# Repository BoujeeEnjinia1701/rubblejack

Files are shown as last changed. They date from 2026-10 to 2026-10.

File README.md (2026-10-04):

# RubbleJack

     

**Area:** Situational field hardware · **TRL:** 3 of 9 (proof of concept on paper) · **Value-engineering target:** about $3,500 USD (estimated cost of the constructable design about $5,895 USD) · **Difficulty:** 4 of 5

Turns commodity construction hydraulics into an open spreading, lifting and cutting kit for crews without powered rescue tools.

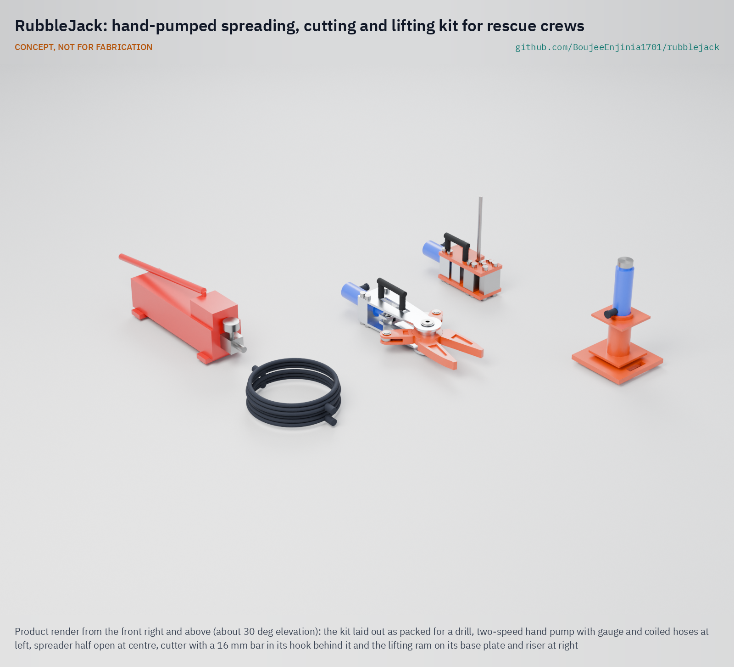
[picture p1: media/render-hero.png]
RubbleJack: hand-pumped spreading, cutting and lifting kit for rescue crews, product render


[Exploded render](media/render-exploded.png) · [Detail render](media/render-detail.png) · [Interactive 3D model](media/viewer.html) · [Concept blueprint (PDF)](media/concept-blueprint.pdf) · [General arrangement (PDF)](cad/drawings/RBJ-DWG-001.pdf) · [Calculations](docs/04-calcs/01-sizing.md) · [Prototype build plan](docs/05-build-plan.md) · [Design decisions](docs/06-design-decisions.md) · [Review note](docs/REVIEW.md)

> **Not certified rescue equipment.** RubbleJack is a TRL 3 concept, not released for fabrication, and not certified to NFPA 1936, NFPA 1960 or EN 13204. See [Safety](#safety).

## Concept rationale

The tools that lift, spread and cut are hydraulic, and the hydraulic parts are the same ones construction and body shops use every day: hand pumps, hoses, rams and standard cylinders. RubbleJack packages commodity construction hydraulics into an open rescue kit: a hand pump, hoses, a lifting ram, and spreader and cutter jaws built onto standard cylinders. A volunteer crew carries it to a collapse and pumps by hand to spread, lift and cut debris off trapped people.

Keeping it open and commodity-based matters because the crews who reach people first are the least equipped. Branded rescue sets are certified and expensive; commodity parts are sold in every town and can be replaced locally. Publishing the jaws, the proof-load data and the limits openly lets crews build, test and repair the kit, and lets them know exactly what it is and is not rated for.

## Burning platform

A review of international search and rescue deployments found that most people rescued after earthquakes are rescued locally, often by relatives and neighbours ([Rom and Kelman, 2020](https://pmc.ncbi.nlm.nih.gov/articles/PMC7745699/)). After the February 2023 earthquake in Turkey, residents dug by hand; in Antakya a woman trying to reach her mother said that if only they could lift the concrete slab they would be able to reach her ([Euronews, 2023](https://www.euronews.com/2023/02/07/we-could-hear-their-voices-digging-with-bare-hands-for-earthquake-survivors)). After the March 2025 earthquake in Myanmar, rescuers in Mandalay said the lack of proper equipment left people trapped and borrowed machinery from private businesses ([Al Jazeera, 2025](https://www.aljazeera.com/news/2025/3/29/lack-of-equipment-stalls-race-to-save-earthquake-survivors-in-myanmar)).

Cost keeps powered tools away from small crews. In Texas, a rural volunteer fire department needed a USD 14,900 state grant to buy three rescue tools ([Texas A&M Forest Service, 2017](https://tfsweb.tamu.edu/?p=12405)). A single battery spreader weighs about 19.5 kg ([Holmatro](https://www.holmatro.com/en/rescue/spreader-psp40)), and even a used hand-pump spreader and cutter sold as a demonstrator for USD 2,595 against a list price of USD 4,988 ([Fenton Fire](https://www.fentonfire.com/equipment/holmatro-hct-3120-hand-pump-spreader-cutter-a1758/)).

## Where it could be used

### By industry

| Industry | Use |
| --- | --- |
| Volunteer and rural fire services | Low-cost spreading, lifting and cutting for collapses and vehicle incidents |
| Community disaster response teams | Neighbourhood kit for the first hours after an earthquake |
| Humanitarian and disaster NGOs | Prepositioned kits and training in earthquake-prone regions |
| Construction and demolition | Freeing workers trapped by collapsed formwork or masonry |
| Mining and quarrying | Lifting and spreading after small rock and structure falls |

### By country or region

| Country or region | Why it matters there |
| --- | --- |
| Turkey | After the 2023 earthquake, families dug with their hands and could not lift slabs to reach trapped relatives ([Euronews, 2023](https://www.euronews.com/2023/02/07/we-could-hear-their-voices-digging-with-bare-hands-for-earthquake-survivors)). |
| Myanmar | Rescue teams in Mandalay reported a lack of proper equipment after the March 2025 earthquake ([Al Jazeera, 2025](https://www.aljazeera.com/news/2025/3/29/lack-of-equipment-stalls-race-to-save-earthquake-survivors-in-myanmar)). |
| United States (rural) | A rural Texas volunteer department relied on a USD 14,900 grant for three rescue tools ([Texas A&M Forest Service, 2017](https://tfsweb.tamu.edu/?p=12405)). |
| Global (earthquake regions) | Most people rescued after earthquakes are rescued locally by relatives and neighbours, not by international teams ([Rom and Kelman, 2020](https://pmc.ncbi.nlm.nih.gov/articles/PMC7745699/)). |

## What sparked the idea

The idea came from reporting after the February 2023 earthquake in Turkey. In Nurdag, a resident said they could hear trapped people's voices calling for help, and in Antakya a woman searching for her elderly mother said that if only they could lift the concrete slab they would be able to reach her ([Euronews, 2023](https://www.euronews.com/2023/02/07/we-could-hear-their-voices-digging-with-bare-hands-for-earthquake-survivors)). The people on the spot had the will and the numbers. What they lacked was a way to move a slab. The hydraulics that can move it are sold in every hardware and body shop.

## Problem

After a building collapse, most trapped people are reached by neighbours and local crews long before specialist teams arrive, but those crews usually have no way to lift, spread or cut concrete. Powered rescue tools cost more than many volunteer departments can pay.

Full problem statement: [docs/01-problem.md](docs/01-problem.md)

## Concept

A rescue kit built from commodity construction hydraulics that a volunteer crew carries to a collapse and pumps by hand to spread, lift and cut debris off trapped people. One two-speed 700 bar hand pump drives three tools, each on its own bought 15 t cylinder, so a tool change is one hose coupler swap:

- **Spreader:** two steel jaw arms on one pin, opened by a crosshead and two links; 49 to 64 kN between the tips, 262 mm opening.
- **Cutter:** a guillotine shear with hardened blades and a hook for the bar; shears 16 mm reinforcing bar, which needs about 105 kN of the cylinder's 142 kN.
- **Lifting ram:** 14.5 t on a 250 mm base plate, 527 mm reach with its riser, always on hardwood cribbing.

The kit packs into four loads of 15.9, 24.8, 22.0 and 23.7 kg. All figures are paper estimates at 700 bar from the calculation note.

Full design precis: [docs/02-concept.md](docs/02-concept.md) · Requirements: [docs/03-requirements.md](docs/03-requirements.md)

## Key components

- Two-speed hand pump, 700 bar, with gauge
- Two 2 m hoses with quick couplers
- Three single-acting 15 t cylinders, one per tool
- Spreader: collar adapter, aluminium frame plates, crosshead, links, two 4340 steel jaw arms, pins
- Cutter: collar adapter, steel plates with a hook, blade carrier, hardened moving and fixed blades, nose block, stop bar
- Lifting ram: high-strength steel base plate, riser block, tilting saddle
- Four carry bags

## Building the prototype

The [prototype build plan](docs/05-build-plan.md) shows how to make each of the eighteen made parts, with a making sketch for each, nine joint close-ups and sixteen assembly steps. The parts are waterjet or laser cut from plate, machined, and for the arms, pins and blades heat treated; the hydraulics are bought. Every tool is proof-loaded on CalRig and crack-checked before any use; the plan is a plan, not yet built.

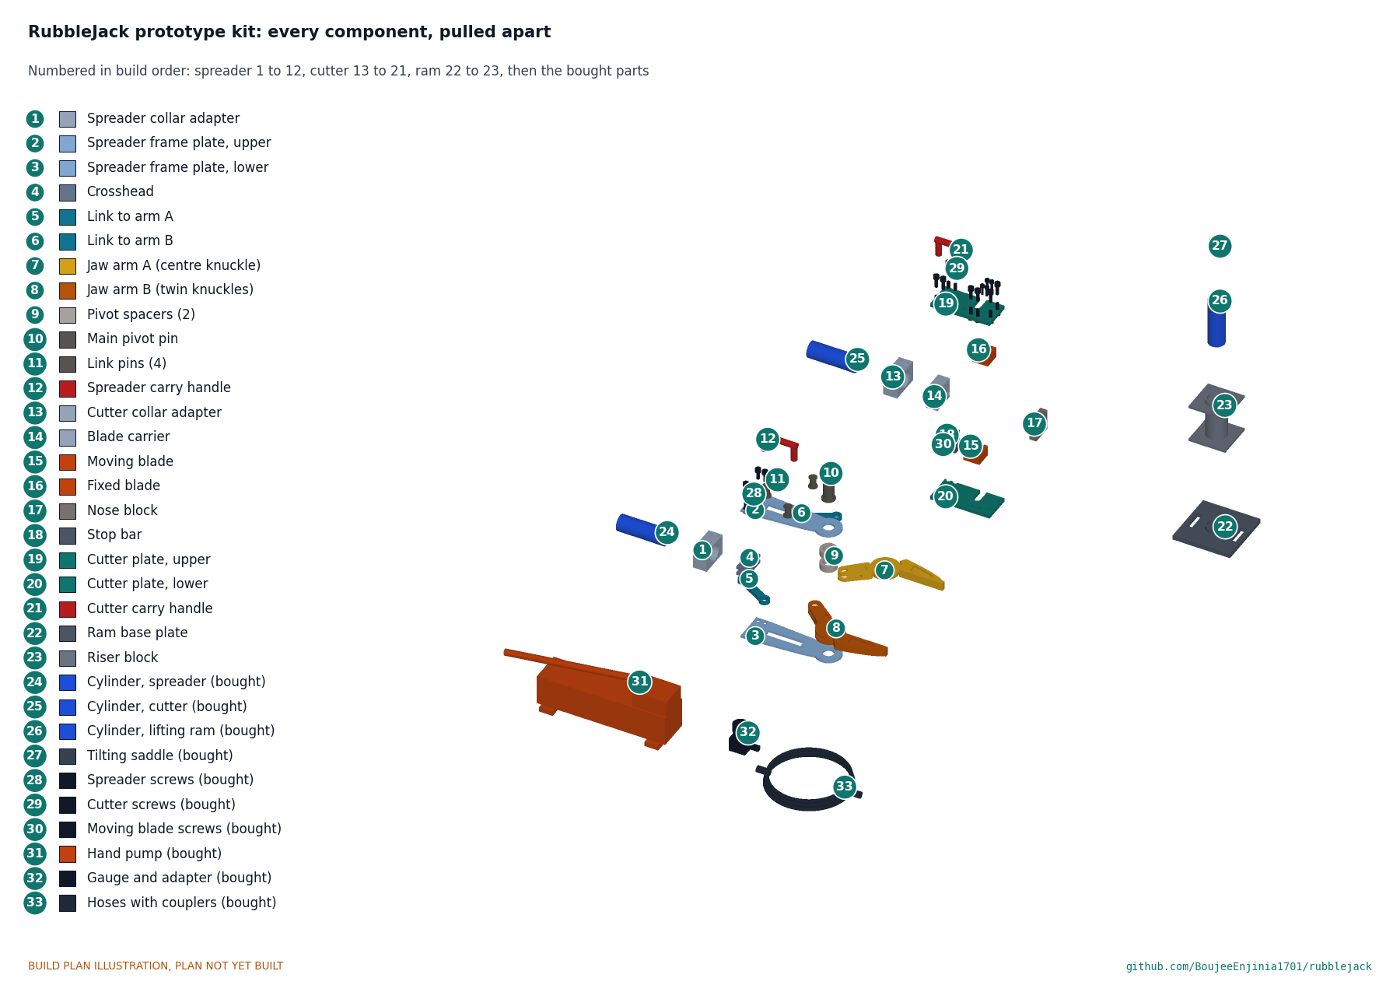
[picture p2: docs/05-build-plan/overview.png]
Every component of the kit, pulled apart and numbered in build order


## Safety

> Safety-critical: involves lifting, spreading and cutting with hydraulics at 700 bar and forces of 142 kN. Published as an open engineering reference, never as certified rescue equipment. Not for fabrication: this is a TRL 3 concept on paper.
>
> Hydraulic oil at high pressure can pierce skin; never feel for leaks by hand, and replace damaged hoses at once.
>
> Never work under a load held only by a ram. Crib the load as it rises and keep cribbing close. The ram's base plate always goes on hardwood sleepers, never on bare rubble, and the riser goes under the cylinder, never on the plunger.
>
> Collapsed structures can shift in aftershocks; use trained people and follow local incident command.
>
> Stay within the rated pressure shown on every part; the weakest part sets the limit.
>
> Wear eye and face protection when cutting or spreading; cut ends and fragments can fly. Cut only reinforcing bar of 16 mm or less.
>
> Every made tool must be proof-loaded and crack-checked before any use.
>
> This design is published as an open engineering reference. It is not certified equipment.

## Repository layout

| Folder | Contents |
| --- | --- |
| `docs/` | Problem, concept, requirements, calculations, build plan and design decisions |
| `cad/src/` | build123d Python source, the source of truth for all geometry |
| `cad/step/`, `cad/stl/` | Exported models for FreeCAD, other CAD tools and printing |
| `cad/drawings/` | 2D sketches and dimensioned drawings |
| `bom/` | Bill of materials |
| `electronics/` | KiCad schematics and PCB layouts |
| `firmware/` | Microcontroller code |
| `media/` | Renders, perspectives and photos |
| `build-log/` | Dated prototyping notes |

## Documentation

Controlled documents follow the portfolio [documentation standard](.kit/STANDARDS.md). Each carries a document ID (RBJ-PRC-001 for the precis), a version and a revision history. Branded PDFs are built with `python .kit/render.py` and attached to GitHub Releases when a document is tagged, for example `RBJ-PRC-001/v1.0`.

## Credits

Designed by Amish Chadha at Design Molecule Labs. See [CONTRIBUTORS.md](CONTRIBUTORS.md) for roles. To cite this design, use [CITATION.cff](CITATION.cff) (GitHub shows it as "Cite this repository").

AI assistance (Claude) was used to accelerate prototype documentation and first-pass research. Design direction and all decisions are Amish Chadha's, recorded in this repository's decision records (`docs/decisions/`).

## Licenses

- **Hardware** (CAD, drawings, BOM, electronics): [CERN-OHL-S v2](LICENSE)
- **Software** (firmware, scripts, notebooks): [MIT](LICENSE-SOFTWARE)

A project of the [Design Molecule](https://designmolecule.com) lab.

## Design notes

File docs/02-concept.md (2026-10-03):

---
doc_id: RBJ-PRC-001
title: RubbleJack design precis
project: RubbleJack
doc_type: Precis
version: "0.3"
status: Draft
date: '2026-10-03'
author: Amish Chadha
license: CERN-OHL-S-2.0
revisions:
- version: "0.1"
  date: '2026-09-30'
  author: Amish Chadha
  change: Initial scaffold
- version: "0.2"
  date: '2026-10-03'
  author: Amish Chadha
  change: Populated to TRL 2 with how it works, components, key design choices (RBJ-DDR-001), first-order numbers, safety and concept media
- version: "0.3"
  date: '2026-10-03'
  author: Amish Chadha
  change: TRL 3; numbers from RBJ-CAL-001 and the constructable design (RBJ-DDR-002); media regenerated from the model
---

# RubbleJack design precis

Turns commodity construction hydraulics into an open spreading, lifting and cutting kit for crews without powered rescue tools.

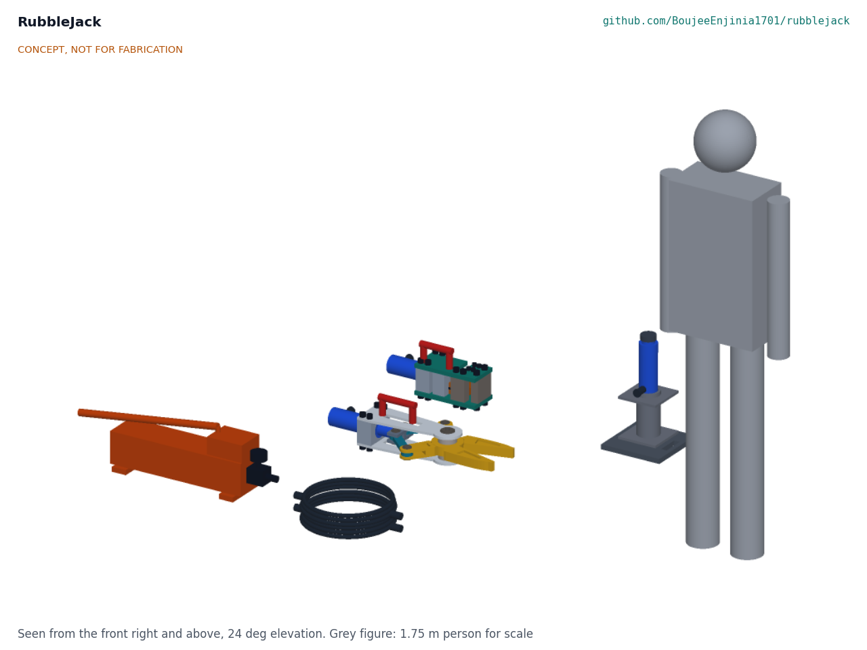
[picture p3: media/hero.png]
Figure 1. The RubbleJack kit laid out as packed for a drill, with a 1.75 m person for scale


*Figure 1. The kit as packed for a drill: hand pump with gauge and hoses, spreader, cutter and lifting ram set. CONCEPT, NOT FOR FABRICATION.*

> **Safety:** RubbleJack is safety-critical. It lifts and spreads loads of up to 142 kN (14.5 t) with oil at 700 bar (10,000 psi), in collapsed structures that can move. It is published as an open engineering reference, never as certified rescue equipment, and it is not certified to NFPA 1936, NFPA 1960 or EN 13204. See the Safety section below before reading further.

## How it works

One person works a two-speed hand pump; a 2 m hose with quick couplers carries oil at up to 700 bar to whichever tool is connected. Each of the three tools has its own bought 15 t, 101 mm stroke single-acting cylinder, so changing tools means only uncoupling one hose and coupling another (RBJ-DDR-001, D2):

- **Spreader.** The cylinder pushes a crosshead forward; two links push the tails of two jaw arms that turn on one pivot pin, so the jaw tips open from 32 mm to 262 mm with 49 to 64 kN between them. The arms are held between two aluminium frame plates that bolt to a collar adapter screwed onto the cylinder's collar thread.
- **Cutter.** The cylinder pushes a moving blade past a fixed blade, like a guillotine. The bar lies in a hook cut in two steel plates and in a U notch in each blade; the 142 kN of the cylinder shears 16 mm reinforcing bar, which needs about 105 kN. A stop bar ends the stroke after the cut.
- **Lifting ram.** The third cylinder stands in a ring on a 250 mm steel base plate, with a tilting saddle on its plunger. A 150 mm riser block can go under it, never on top of the plunger, for 527 mm of reach. The crew cribs the load with hardwood as it rises.

The gauge on the pump outlet shows the working pressure; the pump's internal relief valve stops at 700 bar. The cylinders retract by their own springs when the pump's release valve is opened, so the spreader and cutter have no powered closing force.

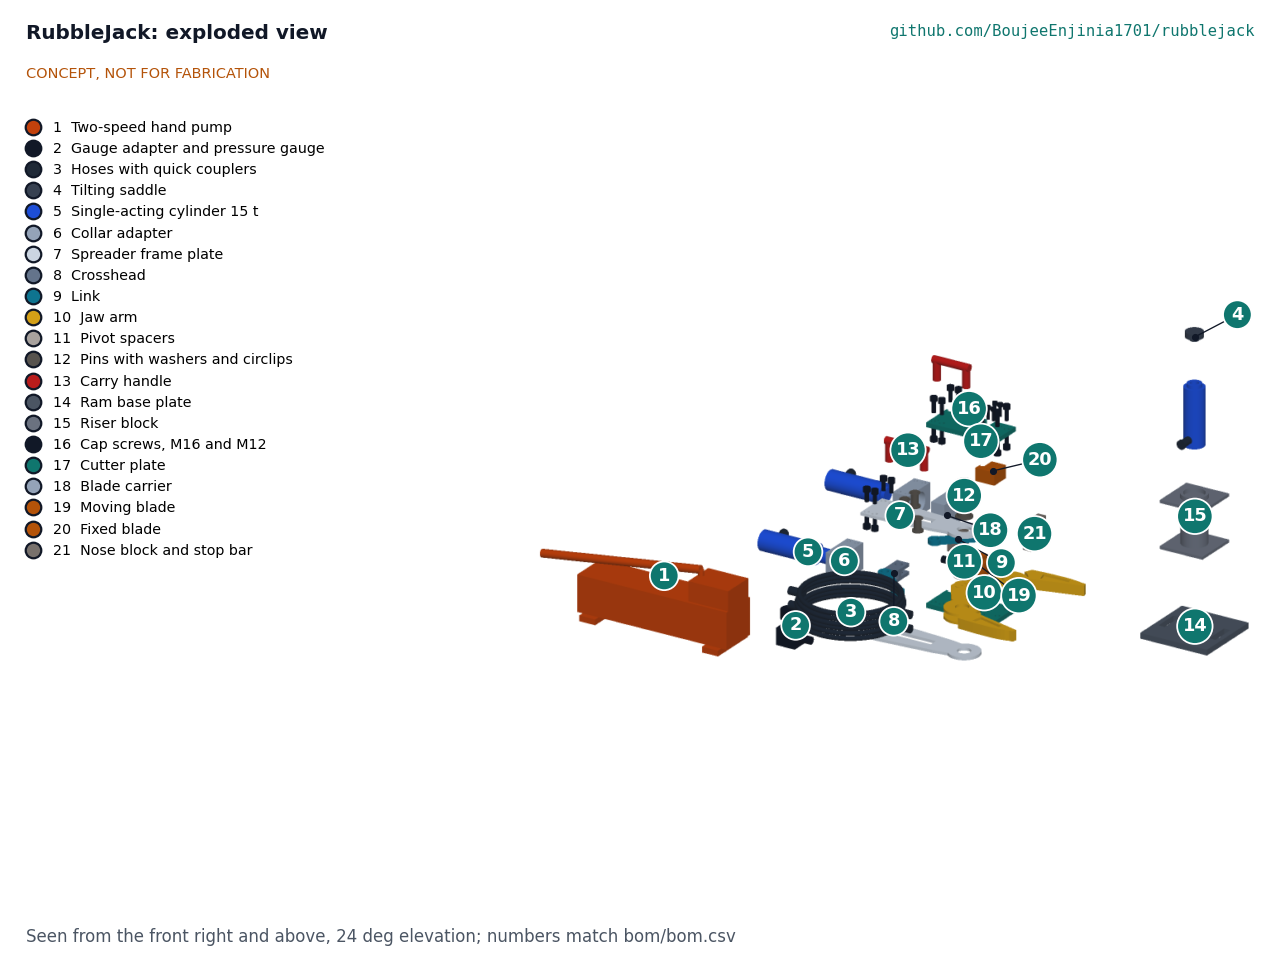
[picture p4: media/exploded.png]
Figure 2. Exploded view with numbered callouts matching bom/bom.csv


*Figure 2. Exploded view; numbers match the BOM lines in Table 1.*

## Components

*Table 1. Main components (numbers match bom/bom.csv and Figure 2).*

| # | Component | Role | Made or bought |
| --- | --- | --- | --- |
| 1 | Two-speed hand pump, 700 bar | Powers every tool; fast stage at low load, slow stage at high pressure | Bought |
| 2 | Gauge adapter and gauge | Shows working pressure on the pump outlet | Bought |
| 3 | Hoses, 2 m, with quick couplers | Connect the pump to any tool without tools | Bought |
| 4 | Tilting saddle | Spreads the ram's push on an uneven load | Bought |
| 5 | Single-acting cylinder, 15 t (three) | One per tool | Bought |
| 6 | Collar adapter (two) | Joins a tool's frame plates to its cylinder's collar thread | Made, 7075-T6 |
| 7 | Spreader frame plates (two) | Carry the pivot pin and the reaction back to the adapter | Made, 7075-T6 10 mm |
| 8 | Crosshead | Turns the plunger's push into two link pushes | Made, 7075-T6 |
| 9 | Links (two) | Push the jaw arm tails | Made, S690QL |
| 10 | Jaw arms (two) | Spread the load at the tips | Made, 4340 quenched and tempered |
| 11 | Pivot spacers (two) | Fill the gap between arms and plates | Made, 7075-T6 |
| 12 | Pins | Main pivot pin and four link pins | Made, 4340 quenched and tempered |
| 13 | Carry handles (two) | One on the spreader, one on the cutter | Made, steel tube |
| 14 | Ram base plate | Spreads the ram's load on cribbing | Made, S690QL 20 mm |
| 15 | Riser block | Extends the ram's reach by 170 mm | Made, S355 tube and plate |
| 16, 24 | Cap screws, M16 and M12 | Hold every bolted joint | Bought |
| 17 | Cutter plates (two) | Hold the blades, nose and stop; the hook takes the bar | Made, S690QL 16 mm |
| 18 | Blade carrier | Carries the moving blade on the plunger | Made, 7075-T6 |
| 19, 20 | Moving and fixed blades | Shear the bar | Made, S7 tool steel, hardened |
| 21 | Nose block and stop bar | Take the fixed blade's thrust; end the cutter stroke | Made, 7075-T6 and S355 |
| 22 | M24 studs | Hold the crosshead and carrier on their plungers | Bought |
| 23 | Carry bags (four) | One bag a load | Bought |

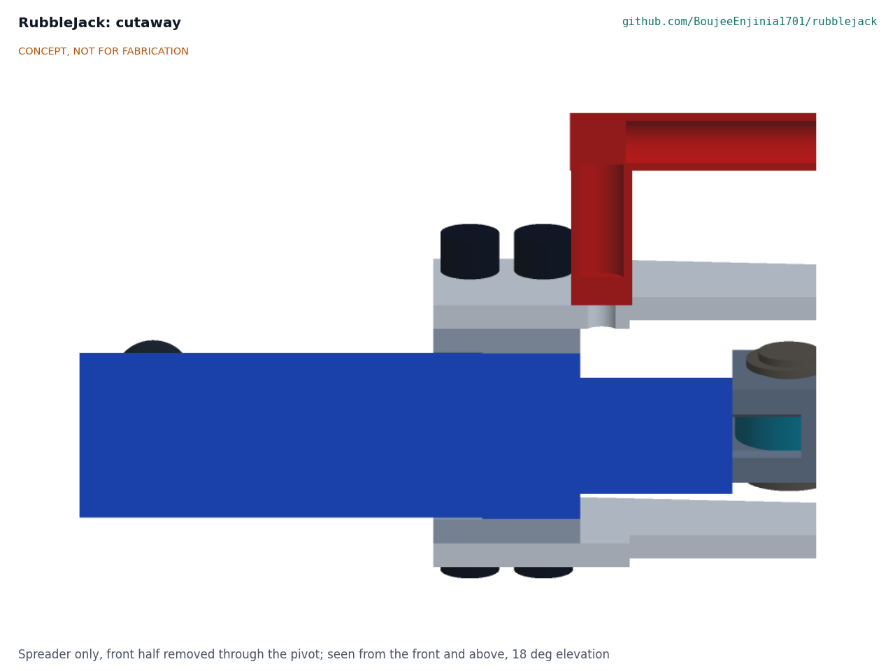
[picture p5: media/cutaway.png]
Figure 3. Cutaway through the spreader's pivot stack


*Figure 3. Cutaway of the spreader, front half removed: frame plates, spacers, interleaved jaw arm knuckles and the main pin.*

## Key design choices

All are decided under Amish's 2026-10-03 pre-approval and recorded in RBJ-DDR-001 and RBJ-DDR-002; the register is RBJ-DEC-001.

- **Commodity 700 bar hydraulics** (D1): the most widely stocked hand hydraulic class; at least two makers offer every bought part.
- **One cylinder per tool** (D2): a tool change is a coupler swap of about 20 s, at the cost of two extra cylinders.
- **Linkage spreader and guillotine cutter** (D3, D4): pinned plate parts a local workshop can make; the cutter is rated for 16 mm bar only.
- **Located ram stack** (D5): base ring, riser spigot and saddle, so nothing stacked can slide; never a riser on the plunger.
- **Strength rule** (D7): every made load-bearing part at least 1.5 on yield at 700 bar; the lowest is the jaw arm tail at the link slot, 1.60.
- **Four loads under 25 kg** (D10): high-strength steel where sections are small and 7075-T6 aluminium where parts are bulky.

## First-order numbers

All at the pump's 700 bar relief pressure, from RBJ-CAL-001; first-principles paper estimates, nothing measured.

*Table 2. Key figures.*

| Quantity | Value | Assumption |
| --- | --- | --- |
| Force per cylinder | 142 kN (14.5 t) | 20.3 cm² effective area at 700 bar |
| Spreading force at the tips | 49 kN closed to 64 kN fully open | Pin friction ignored; linkage geometry from the model |
| Tip opening | 32 mm closed, 262 mm open | 101 mm stroke |
| Force to shear 16 mm bar | About 105 kN; ratio 1.36 to the cylinder | Shear strength 0.8 of a 650 MPa tensile strength (upper bound for B500B and A615 grade 60) |
| Ram reach | 256 mm closed, 357 mm open, 527 mm on the riser | Saddle included |
| Pump strokes, full stroke under load | About 228 slow-stage strokes, 9 min | 0.9 cm³ a stroke, 25 strokes a minute (estimate) |
| Pump strokes, one cut | About 41, under 2 min | 37 cm³ to close the cut (estimate) |
| Loads, packed | Pump set 15.9 kg, spreader 24.8 kg, cutter 22.0 kg, ram set 23.7 kg | 0.8 kg bag each |
| Lowest strength margin | 1.60 (jaw arm tail) | Minimum yield values; conservative hand calculations |
| Cost | Value-engineering target: USD 3,500. Estimated cost of the constructable design: USD 5,895 (USD 2,395 over the target) | Indicative prices in bom/bom.csv |

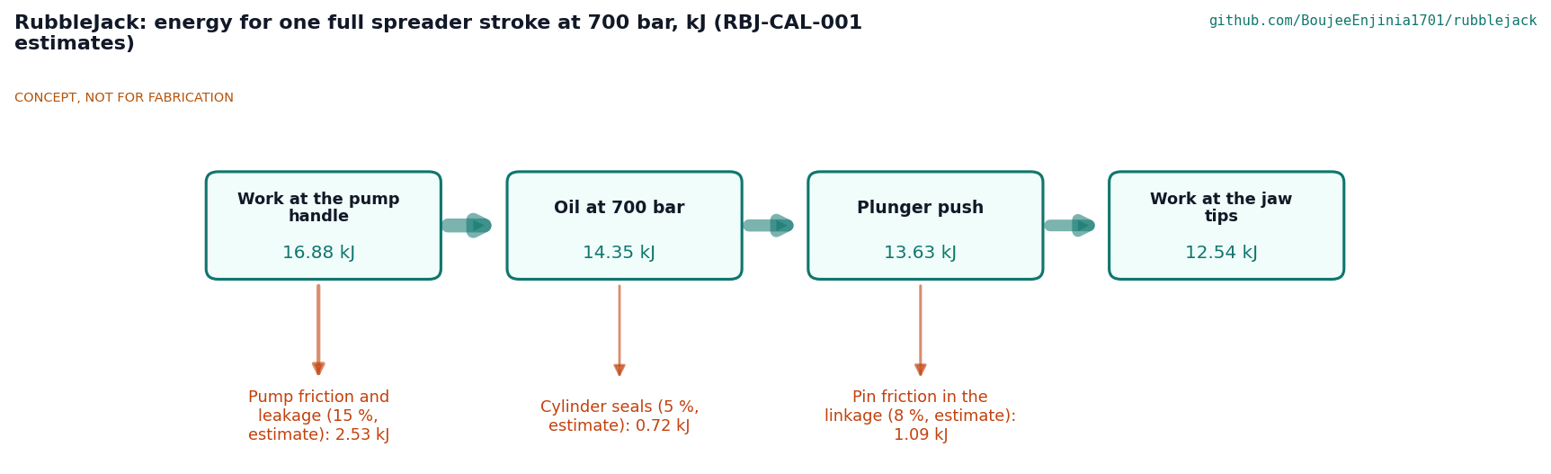
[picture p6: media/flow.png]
Figure 4. Energy for one full spreader stroke


*Figure 4. Energy for one full spreader stroke at 700 bar, from the pump handle to the jaw tips. All efficiencies are estimates.*

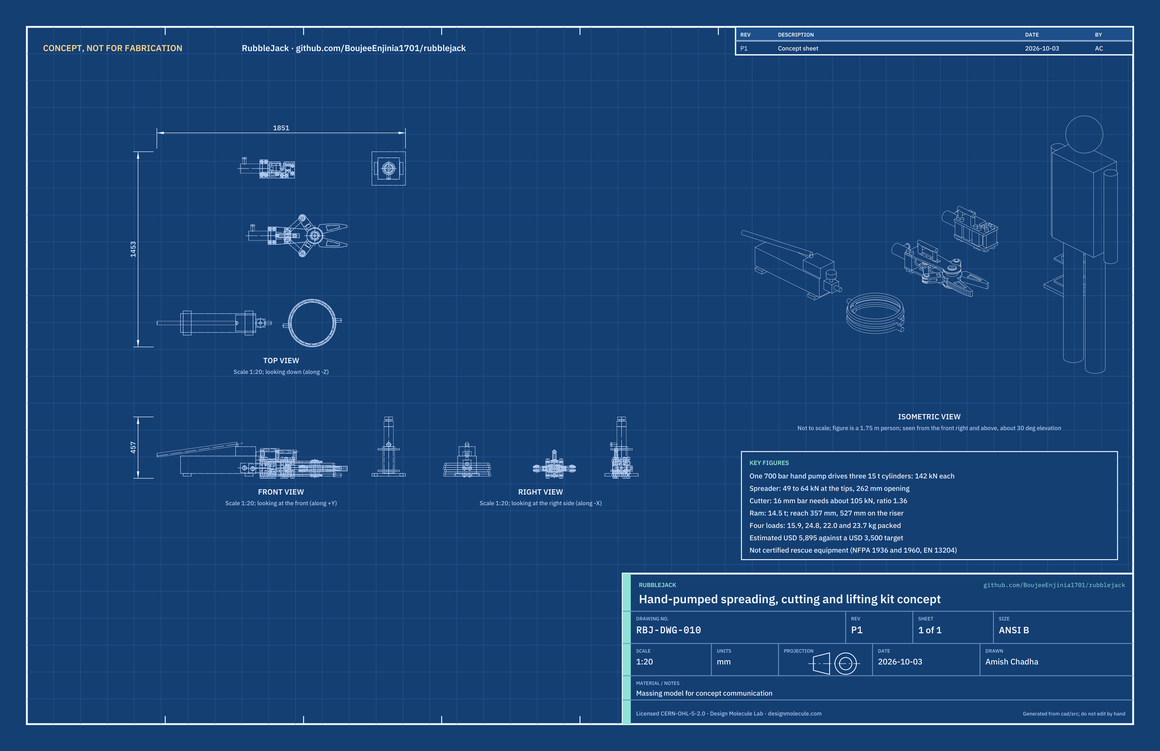
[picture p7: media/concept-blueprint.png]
Figure 5. Concept blueprint sheet RBJ-DWG-010


*Figure 5. Concept blueprint RBJ-DWG-010 with orthographic views and key figures.*

## Patent design-arounds

From the preliminary patent, trademark and prior-art screen (not legal advice), kept as scaffolded:

- Use a commodity pump only, not a compact integrated pump unit (US11273547, Weber). RubbleJack uses a separate catalogue hand pump and hoses.
- Avoid features of the Holmatro portfolio, including the CC 23 crusher and its hand pumps. RubbleJack has no crusher and no integrated pump.
- Publish proof-load data and a clear not-certified notice naming NFPA 1936, NFPA 1960 and EN 13204 (RBJ-DDR-001, D8).
- Interchangeable tools on one hydraulic supply draw on lapsed prior art (US7937838B2); RubbleJack goes further and gives each tool its own cylinder.

## Shared blocks

- Commodity hydraulics block: pump, hoses, couplers and gauge (adopted, RBJ-DDR-001, D13).
- CalRig: proof testing of the jaws, blades, ram stack and hoses at TRL 4.
- VoidScope: sibling project for searching the voids RubbleJack opens.

## Safety

> **Safety:** RubbleJack involves lifting, spreading and cutting with high-pressure hydraulics in unstable structures. It is not certified rescue equipment and must not be used on a real rescue on the strength of this document.

- **High-pressure oil.** Oil at 700 bar can pierce skin and cause injuries that need surgery. Never feel for leaks by hand; use card. Replace a damaged, kinked or abraded hose at once. Keep the gauge fitted; stop below 700 bar.
- **Lifting.** Never work under a load held only by a ram. Crib the load with hardwood as it rises and keep the cribbing within 25 mm of the load. Never lift on bare rubble; the base plate goes on hardwood sleepers. Never put the riser on top of the plunger.
- **Spreading and cutting.** Keep hands and bodies out of the jaws, the cutter hook and the line of any bar end. Cut bar ends and broken masonry can fly: eye and face protection for everyone near the tool. Cut only reinforcing bar of 16 mm or less, never hardened bar, chain, cable or springs.
- **Stored energy.** A spreading load or a bent bar holds energy; release the pump's valve slowly and stand clear of the line a load could move.
- **Structures.** Collapsed structures move in aftershocks. Use trained people, follow local incident command and shore before entering.
- **Weakest part.** Every part is rated for 700 bar; the pump's relief valve is the limit. Never fit a part rated below 700 bar. Each made tool is proof-loaded on CalRig and inspected for cracks before use (RBJ-DDR-001, D9).

## Open questions

None. The questions from the scaffold were settled at the TRL 2 review (RBJ-DDR-001) and in the calculations (RBJ-CAL-001); facts that need real parts are listed in the design decisions register (RBJ-DEC-001) under "To confirm when parts are bought".

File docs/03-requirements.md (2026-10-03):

---
doc_id: RBJ-REQ-001
title: RubbleJack requirements
project: RubbleJack
doc_type: Requirements
version: "0.3"
status: Draft
date: '2026-10-03'
author: Amish Chadha
license: CERN-OHL-S-2.0
revisions:
- version: "0.1"
  date: '2026-09-30'
  author: Amish Chadha
  change: Initial scaffold
- version: "0.2"
  date: '2026-10-03'
  author: Amish Chadha
  change: TRL 2; targets made measurable, R11 (strength margin) and R12 (cribbing) added from RBJ-DDR-001, cost requirement stated against the value-engineering target
- version: "0.3"
  date: '2026-10-03'
  author: Amish Chadha
  change: TRL 3 status of every requirement from RBJ-CAL-001 and the constructable design
---

# RubbleJack requirements

Every requirement is checked on paper at TRL 3 in RBJ-CAL-001; the status column gives the result. Measured verification is TRL 4 work. All requirements apply at the pump's 700 bar relief pressure, the highest pressure any part can see.

> **Safety:** These are design targets for a safety-critical kit. Meeting them on paper does not make the kit safe to use. Every tool must be proof-loaded and inspected before any use, and the kit is not certified to NFPA 1936, NFPA 1960 or EN 13204.

*Table 1. Requirements and their TRL 3 status.*

| ID | Requirement | Target | Verification (TRL 4 or later) | TRL 3 result (RBJ-CAL-001) | Status |
| --- | --- | --- | --- | --- | --- |
| R1 | Lifting capacity | Lift at least 10 t (22,000 lb) with the ram | CalRig proof load at 1.5 times rated load | 14.5 t at 700 bar; cylinder rated 15 t | Met on paper |
| R2 | Spreading force | At least 40 kN (9,000 lbf) between the jaw tips over the whole opening | Load cell between the tips at five openings | 48.6 kN closed to 64.1 kN open | Met on paper |
| R3 | Spreading opening | At least 250 mm (10 in) of tip opening | Measurement | 262 mm open; tips 32 mm thick closed | Met on paper |
| R4 | Cutting | Cut 16 mm (5/8 in) steel reinforcing bar, B500B or ASTM A615 grade 60 | Cut test on sample bar | About 105 kN needed, 142 kN available, ratio 1.36 | Met on paper |
| R5 | Pressure safety | Every pressurised part rated at or above the 700 bar relief; hoses at least 4 to 1 burst to working | Parts rating review and relief valve test | All parts specified at 700 bar; hoses 2,800 bar burst | Met by specification; ratings to confirm when parts are bought |
| R6 | Portable | No single packed load over 25 kg (55 lb) | Weigh each packed load | 15.9, 24.8, 22.0 and 23.7 kg | Met on paper; the spreader has 0.2 kg in hand |
| R7 | Fast setup | Pump connected and a tool working within 3 minutes of arrival | Timed drill | Two coupler connections, no tools; estimated 1 to 2 min | Met on paper |
| R8 | Tool change | Swap between spreader, cutter and ram in under 1 minute | Timed changeover | One coupler off and one on, about 20 s | Met by design |
| R9 | Commodity parts | Pump, hoses, couplers, gauge and cylinders all standard catalogue parts from at least two suppliers | BOM review | All in a class at least two makers offer | Met by specification |
| R10 | Value engineering | Estimated cost reported against the USD 3,500 value-engineering target | Costed BOM | USD 5,895 | Over the value-engineering target by USD 2,395 |
| R11 | Strength margin | Every made load-bearing part at least 1.5 on minimum yield at 700 bar | Strain-gauged proof load on CalRig | Lowest 1.60, the jaw arm tail at the link slot | Met on paper |
| R12 | Lifting on cribbing | The ram never lifts on bare rubble: base plate on hardwood cribbing; ground bearing under the sleepers 1 MPa or less | Drill with the co-design partner | 0.79 MPa on three 100 mm sleepers 600 mm long | Met by design and procedure |

## Requirements not met

None fails on paper. R10 is reported against the value-engineering target, not as a failure: the estimate is USD 2,395 over it, mainly because each tool has its own cylinder and the made parts use high-strength steel (RBJ-DEC-001, Value engineering). R6 is met with little margin on the spreader (0.2 kg).

## Assumptions

- Commodity 700 bar hand pumps and 15 t cylinders are available in target regions from at least two makers (checked against catalogues, not against regional stock).
- Local workshops can waterjet or laser cut, machine and have parts heat-treated to the stated hardness.
- Crews use hardwood cribbing, which is widely available, and receive basic training with the kit.
- Strength figures use minimum catalogue yield values and conservative hand calculations; proof loads at TRL 4 confirm them.

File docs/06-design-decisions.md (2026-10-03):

---
doc_id: RBJ-DEC-001
title: RubbleJack design decisions register
project: RubbleJack
doc_type: Design decisions register
version: "0.1"
status: Draft
date: '2026-10-03'
author: Amish Chadha
license: CERN-OHL-S-2.0
revisions:
- version: "0.1"
  date: '2026-10-03'
  author: Amish Chadha
  change: Register opened at TRL 3; every decision made under Amish's 2026-10-03 pre-approval
---

# RubbleJack design decisions register

Every design decision made, and everything still to confirm, in one place. Each decision is argued in full in its decision record under `docs/decisions/`; this register is the index Amish works from. The build plan (`docs/05-build-plan.md`) describes the design as it stands.

> **Safety:** RubbleJack is a safety-critical lifting, spreading and cutting kit working at 700 bar. Every decision that touches safety took the conservative option, and the evidence that would relax it is named in its record. Nothing here makes the kit certified rescue equipment.

## Open decisions

None. All decisions were made under Amish's 2026-10-03 pre-approval.

## To confirm when parts are bought

| # | What to confirm | Why it matters | Source |
| --- | --- | --- | --- |
| 1 | The cylinder's collar thread size and length, and that the maker allows the full 15 t through the collar thread | The collar adapters are cut to match it; the spreader and cutter react their whole force through it | RBJ-DDR-002, C1 |
| 2 | The plunger's attachment thread, and that the plunger turns freely in the cylinder | Sets the stud size for the crosshead and carrier; the tools rely on the links and plates to set the plunger's angle | RBJ-DDR-002, C11 |
| 3 | The cylinder's collapsed length (216 mm assumed), stroke and effective area | Set the spreader linkage geometry, the frame plate length and every force | RBJ-CAL-001, A and B |
| 4 | Hose burst rating at least 4 to 1 and all couplers of one series | R5; couplers of mixed series may not seal or lock | RBJ-CAL-001, A |
| 5 | Pump stage volumes, relief setting and handle effort | Stroke counts and times in RBJ-CAL-001, F; the 700 bar limit | RBJ-CAL-001, F |
| 6 | Mill certificates for S690QL and 7075-T6 plate, and hardness after heat treatment of the 4340 and S7 parts | Every strength margin uses minimum yield values | RBJ-CAL-001, C to E |

## Value engineering

Value-engineering target: USD 3,500 (a hypothetical control target, not a limit). Estimated cost of the constructable design: USD 5,895 (USD 2,395 over the target). Made parts are about USD 3,030 and bought parts about USD 2,865. Main cost drivers and savings worth trying:

- The three cylinders (USD 1,260) are the largest line. One cylinder per tool (D2) costs USD 840 more than a single shared cylinder; sharing one cylinder with heads screwed onto its collar would save that, at the cost of a slower tool change (over 1 minute, so R8 would be missed) and threads exposed to dust.
- The two jaw arms (USD 900) are machined from quenched and tempered 4340 plate. Waterjet cutting of pre-hardened plate with only the bores and knuckles machined is the saving worth pricing first.
- The pump (USD 650), the hoses (USD 420) and the S7 blades (USD 440 the pair) follow. Prices are indicative; local workshops in the first candidate region may be much cheaper for the made parts, and a second quote should be sought before TRL 4.
- Design for construction added the M12 screws (line 24) and raised the base plate to 20 mm high-strength steel; together about USD 30.

## Decisions made

| Date | Decision | Decided by | Record |
| --- | --- | --- | --- |
| 2026-10-03 | TRL 2 review items D1 to D14: commodity 700 bar hydraulics, one 15 t cylinder per tool, linkage spreader, guillotine cutter rated for 16 mm bar, located ram stack, materials, the 1.5 on yield strength rule (R11), not-certified notice, proof load before use, four carried loads, required cribbing (R12), shared blocks, gauge always fitted | Amish: "start with the first 14 repos from the list of 29 projects. I pre-approve the batch runs along with any recommendations you come up with. I also accept any cost overruns or variations from the assumed scope cost." | [RBJ-DDR-001](decisions/0001-trl2-review-decisions.md) |
| 2026-10-03 | Co-design: the first candidate partner to approach is a volunteer search and rescue association in southern Turkey (AKUT first), in the region hit in February 2023; a first candidate, not agreed | Amish, same pre-approval | [RBJ-DDR-001](decisions/0001-trl2-review-decisions.md), D12 |
| 2026-10-03 | Design for construction C1 to C14: collar adapters, 10 mm frame plates, interleaved pivot, 4340 pins, link slot from 100 mm, stop bar with two screws in each plate, M12 fixed blade screws, 20 mm S690QL base plate, 88.9 mm riser tube, locating rings and spigot, stud-mounted crosshead and carrier, shear layout, lightening pockets, bolted handles | Amish, same pre-approval | [RBJ-DDR-002](decisions/0002-design-for-construction.md) |
| 2026-10-03 | Cost overrun against the value-engineering target accepted; `budget_usd` left at USD 3,500 | Amish, same pre-approval ("I also accept any cost overruns") | This register, Value engineering |

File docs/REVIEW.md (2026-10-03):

# Review note: RubbleJack

## Session 2026-09-30: scaffolded

### What was done

- Repository created from kit 1.6.0 at TRL 1, target TRL 2.
- `docs/01-problem.md` (RBJ-PRB-001 v0.1): problem with cited evidence, users, environment, constraints, prior work, open questions.
- `docs/02-concept.md` (RBJ-PRC-001 v0.1): how it works, components, patent design-arounds, shared blocks, safety.
- `docs/03-requirements.md` (RBJ-REQ-001 v0.1): 10 proposed requirements.
- `README.md` with concept rationale, burning platform, where it could be used, and what sparked the idea.

## Session 2026-10-03: TRL 2 (populate)

Run as the first half of the TRL 3 path (`/to-trl3`) on kit 1.7.0, under Amish's pre-approval of 2026-10-03: "start with the first 14 repos from the list of 29 projects. I pre-approve the batch runs along with any recommendations you come up with. I also accept any cost overruns or variations from the assumed scope cost." That go counts as the TRL 2 approval.

### What was done

- Kit 1.7.0 installed (`.kit/`, `.claude/commands/`, root `CLAUDE.md`); `.kit/PHASE.yaml` kept as installed.
- `docs/01-problem.md` (RBJ-PRB-001 v0.2): budget stated as a value-engineering target, co-design candidate and checklist, open questions answered, safety note.
- `docs/03-requirements.md` (RBJ-REQ-001 v0.2): measurable targets; R11 (1.5 on yield at 700 bar) and R12 (lift only on cribbing) added.
- `docs/02-concept.md` (RBJ-PRC-001 v0.2): how it works, components with BOM numbers, key design choices, first-order numbers, safety section.
- `docs/decisions/0001-trl2-review-decisions.md` (RBJ-DDR-001): TRL 2 review decisions D1 to D14.
- Concept media from `cad/src/concept_media.py`: `media/hero.png`, `media/concept-blueprint.png` and `.pdf` (RBJ-DWG-010), `media/model.glb` and `media/viewer.html`, `media/cutaway.png` (spreader pivot), `media/exploded.png` (BOM callouts), `media/flow.png` (energy for one spreader stroke, estimates). The media were drawn from the constructable model (below), not a separate massing model.
- `bom/bom.csv`: every line with a specification and indicative price.

### Results

- Concept: one 700 bar two-speed hand pump drives three tools, each on its own 15 t cylinder, so a tool change is a coupler swap (R8).
- First-order numbers were confirmed by the TRL 3 calculations below.

### Requirements not met

None at TRL 2; see TRL 3.

### Decisions made under the pre-approval

D1 to D14 in RBJ-DDR-001 (commodity 700 bar class, one cylinder per tool, linkage spreader, guillotine cutter rated 16 mm, located ram stack, materials, strength rule R11, not-certified notice, proof load before use, four loads, cribbing required, co-design first candidate, shared blocks, gauge always fitted).

### Safety concerns

Lifting, spreading, cutting and 700 bar oil; see TRL 3.

## Session 2026-10-03: TRL 3 (advance and build plan)

### What was done

- **Model.** `cad/src/model.py`: the constructable design, with 228 constructability checks (all pass). The pending edits from the interrupted run were made: spreader frame plates 12 mm to 10 mm, and two screws in each plate for the cutter stop bar (stop bar lengthened from 30 to 60 mm). Further changes found by the calculations and checks are in the list below. STEP and STL: `cad/step/rubblejack-{kit,spreader,cutter,ram}.step`, `cad/stl/` the same.
- **Calculations.** RBJ-CAL-001: `docs/04-calcs/01-sizing.md`, `docs/04-calcs/sizing.py`, `docs/04-calcs/results.csv`.
- **Drawing.** General arrangement RBJ-DWG-001 Rev P1 from `cad/src/sheets.py` (SVG, PDF, PNG).
- **BOM.** `bom/bom.csv`, 24 lines, every unit cost filled, a supplier class for each.
- **Concept media** refreshed from the model (as at TRL 2).
- **Build plan.** `cad/src/build_plan_media.py`: overview, 18 making sketches (RBJ-DWG-101 to 118), 9 joint close-ups and 16 step pictures; `docs/05-build-plan.md` (RBJ-BLD-001); `docs/decisions/0002-design-for-construction.md` (RBJ-DDR-002); `docs/06-design-decisions.md` (RBJ-DEC-001).
- **Appearance model.** `cad/src/product_model.py` (`product_parts()`, `TITLE`, `RENDER_VIEWS` hero, exploded and detail) on the constructable components, with a 1.75 m `mannequin()` for scale; scenes exported with `.kit/export_views.py` to `/home/claude/renders/rubblejack` for the photoreal render on Amish's Mac. The README leads with `media/render-hero.png`, which will exist after that render.
- `project.yaml`: trl 3, trl_target 3, `design_state: constructable`, trl_evidence listed; `budget_usd` unchanged at 3,500. README updated (TRL 3, renders, links, Building the prototype, Safety).

### Results

*Table 1. Key results at 700 bar (RBJ-CAL-001).*

| Quantity | Result |
| --- | --- |
| Force per cylinder | 142 kN (14.5 t) |
| Spreader | 48.6 kN closed to 64.1 kN open between the tips; 262 mm opening; tips 32 mm thick |
| Cutter | 16 mm bar needs about 105 kN; ratio 1.36; largest bar at the upper strength 18.7 mm |
| Ram | 14.5 t; reach 357 mm, 527 mm on the riser; 0.79 MPa on three hardwood sleepers |
| Lowest strength margin | 1.60 on yield, jaw arm tail at the link slot; link pins 1.76; links 1.78 |
| Loads, packed | 15.9, 24.8, 22.0 and 23.7 kg (kit 86.4 kg) |
| Pump | About 228 slow strokes (9 min) for a full stroke under load; about 41 strokes for one cut |
| Cost | Value-engineering target: USD 3,500. Estimated cost of the constructable design: USD 5,895 (USD 2,395 over the target) |

### Requirements not met

None fails on paper. R10 is over the value-engineering target by USD 2,395 (accepted under the pre-approval). R6 is met with only 0.2 kg in hand on the spreader. R5 and R9 are met by specification and depend on ratings confirmed when parts are bought.

### Decisions made under the pre-approval

All dated 2026-10-03, decided by Amish with his quote above, recorded in RBJ-DEC-001:

- RBJ-DDR-001, D1 to D14 (TRL 2 review).
- RBJ-DDR-002, C1 to C14 (design for construction).
- Cost overrun accepted; `budget_usd` left unchanged.
- Appearance model: no geometric deviation from `model.py`; the colours and finish classes (painted orange steel tools, natural aluminium plates, blue cylinders, red pump, black hoses) are a chosen look, decided under the same pre-approval.

### Design changes made for construction (2026-10-03)

1. Spreader frame plates 10 mm instead of 12 mm 7075-T6 (pending edit; margin 1.82 at the pivot bore).
2. Cutter stop bar 60 mm long with two M16 screws in each plate instead of one (pending edit; screw margin 1.29 to 2.59, and the bar cannot turn).
3. Main and link pins 4340 instead of 4140 (link pin margin 1.35 to 1.76).
4. Link slot in the jaw arm tail from 100 mm instead of 95 mm (tail margin 1.50 to 1.60; links clear at nine stroke positions).
5. Fixed blade screws M12 instead of M16: the four M16 heads, 20 mm apart, touched (found by counting the screw solids; a check now guards it).
6. Ram base plate 20 mm S690QL instead of 12 mm S355 (plate margin 0.37 to 2.06).
7. Riser tube 88.9 x 10 instead of 114.3 x 8, so its wall stands over the base ring and under the cylinder base.
8. Earlier in the same TRL 3 pass (from the interrupted run, recorded in RBJ-DDR-002): collar adapters, interleaved pivot with spacers, located ram stack, stud-mounted crosshead and carrier, shear layout, lightening pockets, bolted handles.

### Build plan findings

- The kit's safety case rests on three made parts with the lowest margins (jaw arm tail, link pins, links) and on the base plate on real cribbing; these are the first things to strain-gauge at TRL 4.
- Assembly needs the spreader's crosshead pins fitted before the lower plate (no access from below afterwards), and the main pin pushed up from below with the tool on blocks; the step order reflects this.
- The collar thread is the single load path for the spreader and cutter reactions; the collar's rating must be confirmed from the cylinder maker before any adapter is cut.
- The kit layout used for the concept media is sparse; the overview picture places each tool in its own area so parts do not mix.
- The kit's `drawing.project_views` cannot convert the hose torus edges to SVG; `cad/src/sheets.py` adds a `safe_views` that skips such edges and is used for the concept blueprint and the making sketches. The kit itself was not changed.

### Safety concerns

- 700 bar oil injection, loads of 142 kN, flying fragments when cutting, stored energy in spread loads and bent bar, and collapsed structures that move. Safety sections are in every document that describes the hazard, and the build plan has eight safety stops (heat treatment, welds, first pressure, first load, proof load, lifting, cutting, use outside the bench).
- Nothing is proof-loaded; the strength margins are hand calculations on minimum yield values. No tool may be used before a CalRig proof load at 1.5 times the force at 700 bar and a crack check.
- Single-acting tools give no powered closing force; crews must not expect the spreader to squeeze or pull.
- The kit is not certified to NFPA 1936, NFPA 1960 or EN 13204, and the documents say so.

### Recommended next step

TRL 4 when the portfolio phase allows: buy one cylinder and confirm the collar and plunger threads, have the arms, pins and blades made and heat treated, then proof-test each tool on CalRig with strain gauges at the jaw arm tail, link pins and base plate.

## 2026-10-03: photoreal renders

Rendered with Blender Cycles on Amish's Mac from `cad/src/product_model.py`; captioned with `.kit/photo_caption.py`; `media/card.png` and `media/social-preview.png` made with `.kit/cards.py`. Views: hero, exploded, detail. image_qc passes and `render.py --check` has no FAIL.

2026-10-03: hero render reframed so the product fills the frame (rubblejack).

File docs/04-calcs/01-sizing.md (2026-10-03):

---
doc_id: RBJ-CAL-001
title: RubbleJack sizing calculations
project: RubbleJack
doc_type: Calculation
version: "0.1"
status: Draft
date: '2026-10-03'
author: Amish Chadha
license: CERN-OHL-S-2.0
revisions:
- version: "0.1"
  date: '2026-10-03'
  author: Amish Chadha
  change: First issue for TRL 3 on the constructable design (RBJ-DDR-002); hydraulics, spreader linkage and strength, cutter, lifting ram, pump, masses, cost and results against every requirement
---

# RubbleJack sizing calculations

The kit meets every requirement on paper at the pump's 700 bar relief pressure: 142 kN per cylinder, 49 to 64 kN at the spreader tips over a 262 mm opening, 16 mm bar sheared with a ratio of 1.36, 14.5 t at the ram, four loads under 25 kg and every made load-bearing part at least 1.60 on yield. The estimated cost is USD 2,395 over the USD 3,500 value-engineering target.

> **Safety:** These are first-principles estimates for a paper proof of concept. They do not show that any part of RubbleJack is safe to load. Hydraulic oil at 700 bar, loads of 142 kN and collapsed structures can kill. Every made tool must be proof-loaded on CalRig at 1.5 times the force at 700 bar and crack-checked before any use (RBJ-DDR-001, D9). See RBJ-PRC-001, Safety.

## Scope and method

`docs/04-calcs/sizing.py` computes every number below; tags in brackets (for example [B1]) match its printed lines, and it writes `docs/04-calcs/results.csv`. It imports the parameters, the spreader kinematics and the part masses from `cad/src/model.py`, so the geometry is the geometry in the STEP files and drawings. Costs come from `bom/bom.csv`. Strength checks are hand calculations with minimum yield values; a check passes at 1.5 or more on yield (R11). Nothing is measured.

## Assumptions

- The highest pressure anywhere is the pump's internal relief, 700 bar; the gauge lets the operator stop below it.
- Cylinder effective area 20.3 cm² (15 t class, 101 mm stroke); the force is 142.1 kN [A1].
- Minimum yield strengths: 4340 quenched and tempered to about 300 HB, 850 MPa; S690QL, 690 MPa; 7075-T6 thick plate, 430 MPa; 7075-T6 10 mm plate, 500 MPa; S355, 345 MPa; class 12.9 screws in shear, 0.58 of 1,100 MPa.
- Reinforcing bar: tensile strength up to 650 MPa (upper bound for B500B and ASTM A615 grade 60), shear strength 0.8 of that.
- Pin friction in the linkage ignored for forces (it lowers them by a few percent); estimated at 8 % in the energy flow.
- Pump: 0.9 cm³ a stroke in the slow stage, 3.6 cm³ in the fast stage, 900 cm³ usable oil, 380 N handle effort at 700 bar (catalogue class values); a tired person keeps up 25 strokes a minute (estimate).
- Carry bags 0.8 kg each.

## A. Hydraulics (R1, R5)

One cylinder gives 142.1 kN (14.5 t) at 700 bar [A1]. A full stroke takes 205 cm³ of oil, well inside the pump's 900 cm³ [A2]; only one tool is coupled at a time, and the three together would take 615 cm³ [F3]. Every pressurised part is specified at 700 bar working, the hoses at 4 to 1 burst (2,800 bar), and the gauge reads to 1,000 bar, so R5 is met by specification; the ratings are checked on the makers' sheets when parts are bought.

## B. Spreader linkage (R2, R3)

The crosshead pushes two links; each link pushes the tail of a jaw arm 160 mm behind the pivot, 40° below the cylinder axis. By virtual work the force between the tips is the cylinder force times the crosshead's travel per radian of jaw turn, divided by twice the 250 mm jaw length.

*Table 1. Spreader opening and force at 700 bar [B1].*

| Plunger travel (mm) | Jaw turn (deg) | Tip opening (mm) | Force between the tips (kN) |
| --- | --- | --- | --- |
| 0 | 0.0 | 32 | 48.6 |
| 25 | 7.8 | 99 | 56.0 |
| 50 | 14.7 | 158 | 60.9 |
| 75 | 21.2 | 211 | 63.6 |
| 101 | 27.8 | 262 | 64.1 |

The force rises as the jaws open because the links turn toward square with the tails. R2 (40 kN) is met over the whole opening, and R3 (250 mm) is met with 262 mm [B2]. The tips are 32 mm thick closed, so they need a gap of about 32 mm to start; a crew opens a starting gap with the ram or a pry bar. The largest link force is 115 kN, at full stroke, with the link at 52° to the cylinder axis [B3].

## C. Spreader strength (R11)

*Table 2. Spreader parts at 700 bar.*

| Part | Load case | Stress | Margin on yield | Tag |
| --- | --- | --- | --- | --- |
| Jaw arm, 60 mm from the pivot | 64.1 kN at the tip, solid section 70 mm deep | 416 MPa | 2.04 | [C1] |
| Jaw arm, 100 mm from the pivot | As above, 62 mm deep with both pockets | 461 MPa | 1.84 | [C1] |
| Jaw arm, 150 mm from the pivot | As above, 51 mm deep with both pockets | 436 MPa | 1.95 | [C1] |
| Jaw arm tail at the link slot | Tail moment at 100 mm, two 9.75 mm cheeks either side of the slot | 532 MPa | 1.60 | [C2] |
| Jaw arm knuckle | Whole arm moment (16.0 kN m) through the 18 mm knuckle round the pin | 392 MPa | 2.17 | [C3] |
| Main pivot pin, 45 mm, 18 mm bore | Whole cylinder force as a central point load over 102 mm (conservative) | 416 MPa | 2.04 | [C4] |
| Link pins, 25 mm | 115 kN link force, double shear and bending | 118 MPa shear, 484 MPa bending | 1.76 | [C5] |
| Link, net section at the eye | 115 kN | 388 MPa | 1.78 | [C5b] |
| Frame plate, net section at the window | Half the cylinder force in tension | 102 MPa | 4.93 | [C6] |
| Frame plate at the pivot bore | As above, stress concentration 2.5 | 275 MPa | 1.82 | [C6b] |
| Adapter screws, M16 class 12.9 | 17.8 kN each in shear on the root area | 123 MPa | 5.17 | [C7] |

Other checks: bearing of an arm's knuckle on the pin 167 MPa [C4b]; the crosshead's bearing on its pins 196 MPa against 430 MPa yield [C5c]; the links buckle out of plane at about 1,000 kN against 115 kN [C5b]; the collar thread in the adapter has about 4,490 mm² of thread in shear, 32 MPa [C7b]. The 10 mm frame plates (RBJ-DDR-002, C2) have a margin of 1.82 at their weakest section. The 4340 pins (C4) and the link slot starting at 100 mm (C5) raised the two lowest margins above 1.5.

## D. Cutter (R4, R11)

A 16 mm bar has 201 mm² of section; at a shear strength of 520 MPa it needs about 105 kN, or 515 bar, against 142 kN available: a ratio of 1.36 [D1]. At the same upper strength the cylinder could shear 18.7 mm bar [D1b]; the rating stays at 16 mm (RBJ-DDR-001, D4). The moving blade closes the cut after about 37 cm³ of oil, about 41 slow-stage strokes or under 2 minutes [D5].

After the cut the carrier lands on the stop bar with the whole cylinder force if the operator keeps pumping. With two M16 screws in each plate, each screw carries 35.5 kN, 247 MPa on its root area, margin 2.59; with one screw a side (the earlier design) the margin was 1.29 [D2, D2b] (RBJ-DDR-002, C6). The nose block, which takes the fixed blade's thrust, has the same four-screw fixing and margin [D2]. The cutter plates carry 48 MPa at the hook, margin 14.3 [D3]; the carrier's 7075 face bears on the stop at 60 MPa [D4].

## E. Lifting ram (R1, R12)

The ram lifts 14.5 t at 700 bar against the 10 t target (R1); a CalRig proof load at 1.5 times rated load is TRL 4 work. The riser tube, 88.9 x 10, carries 57 MPa, margin 6.02, and its wall stands at 34.5 to 44.5 mm from the axis, over the base ring at 36 to 46 mm and under the 70 mm cylinder base, so its end plates work in bearing [E1] (RBJ-DDR-002, C9).

The base plate is the critical part. Treated as a free circular plate of the same area (141 mm radius) on an even reaction, loaded on the 35 mm radius of the cylinder base, a 12 mm S355 plate would reach 931 MPa (margin 0.37); the 20 mm S690QL plate reaches 335 MPa, margin 2.06 [E2] (RBJ-DDR-002, C8). This model is conservative where the cribbing is stiff under the centre.

Under the 250 mm plate the bearing pressure is 2.27 MPa, far more than rubble can take. On three 100 mm hardwood sleepers 600 mm long it falls to 0.79 MPa [E3], which meets R12; the plate never goes on bare rubble. Reach: 256 mm closed, 357 mm open, 527 mm on the riser [E4].

> **Safety:** Never work under a load held only by the ram. Crib the load as it rises. The riser goes under the cylinder, never on the plunger.

## F. Pump and time (R7)

A full stroke under load takes about 228 slow-stage strokes, about 9 minutes; with no load the fast stage needs 57 strokes, about 2 minutes [F1]. Handle effort at 700 bar is 380 N on a 600 mm handle [F2]. One full spreader stroke at 700 bar moves 14.35 kJ of oil; with estimated losses the operator puts in about 16.9 kJ and 12.5 kJ reaches the jaw tips [F4] (Figure 4 of RBJ-PRC-001). Setting up needs two coupler connections and no tools, about 1 to 2 minutes from the bags (R7, estimate); a tool change is one coupler off and one on, about 20 s (R8).

## G. Masses (R6)

*Table 3. Packed loads, bag included [G1].*

| Load | Mass (kg) |
| --- | --- |
| Pump, gauge and hoses | 15.9 |
| Spreader | 24.8 |
| Cutter | 22.0 |
| Lifting ram set (base, riser, cylinder, saddle) | 23.7 |
| Whole kit [G2] | 86.4 |

Every load is under 25 kg; the spreader has 0.2 kg in hand. Bought parts use catalogue masses; made parts use the model's volumes.

## H. Cost (R10)

Value-engineering target: USD 3,500. Estimated cost of the constructable design: USD 5,895 (USD 2,395 over the target); made parts USD 3,030, bought parts USD 2,865 [H1]. The main drivers and the savings worth trying are in RBJ-DEC-001, Value engineering.

## L. Results against every requirement

*Table 4. Results (also in docs/04-calcs/results.csv).*

| ID | Result | Target | Status |
| --- | --- | --- | --- |
| R1 | 14.5 t at 700 bar (cylinder rated 15 t) | 10 t or more | Met on paper (proof load is TRL 4) |
| R2 | 48.6 kN closed to 64.1 kN open | 40 kN or more at the tips | Met on paper |
| R3 | 262 mm open; tips 32 mm thick closed | 250 mm or more | Met on paper |
| R4 | About 105 kN needed; 142 kN available, ratio 1.36 | Cut 16 mm bar | Met on paper |
| R5 | All parts 700 bar; hoses 2,800 bar burst; gauge to 1,000 bar | At or above relief; hoses 4 to 1 | Met by specification (to confirm when parts are bought) |
| R6 | 15.9, 24.8, 22.0 and 23.7 kg | No load over 25 kg | Met on paper (spreader 0.2 kg under) |
| R7 | Two coupler connections, about 1 to 2 min | Within 3 min | Met on paper |
| R8 | One coupler swap, about 20 s | Under 1 min | Met by design |
| R9 | Every hydraulic part in a class two or more makers offer | Two suppliers | Met by specification |
| R10 | USD 5,895 | Value-engineering target USD 3,500 | Over the value-engineering target by USD 2,395 |
| R11 | Lowest 1.60, the jaw arm tail | 1.5 or more on yield | Met on paper |
| R12 | 0.79 MPa on three hardwood sleepers | Never on bare rubble | Met by design and procedure |

No requirement fails. The figures that most need confirming at TRL 4 are the jaw arm tail and link pins (the lowest margins), the base plate on real cribbing, and the cutting force on the bar grades crews actually meet.

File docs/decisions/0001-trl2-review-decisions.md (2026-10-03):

---
doc_id: RBJ-DDR-001
title: RubbleJack TRL 2 review decisions
project: RubbleJack
doc_type: Design decision record
version: "0.1"
status: Draft
date: '2026-10-03'
author: Amish Chadha
license: CERN-OHL-S-2.0
revisions:
- version: "0.1"
  date: '2026-10-03'
  author: Amish Chadha
  change: TRL 2 review decisions D1 to D14, decided under Amish's 2026-10-03 pre-approval
---

# 0001: TRL 2 review decisions

- **Date:** 2026-10-03
- **Status:** decided. Amish, 2026-10-03: "start with the first 14 repos from the list of 29 projects. I pre-approve the batch runs along with any recommendations you come up with. I also accept any cost overruns or variations from the assumed scope cost." Each decision below is the recommendation made at the TRL 2 review and is decided as recommended.

## Context

The scaffold (RBJ-PRC-001 v0.1) described a kit built around one commodity hand pump, with bolt-on spreader and cutter heads on standard cylinders and a lifting ram, and left open how the heads attach, which cylinder class to use, how strong each part must be and how the kit is carried. The TRL 2 review settled these so the TRL 3 calculations (RBJ-CAL-001), the model and the build plan could proceed. Choices that touch safety take the conservative option; each says what evidence would relax it.

> **Safety:** RubbleJack lifts and spreads loads of up to 142 kN with oil at 700 bar, in collapsed structures. These decisions set the design basis on paper only. Nothing here makes the kit safe to use; it is not certified rescue equipment.

## Decisions

*Table 1. TRL 2 review decisions.*

| # | Decision | Reason | Affects |
| --- | --- | --- | --- |
| D1 | Use the commodity 700 bar (10,000 psi) class throughout: a two-speed hand pump with internal relief at 700 bar, single-acting spring-return 15 t cylinders with 101 mm stroke, 700 bar hoses and couplers, and a gauge on the pump outlet | The most widely stocked class of hand hydraulics; two or more makers offer every part (R9); 142 kN per cylinder covers R1, R2 and R4 | BOM lines 1 to 5; every calculation |
| D2 | Give each tool its own cylinder (three identical cylinders) rather than one cylinder with quick-change heads | A tool change becomes one coupler off and one on, about 20 s (R8), with no thread to clean of dust under rubble; the cylinders stay interchangeable as spares. Cost: two more cylinders (USD 840) | BOM line 5; R8; value engineering |
| D3 | Spreader: two jaw arms on one pivot pin, opened by a crosshead on the plunger and two links; 250 mm jaws; spreading only | Simple pinned linkage that local workshops can make; 49 to 64 kN at the tips and 262 mm opening (RBJ-CAL-001 section B). A single-acting cylinder gives no pulling or squeezing force, which is stated on the tool | Spreader parts; R2, R3 |
| D4 | Cutter: a guillotine shear with hardened S7 blades, single shear, rated for reinforcing bar up to 16 mm (B500B or ASTM A615 grade 60) | The cylinder can shear 18.7 mm bar at the upper strength, so a 16 mm rating keeps a ratio of 1.36. Conservative: no hardened bar, chain or larger bar. Relax only after proof cuts on CalRig at TRL 4 | Cutter parts; R4 |
| D5 | Lifting ram: the cylinder stands in a locating ring on a 250 mm base plate; one 150 mm riser may go under it, never on top of the plunger; a tilting saddle on the plunger | Load always passes straight down through located steel; a riser on the plunger is the classic way a ram kicks out | Ram parts; R1, R12 |
| D6 | Materials: 4340 quenched and tempered arms and pins; S690QL links and cutter plates; S7 blades; 7075-T6 aluminium for bulky, lightly stressed parts | High strength where sections are small, aluminium where parts are bulky, so each carried load stays under 25 kg (R6) | Every made part; R6, R11 |
| D7 | Strength rule (new R11): every made load-bearing part has at least 1.5 on yield at the 700 bar relief pressure, on conservative hand calculations | Conservative safety basis while nothing is tested. Relax only with strain-gauged proof loads on CalRig | RBJ-CAL-001; R11 |
| D8 | Publish as an open engineering reference with a not-certified notice naming NFPA 1936, NFPA 1960 and EN 13204 | Follows the patent and standards screen in RBJ-PRC-001 | README, every document, tool markings |
| D9 | Before any tool is used, it is proof-loaded on CalRig at 1.5 times the force at 700 bar and crack-checked; the plan for this is TRL 4 work | Conservative; matches the R1 verification method | First checks in RBJ-BLD-001; TRL 4 |
| D10 | Carry the kit as four loads in tool bags: pump, gauge and hoses; spreader; cutter; lifting ram set | Each stays under 25 kg packed (R6); four people can carry the whole kit | BOM line 23; R6 |
| D11 | The kit requires hardwood cribbing under the ram and next to every lifted load; cribbing is not designed or supplied (stays out of scope), and the documents give guidance on its use | Lifting without cribbing is the main hazard; local timber is widely available | Safety sections; R12 |
| D12 | Co-design: the first candidate partner to approach is a volunteer search and rescue association in southern Turkey (AKUT is the first candidate), with a local hydraulic workshop; first candidate region is the area hit in February 2023. Recorded as a first candidate, not agreed | A region with recent collapse experience, volunteer crews and a strong hydraulic trade | Co-design section of RBJ-PRB-001 |
| D13 | Shared blocks: the commodity hydraulics block (pump, hoses, couplers, gauge) is adopted as a shared block; CalRig is the proof-load rig; VoidScope stays a sibling | Re-use across the portfolio | RBJ-PRC-001 |
| D14 | The gauge stays fitted on the pump outlet whenever the kit is used | Crews see the pressure and stop before the relief valve is the only limit | BOM line 2; safety stops |

## Consequences

- The estimated cost rises above the USD 3,500 value-engineering target, mainly from D2 and D6 (see RBJ-DEC-001, Value engineering). Amish accepted cost overruns in the same instruction.
- R11 and R12 are added to RBJ-REQ-001.

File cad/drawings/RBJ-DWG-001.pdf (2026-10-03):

CONCEPT, NOT FOR FABRICATION | RubbleJack · github.com/BoujeeEnjinia1701/rubblejack

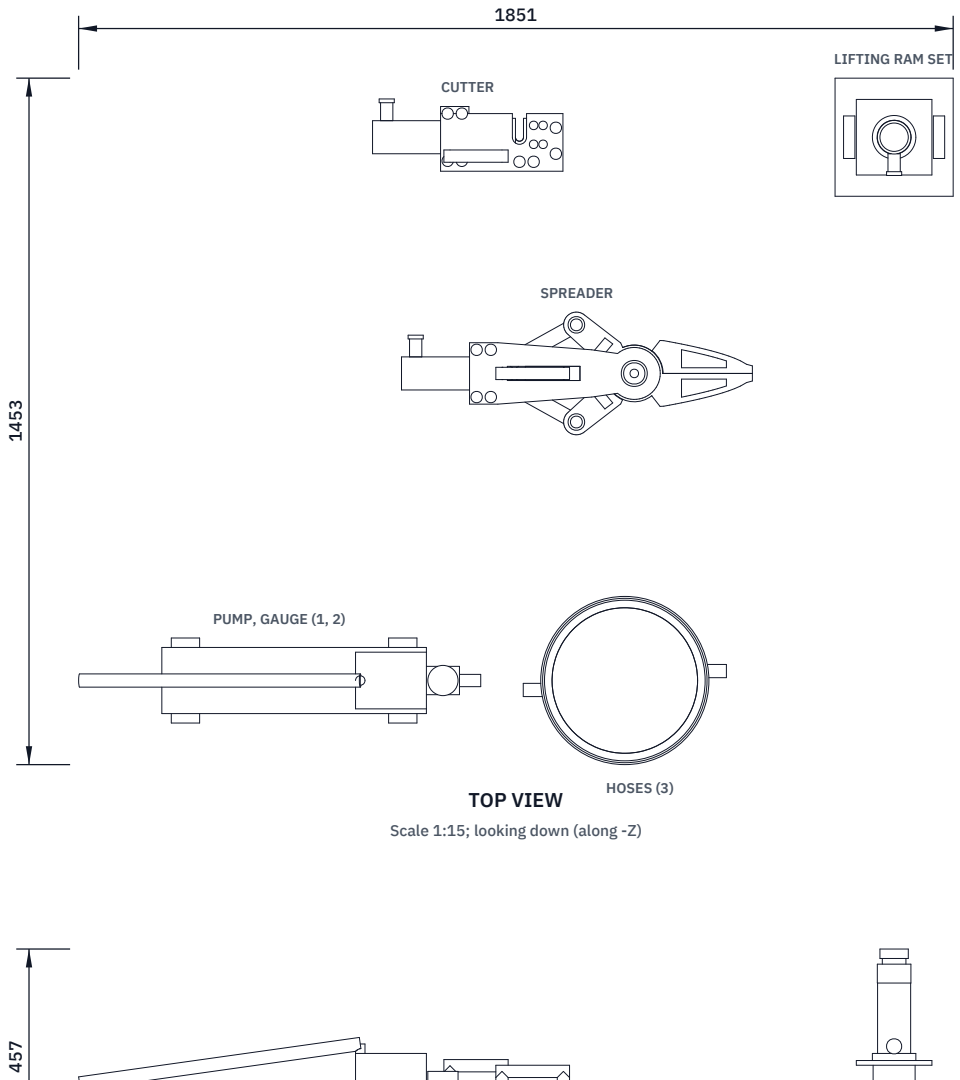
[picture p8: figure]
TOP VIEW; Scale 1:15; looking down (along -Z); PUMP, GAUGE (1, 2); SPREADER; CUTTER; LIFTING RAM SET; HOSES (3)

FRONT VIEW
Scale 1:15; looking at the front (along +Y)

RIGHT VIEW
Scale 1:15; looking at the right side (along -X)

PRELIMINARY, NOT FOR FABRICATION

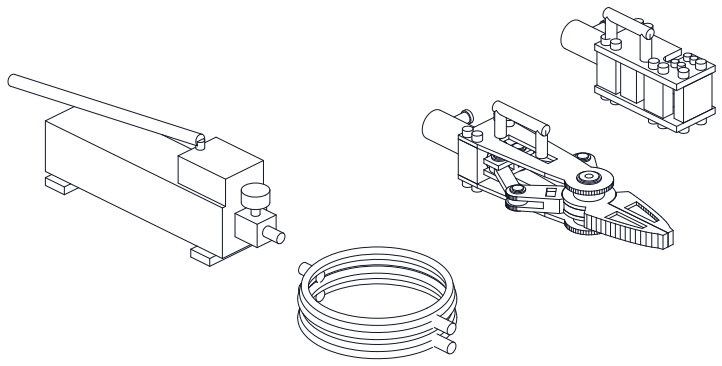
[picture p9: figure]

ISOMETRIC VIEW
Not to scale; kit laid out as packed for a drill; seen from the front right and above, about 30 deg elevation

MAIN DIMENSIONS AND INTERFACES (MM)
Cylinder (5), one per tool: 15 t, 101 stroke, 20.3 cm2, 700 bar Spreader: jaws 250 pivot to tip, 36 thick; tips 32 closed, 262 open Spreader frame plates (7) 7075-T6, 10 thick, 92 apart inside
Pins (12): pivot 45, links 25; link centres 150
Cutter: 16 bar in a 30 hook; blade travel 30 to the stop bar
Cutter plates (17) S690QL 16; stop bar 60 long, 2 screws each plate
Ram base (14) 250 square, 20 S690QL; riser (15) tube 88.9 x 10, 150 long Collar adapter (6) 60 x 130 x 92; 8 x M16 12.9 to the plates
Hoses (3) 2 m, 700 bar; pump (1) two-speed, 900 cm3 oil
Every pressurised part rated 700 bar; pump relief 700 bar
Third-angle; top view from +Z; (n) = BOM line
REV | DESCRIPTION | DATE | BY
P1 | General arrangement of the constructable design (RBJ-DDR-002) | 2026-10-03 | AC
RUBBLEJACK | github.com/BoujeeEnjinia1701/rubblejack

## Hand-pumped rescue tool kit: general arrangement

DRAWING NO.
RBJ-DWG-001

REV
P1

SHEET
1 of 1

SIZE

## ANSI B

SCALE
1:15

UNITS
mm
PROJECTION | DATE
2026-10-03

DRAWN
Amish Chadha

MATERIAL / NOTES
Per bom/bom.csv: 4340 and S690QL steel, S7 tool steel, 7075-T6 aluminium, bought 700 bar hydraulics. PRELIMINARY, NOT FOR FABRICATION
Licensed CERN-OHL-S-2.0 · Design Molecule Lab · designmolecule.com | Generated from cad/src; do not edit by hand

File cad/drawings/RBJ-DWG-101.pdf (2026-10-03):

BUILD PLAN SKETCH, PLAN NOT YET BUILT RubbleJack · github.com/BoujeeEnjinia1701/rubblejack

FRONT VIEW
Scale 1:2; looking at the front (along +Y)

TOP VIEW
Scale 1:2; looking down (along -Z)

RIGHT VIEW
Scale 1:2; looking at the right side (along -X)

60

130 92

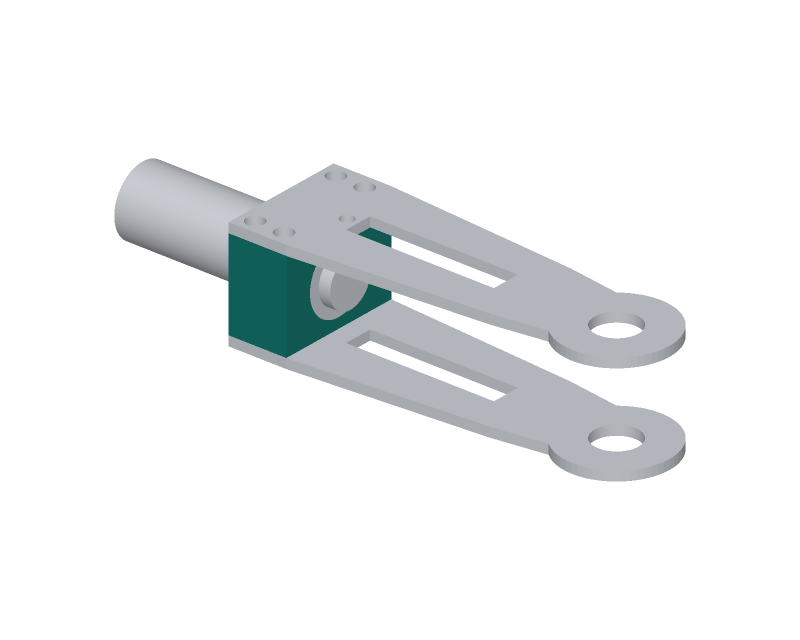
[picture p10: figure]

WHERE IT GOES
This part in colour, its neighbours in grey

HOW TO MAKE IT AND HOW IT FITS
Make two the same: one for the spreader, one for the cutter. Block 60 long x 130 wide x 92 tall, faces square
and parallel: the two 130 x 60 faces carry the frame plates. Bore through on the long axis: 72 mm for the cylinder body. From the front face, cut the cylinder's collar thread (71.4 mm, 12 UN class) 40 mm deep. Check the thread on the bought cylinder first and cut to match it.
Each 130 x 60 face: four M16 holes, drill 14 mm, tap 24 mm full thread, at 15 and 45 mm from the front face, 50 mm each side. Break every edge 1 mm.
Fit: screws onto the collar until the collar end is flush with
the front face; the plates sit flat on the 130 x 60 faces.
Check: plates lie flat with no rock; all eight screws start by hand.
REV | DESCRIPTION | DATE | BY
P1 | Making sketch for the prototype build plan | 2026-10-03 | AC
RUBBLEJACK | github.com/BoujeeEnjinia1701/rubblejack

## RubbleJack collar adapter (make 2): making sketch

DRAWING NO.
RBJ-DWG-101

REV
P1

SHEET
1 of 1

SIZE

## ANSI B

SCALE
1:2

UNITS
mm
PROJECTION | DATE
2026-10-03

DRAWN
Amish Chadha

MATERIAL / NOTES
7075-T6 aluminium plate, 100 mm
Licensed CERN-OHL-S-2.0 · Design Molecule Lab · designmolecule.com | Generated from cad/src; do not edit by hand

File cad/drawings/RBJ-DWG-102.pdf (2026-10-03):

BUILD PLAN SKETCH, PLAN NOT YET BUILT RubbleJack · github.com/BoujeeEnjinia1701/rubblejack

FRONT VIEW
Scale 1:5; looking at the front (along +Y)

TOP VIEW
Scale 1:5; looking down (along -Z)

RIGHT VIEW
Scale 1:5; looking at the right side (along -X)

404

130 10

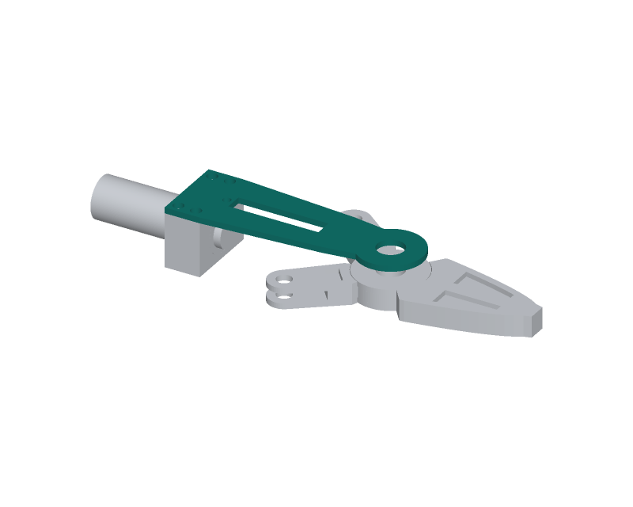
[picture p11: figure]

WHERE IT GOES
This part in colour, its neighbours in grey

HOW TO MAKE IT AND HOW IT FITS
Make two from 10 mm plate (waterjet or saw and file); lengths from the back edge. Profile: 404 long; 130 wide for the first 60 mm,
tapering to 100 wide at 259 mm, ending in a 55 mm radius round the pivot.
Pivot bore 45.4 mm, 349 mm from the back edge, on the centre line.
Four 18 mm holes for the adapter screws, 15 and 45 mm from the
back edge, 50 mm each side of the centre line.
Window 30 mm wide from 80 to 234 mm from the back edge. Upper plate only: two 13.6 mm handle holes on the centre line at 69 and 199 mm from the back edge.
Bore the two pivot holes with the plates clamped together.
Deburr; round the outside corners about 3 mm.
Check: a 45 mm pin goes through both pivot bores clamped together.
REV | DESCRIPTION | DATE | BY
P1 | Making sketch for the prototype build plan | 2026-10-03 | AC
RUBBLEJACK | github.com/BoujeeEnjinia1701/rubblejack

## RubbleJack spreader frame plate (make 2): making sketch

DRAWING NO.
RBJ-DWG-102

REV
P1

SHEET
1 of 1

SIZE

## ANSI B

SCALE
1:5

UNITS
mm
PROJECTION | DATE
2026-10-03

DRAWN
Amish Chadha

MATERIAL / NOTES
7075-T6 aluminium plate, 10 mm
Licensed CERN-OHL-S-2.0 · Design Molecule Lab · designmolecule.com | Generated from cad/src; do not edit by hand

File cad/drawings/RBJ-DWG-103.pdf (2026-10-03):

BUILD PLAN SKETCH, PLAN NOT YET BUILT RubbleJack · github.com/BoujeeEnjinia1701/rubblejack

FRONT VIEW
Scale 1:2; looking at the front (along +Y)

TOP VIEW
Scale 1:2; looking down (along -Z)

RIGHT VIEW
Scale 1:2; looking at the right side (along -X)

46

112 40

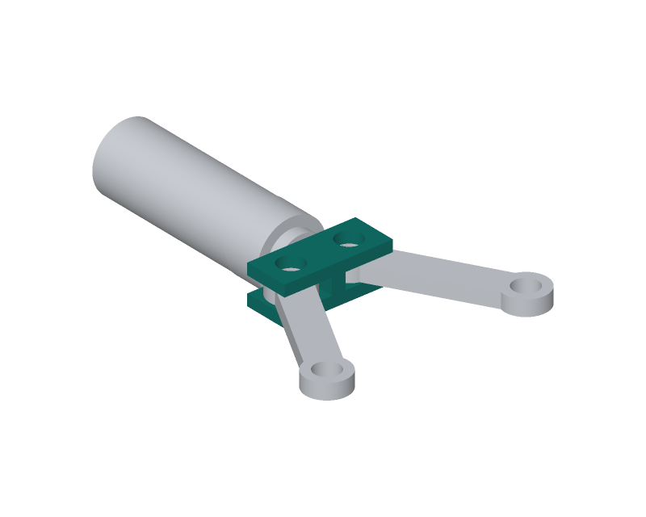
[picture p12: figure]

WHERE IT GOES
This part in colour, its neighbours in grey

HOW TO MAKE IT AND HOW IT FITS
Block 46 long (along the cylinder) x 112 wide x 40 tall.
Two slots 16.5 wide, centred in the height, from 7 mm either side of the centre line out to each side face: the links go in these. Mill or saw and file; keep the slot sides square. Pin bores 25.4 mm through the top and bottom,
30 mm each side of the centre line, at the middle of the length. Back face: tap M24 to suit the plunger stud (drill 21 mm,
25 mm deep) on the centre; the back face sits on the plunger end. Check: a link slides into each slot with 0.5 mm play in all.
REV | DESCRIPTION | DATE | BY
P1 | Making sketch for the prototype build plan | 2026-10-03 | AC
RUBBLEJACK | github.com/BoujeeEnjinia1701/rubblejack

## RubbleJack crosshead: making sketch

DRAWING NO.
RBJ-DWG-103

REV
P1

SHEET
1 of 1

SIZE

## ANSI B

SCALE
1:2

UNITS
mm
PROJECTION | DATE
2026-10-03

DRAWN
Amish Chadha

MATERIAL / NOTES
7075-T6 aluminium plate, 100 mm
Licensed CERN-OHL-S-2.0 · Design Molecule Lab · designmolecule.com | Generated from cad/src; do not edit by hand

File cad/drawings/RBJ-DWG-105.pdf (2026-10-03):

BUILD PLAN SKETCH, PLAN NOT YET BUILT RubbleJack · github.com/BoujeeEnjinia1701/rubblejack

FRONT VIEW
Scale 1:5; looking at the front (along +Y)

TOP VIEW
Scale 1:5; looking down (along -Z)

RIGHT VIEW
Scale 1:5; looking at the right side (along -X)

400

200 36

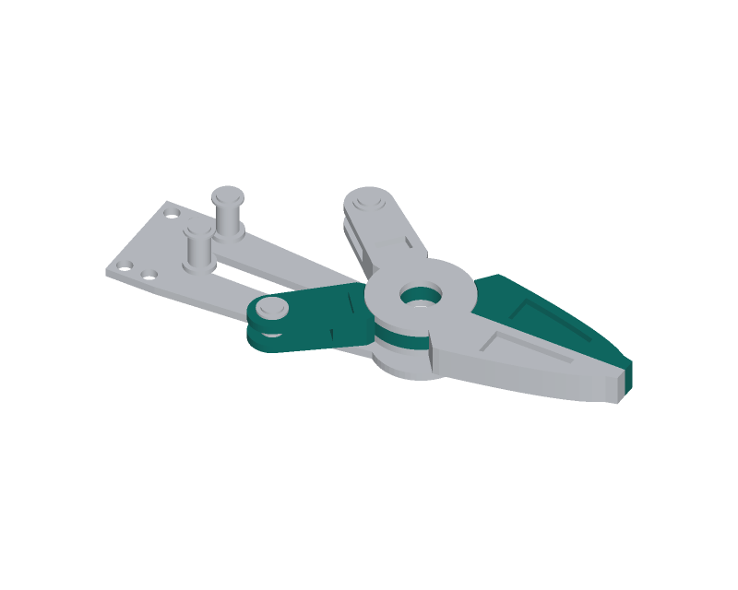
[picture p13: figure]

WHERE IT GOES
This part in colour, its neighbours in grey

HOW TO MAKE IT AND HOW IT FITS
Cut the profile from 40 mm plate (waterjet), then mill both faces to 36 mm. Jaw: 250 mm from the pivot to the tip; straight inner face; outer edge
70 deep near the pivot, curving to 16 deep at the tip.
Tail: pin bore 25.4 mm, 160 mm from the pivot, 140 deg round
from the jaw's inner face, behind the pivot.
Link slot 16.5 wide, centred in the thickness, from 100 mm out to the tail end.
Pivot bore 45.4 mm, reamed.
A centre knuckle 18 mm thick: face 9 mm off each side within a 61 mm radius of the pivot. Pockets 8 deep both faces, 12 in from the edges, in the jaw and tail.
Serrate the tip's outer face (2 mm teeth across) for grip.
Make A and B as a pair; break every edge 1 mm; no tool marks
across the jaw near the pivot. Crack-check after heat treatment. Check: A's knuckle slides into B's groove; the bores line up.
REV | DESCRIPTION | DATE | BY
P1 | Making sketch for the prototype build plan | 2026-10-03 | AC
RUBBLEJACK | github.com/BoujeeEnjinia1701/rubblejack

## RubbleJack jaw arm A: making sketch

DRAWING NO.
RBJ-DWG-105

REV
P1

SHEET
1 of 1

SIZE

## ANSI B

SCALE
1:5

UNITS
mm
PROJECTION | DATE
2026-10-03

DRAWN
Amish Chadha

MATERIAL / NOTES
4340 steel plate 40 mm, quenched and tempered to about 300 HB
Licensed CERN-OHL-S-2.0 · Design Molecule Lab · designmolecule.com | Generated from cad/src; do not edit by hand

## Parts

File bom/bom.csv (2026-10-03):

item | qty | spec | supplier | unit_cost_usd | make_buy | notes
1 Two-speed hand pump | 1 | Hydraulic hand pump, two-speed, 700 bar (10,000 psi) rated with factory-set internal relief at 700 bar, about 900 cm3 usable oil, about 3.6 cm3 per stroke first stage and 0.9 cm3 second stage, for single-acting cylinders, with a 3/8 NPTF outlet; catalogue mass about 11 kg with oil | Industrial hydraulic tool distributor; at least two makers offer this class (for example Enerpac, SPX Power Team or Larzep class) | 650.00 | buy | Indicative price; R9 commodity part; mass and handle effort per catalogue to confirm when bought
2 Gauge adapter and pressure gauge | 1 | Gauge adapter block with 3/8 NPTF ports, and a 63 mm glycerine-filled gauge reading 0 to 1,000 bar, both rated 700 bar working | Same distributor as item 1 | 180.00 | buy | Indicative price for the pair; shows working pressure so the crew stays under 700 bar (R5)
3 Hoses with quick couplers | 2 | Thermoplastic hydraulic hose 2 m, 6 mm bore, 700 bar working, at least 4 to 1 burst to working (2,800 bar burst), female coupler half on one end and male on the other, with dust caps; plus a coupler half and dust cap for each of the three cylinders | Same distributor as item 1 | 210.00 | buy | Indicative price per hose including its share of the three cylinder coupler halves; burst ratio per maker's sheet to confirm when bought (R5)
4 Tilting saddle | 1 | Tilting saddle for a 15 t cylinder, 60 mm face, 5 degrees tilt, stem to suit the plunger bore | Same distributor as item 1 | 60.00 | buy | Indicative price; fits the lifting ram only
5 Single-acting cylinder 15 t | 3 | Single-acting, spring-return hydraulic cylinder, 15 t (about 142 kN at 700 bar), 101 mm stroke, 20.3 cm2 effective area, about 70 mm body, collar thread about 71.4 mm (2 13/16 in, 12 UN class) over 40 mm, base mounting holes, plunger with an internal thread for attachments, coupler half fitted; collapsed length about 216 mm; about 5 kg | At least two makers offer this class (for example Enerpac RC-15x or SPX Power Team C-15 class) | 420.00 | buy | Indicative price each; one per tool so the tool change is only a coupler swap (RBJ-DDR-001, D2); collar thread, plunger thread and collapsed length to confirm when bought
6 Collar adapter | 2 | 7075-T6 aluminium block 60 x 130 x 92 mm cut from 100 mm plate; collar thread 40 mm deep, body bore 72 mm; four M16 tapped holes 24 mm deep in each 130 x 60 face | Machine shop (local workshop) | 240.00 | make | Indicative price each including material, turning and threading; one for the spreader, one for the cutter (DWG-101)
7 Spreader frame plate | 2 | 7075-T6 aluminium plate 10 mm, profile about 400 x 130 mm with a 110 mm pivot boss, 45.4 mm pivot bore, four 18 mm holes, 30 mm window | Waterjet or laser cutting service and machine shop | 70.00 | make | Indicative price each; reduced from 12 mm to 10 mm under the 2026-10-03 pre-approval (RBJ-DDR-002); DWG-102
8 Crosshead | 1 | 7075-T6 aluminium block 46 x 112 x 40 mm with two 16.5 mm link slots, two 25.4 mm pin bores and an M24 stud hole | Machine shop | 90.00 | make | Indicative price; DWG-103
9 Link | 2 | S690QL (quenched and tempered high-strength) steel plate 16 mm, 194 mm long over the eyes, 44 mm eyes, two 25.4 mm bores at 150 mm centres | Laser cutting service and machine shop | 40.00 | make | Indicative price each; DWG-104
10 Jaw arm | 2 | 4340 steel plate 40 mm, quenched and tempered to about 300 HB, machined to 36 mm; profile 250 mm pivot to tip plus a 187 mm tail; 45.4 mm pivot bore, 25.4 mm tail pin bore, 16.5 mm link slot, 8 mm deep lightening pockets each face; one with the centre knuckle (A), one with twin knuckles (B); serrated tip faces | Waterjet cutting service and machine shop with heat treatment | 450.00 | make | Indicative price each; the most costly made part; DWG-105 and DWG-106
11 Pivot spacers | 2 | 7075-T6 aluminium tube or bar, 70 mm outside, 45.4 mm bore, 28 mm long | Machine shop | 15.00 | make | Indicative price each; DWG-107
12 Pins with washers and circlips | 1 | Set: one main pivot pin 45 mm diameter, 18 mm bore, 120 mm under the head; four link pins 25 mm diameter (two 44 mm for the arm tails, two 48 mm for the crosshead, under the head), each with a head, washer and external circlip; 4340 steel bar, quenched and tempered to about 300 HB, ground | Machine shop | 200.00 | make | Indicative price for the set; DWG-108 and DWG-109
13 Carry handle | 2 | Steel tube 26.9 x 3.2 mm, bent to a D handle 130 mm (spreader) or 110 mm (cutter) between posts, 70 mm tall, with an M12 threaded plug welded in each post foot | Fabrication shop | 25.00 | make | Indicative price each; one on each tool; DWG-110
14 Ram base plate | 1 | S690QL steel plate 250 x 250 x 20 mm with two 24 x 90 mm hand slots; S355 ring 92 mm outside, 72 mm inside, 15 mm tall welded on the centre with low-hydrogen consumables and preheat per the plate maker's sheet | Fabrication shop | 110.00 | make | Indicative price; 20 mm high-strength plate from RBJ-CAL-001 section E (RBJ-DDR-002); DWG-117
15 Riser block | 1 | S355 tube 88.9 x 10 mm, 150 mm long, welded between two 160 x 160 x 10 mm S355 plates; 70 mm spigot 12 mm tall under the bottom plate; 92/72 mm ring on the top plate; the tube wall stands over the base ring and under the cylinder base | Fabrication shop | 120.00 | make | Indicative price; goes under the cylinder only; DWG-118
16 M16 cap screws | 26 | Socket head cap screw M16, class 12.9, black oxide; lengths per the build plan (30 to 45 mm); with hardened washers | Fastener supplier | 2.50 | buy | Indicative price each; 8 spreader adapter screws; 16 cutter adapter, nose and stop screws; 2 moving blade screws
17 Cutter plate | 2 | S690QL steel plate 16 mm, 259 x 122 mm with a 30 mm open hook, 18 mm screw holes; the upper plate also has four 13.5 mm fixed blade holes and two 13.6 mm handle holes | Laser cutting service | 90.00 | make | Indicative price each; DWG-116
18 Blade carrier | 1 | 7075-T6 aluminium block 50 x 102 x 91 mm with an M24 stud hole and two counterbored 17 mm holes for the moving blade screws | Machine shop | 120.00 | make | Indicative price; DWG-111
19 Moving blade | 1 | S7 shock-resisting tool steel, 70 x 70 x 45.5 mm, U notch 17 mm wide, two M16 tapped holes in the back face; hardened and tempered to 54 to 56 HRC; cutting edge ground square | Tool shop with heat treatment | 220.00 | make | Indicative price; DWG-112
20 Fixed blade | 1 | S7 shock-resisting tool steel, 70.5 x 70 x 45.3 mm, U notch 17 mm wide, four M12 tapped holes 20 mm deep in the top face; hardened and tempered to 54 to 56 HRC | Tool shop with heat treatment | 220.00 | make | Indicative price; DWG-113
21 Nose block and stop bar | 1 | Set: 7075-T6 aluminium nose block 30 x 90 x 92 mm with four M16 tapped holes; S355 steel stop bar 60 x 32 x 92 mm with four M16 tapped holes (two each face) | Machine shop | 90.00 | make | Indicative price for the set; the stop bar now has two screws in each plate (RBJ-DDR-002); DWG-114 and DWG-115
22 M24 studs | 2 | Threaded stud M24, class 10.9, 50 mm, with thread-locking compound; thread to suit the cylinder plunger | Fastener supplier | 10.00 | buy | Indicative price each; holds the crosshead and the blade carrier on their plungers; plunger thread to confirm when bought
23 Carry bags | 4 | Heavy nylon tool bag with shoulder strap and grab handles, about 0.8 kg, one per load: pump and hoses; spreader; cutter; lifting ram set | Outdoor or tool bag supplier | 50.00 | buy | Indicative price each; included in the carried-load masses (R6)
24 M12 cap screws | 8 | Socket head cap screw M12, class 12.9, black oxide, with spring washers; four 35 mm for the fixed blade, four 20 mm for the two carry handles | Fastener supplier | 1.20 | buy | Indicative price each; M12 on the fixed blade so the four heads, 20 mm apart, do not touch (RBJ-DDR-002)

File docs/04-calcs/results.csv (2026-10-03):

id | value | target | status
R1 | 14.5 t at 700 bar (cylinder rated 15 t) | 10 t or more | Met on paper (proof load is TRL 4)
R2 | 48.6 kN (closed) to 64.1 kN (open) at the tips at 700 bar | 40 kN or more at the tips | Met on paper
R3 | 262 mm tip opening at full stroke; tips 32 mm thick closed | 250 mm or more | Met on paper
R4 | 16 mm bar needs about 105 kN (515 bar); cylinder gives 142 kN, ratio 1.36 | Cut 16 mm reinforcing bar | Met on paper
R5 | Pump relief 700 bar; cylinders, couplers, hoses and gauge adapter rated 700 bar; hoses 4 to 1 burst (2,800 bar); gauge reads to 1,000 bar | Every pressurised part at or above relief; hoses 4 to 1 | Met by specification (ratings to confirm when parts are bought)
R6 | Pump, gauge and hoses 15.9 kg; Spreader 24.8 kg; Cutter 22.0 kg; Lifting ram set 23.7 kg | No single load over 25 kg | Met on paper (heaviest, the spreader, 0.2 kg under)
R7 | Pump, one hose and one tool: two coupler connections, no tools needed; estimated 1 to 2 min from the bags | Working within 3 min | Met on paper (timed drill is TRL 4)
R8 | Each tool has its own cylinder; a change is one coupler off and one on, about 20 s (estimate) | Under 1 min | Met by design
R9 | Pump, gauge, hoses, couplers, cylinders and saddle are catalogue parts in a class at least two makers offer | Standard parts from two suppliers | Met by specification
R10 | Estimated USD 5,895 from the BOM | Value-engineering target USD 3,500 | Over the value-engineering target by USD 2,395
R11 | Lowest margin 1.60: jaw arm tail at the link slot | 1.5 or more on yield at 700 bar for every made load-bearing part | Met on paper
R12 | Ram base plate 250 x 250 mm; sleeper bearing about 0.8 MPa on three hardwood sleepers; procedure: crib as the load rises | Never lift on bare rubble; base plate on cribbing | Met by design and procedure

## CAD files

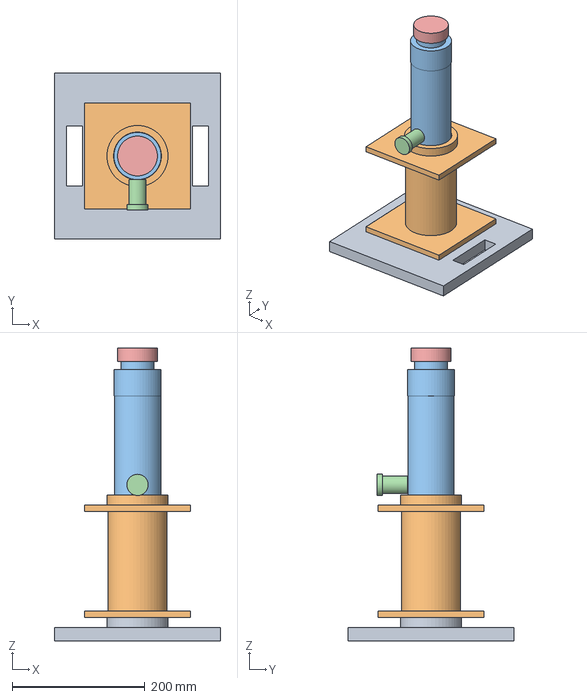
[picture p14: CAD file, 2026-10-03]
cad/step/rubblejack-ram.step
250.0 x 250.0 x 441.0 mm

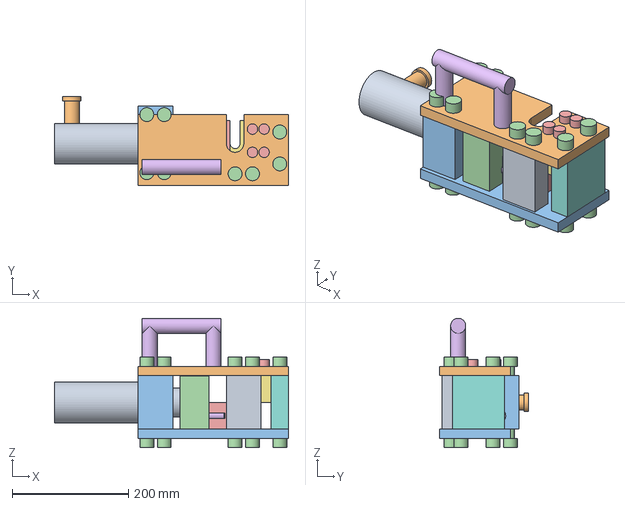
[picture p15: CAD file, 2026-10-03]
cad/step/rubblejack-cutter.step
403.0 x 153.0 x 223.0 mm

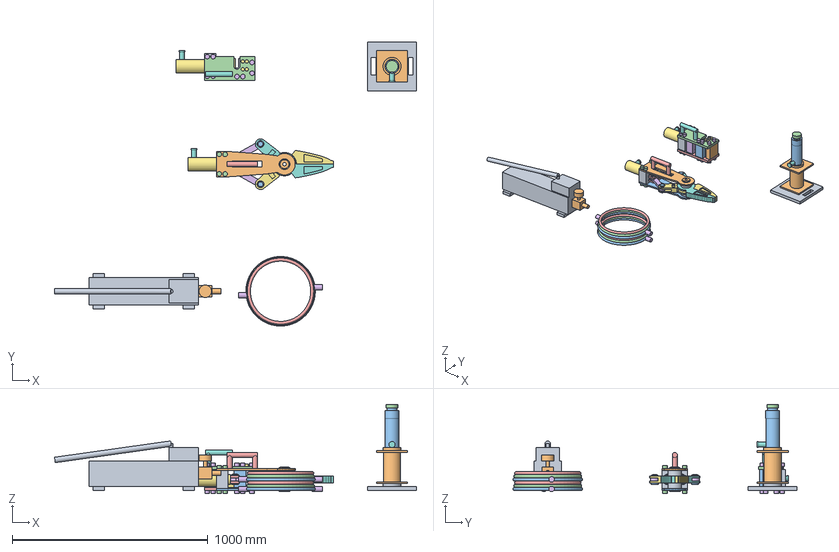
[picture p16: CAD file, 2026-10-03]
cad/step/rubblejack-kit.step
1851.1 x 1452.9 x 457.0 mm

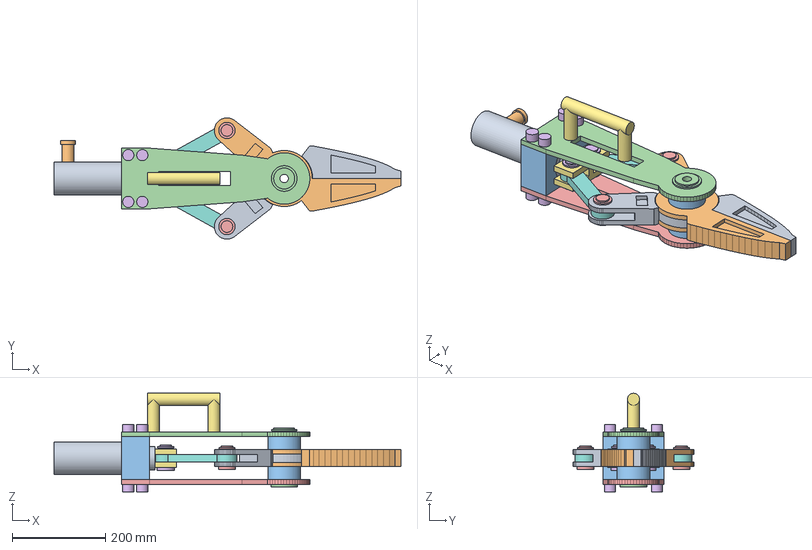
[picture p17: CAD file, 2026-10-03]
cad/step/rubblejack-spreader.step
742.7 x 259.6 x 211.0 mm

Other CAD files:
cad/stl/rubblejack-cutter.stl
cad/stl/rubblejack-kit.stl
cad/stl/rubblejack-ram.stl
cad/stl/rubblejack-spreader.stl

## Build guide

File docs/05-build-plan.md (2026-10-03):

---
doc_id: RBJ-BLD-001
title: RubbleJack prototype build plan
project: RubbleJack
doc_type: Build plan
version: "0.1"
status: Draft
date: '2026-10-03'
author: Amish Chadha
license: CERN-OHL-S-2.0
revisions:
  - version: "0.1"
    date: '2026-10-03'
    author: Amish Chadha
    change: First build plan; design made constructable (RBJ-DDR-002); pictures by component, joint and step
---

# RubbleJack prototype build plan

**Plan, not yet built.** How to build the first proof-of-concept RubbleJack kit, component by component. Building and testing to it is TRL 4 work. Decisions are kept in the design decisions register ([docs/06-design-decisions.md](06-design-decisions.md)), not here.

> **Safety:** RubbleJack works with oil at 700 bar (10,000 psi) and forces of 142 kN (14.5 t). A failed part can throw fragments, and oil from a pinhole leak can be injected under the skin. Nothing built to this plan is rescue equipment: it is a prototype for proof testing, not certified to NFPA 1936, NFPA 1960 or EN 13204. No tool is pressurised until the safety stops in section 6 are passed, and no tool is used on a load, let alone a person, until it has been proof-loaded on CalRig and crack-checked. Hardened tool steel, 4340 and S690QL plate need proper heat treatment and welding procedures; cut edges are sharp.

## 1. What you are building

Figure 1. Every component, pulled apart and numbered in build order

*Figure 1. Every component of the kit pulled apart and numbered in build order: spreader 1 to 12, cutter 13 to 21, lifting ram 22 and 23, then the bought parts.*

The prototype is the whole kit: a bought two-speed hand pump with a gauge and two 2 m hoses, and three tools, each on its own bought 15 t cylinder. The spreader is two steel jaw arms on one pin, held between two aluminium plates and opened by a crosshead and two links. The cutter is a guillotine: a hardened blade on a carrier slides past a fixed blade, with the bar held in a hook cut in two steel plates. The lifting ram is the third cylinder standing on a steel base plate, with a riser block that can go under it. Eighteen kinds of part are made, in a machine shop and a fabrication shop: waterjet or laser cutting of plate, milling, turning, drilling and tapping, heat treatment of the arms, pins and blades, and a few welds on the ram parts and handles. Everything else is bought and bolted on. The parts cost about USD 5,895 from the bill of materials.

## 2. What changed to make it buildable

The scaffold described bolt-on heads, base plates and extension tubes without saying how any part is made or held. Each change below keeps what the kit does; all are recorded in decision record RBJ-DDR-002.

*Table 1. Changes from the concept.*

| Component | The concept had | The buildable design has | Why |
| --- | --- | --- | --- |
| Spreader and cutter heads | Bolt-on heads, no interface | Two plates bolted to an aluminium adapter that screws onto the cylinder's collar thread; a cylinder for each tool (Figure 20) | The collar thread is the cylinder's own fixing; a tool change is a hose swap |
| Spreader frame plates | 12 mm aluminium | 10 mm aluminium | Lighter; still strong enough at the pivot |
| Spreader pivot | Arms overlapping on a pin | Interleaved knuckles on one pin with a spacer each side (Figure 23) | Both arms share one pin; nothing slides along it |
| Pins | 4140 steel | 4340 steel, hardened and tempered | Stronger link pins |
| Jaw arm tail | Link slot from 95 mm | Link slot from 100 mm | Stronger tail; links still clear |
| Cutter stop bar | 30 mm long, one screw each side | 60 mm long, two screws each side (Figure 27) | It cannot turn and its screws are twice as strong |
| Fixed blade screws | Four M16, heads touching | Four M12 (Figure 26) | The heads now clear each other |
| Ram base plate | 12 mm mild steel | 20 mm high-strength steel (Figure 28) | The 12 mm plate would bend under full load |
| Riser block | 114 mm tube | 89 mm tube with a 10 mm wall | The tube wall stands right over the base ring and under the cylinder |
| Ram stack | Loose base plates and tubes | Locating rings and a spigot (Figure 28) | Stacked parts cannot slide |

## 3. Making the components

Make and check each component before the step that needs it. The making sketches give the three views with overall sizes; the notes on each sketch give the sizes that matter. Heat-treated parts are machined first, heat treated, then finished and crack-checked (dye penetrant or magnetic particle).

### 3.1 Collar adapters (make 2: one for the spreader, one for the cutter)

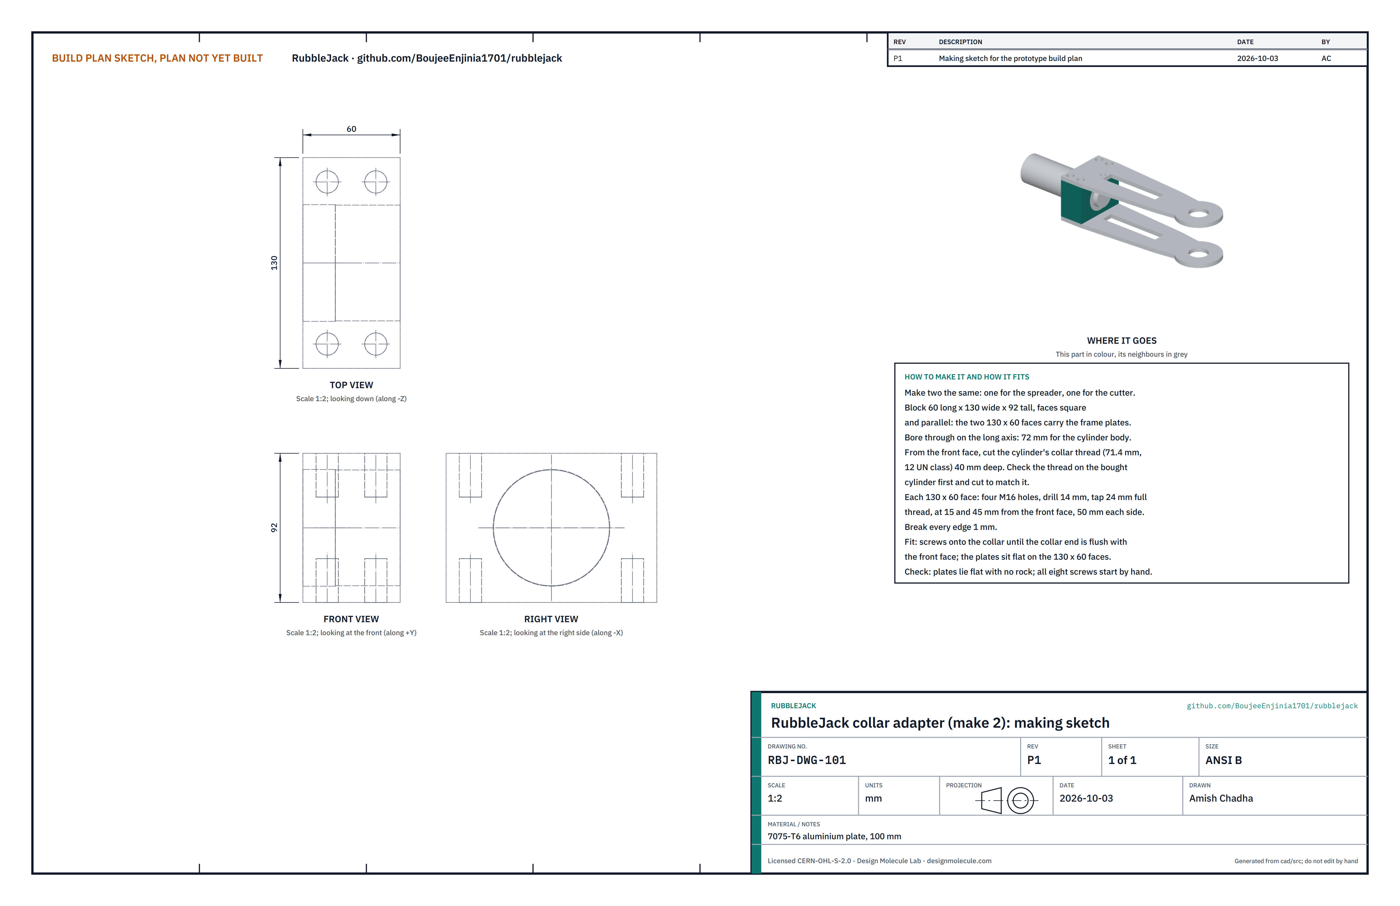
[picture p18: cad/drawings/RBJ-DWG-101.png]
Figure 2. Making sketch of the collar adapter


*Figure 2. Making sketch RBJ-DWG-101.*

**What it is.** An aluminium block 60 mm long, 130 mm wide and 92 mm tall that screws onto the cylinder's collar thread and carries the two plates of a tool. 7075-T6 plate, 100 mm thick.

**How to make it.**

1. Mill the block to 60 x 130 x 92 mm, faces square; the two 130 x 60 faces must be parallel and 92 mm apart.
2. Bore a 72 mm hole through on the long axis, centred on the 130 x 92 face.
3. From the front face, cut the cylinder's collar thread 40 mm deep. Measure the thread on the bought cylinder first and cut to match it (about 71.4 mm, 12 threads an inch).
4. In each 130 x 60 face, drill 14 mm and tap M16 four holes, 24 mm of full thread, at 15 and 45 mm from the front face, 50 mm each side of the centre line.
5. Break every edge 1 mm.

**How it fits.** It screws onto the collar until the collar's end is flush with its front face (Figure 20). The frame plates lie flat on the two 130 x 60 faces, held by four M16 screws each.

**Check.** A plate lies on each face with no rock, and all eight screws start by hand.

### 3.2 Spreader frame plates (make 2)

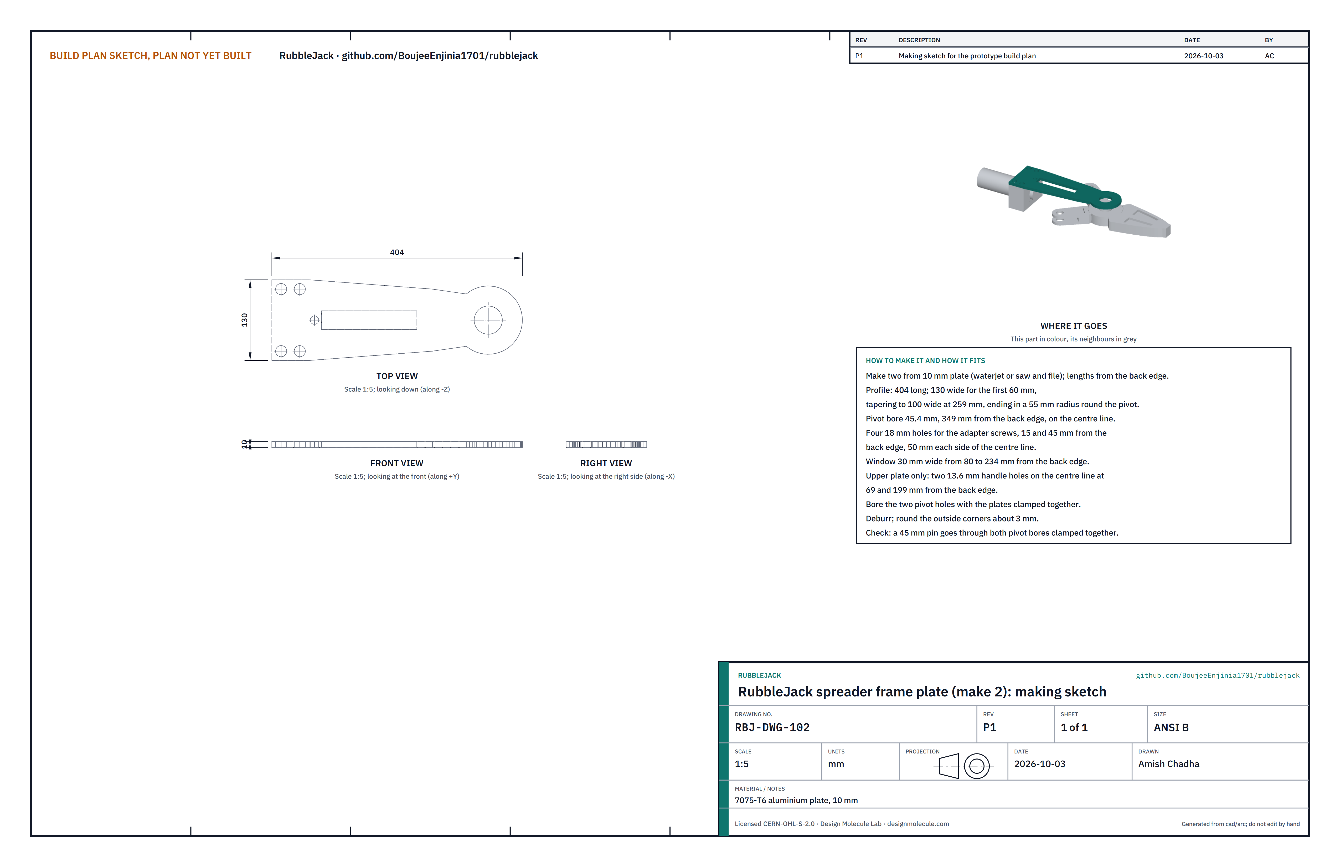
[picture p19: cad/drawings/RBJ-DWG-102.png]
Figure 3. Making sketch of the spreader frame plate


*Figure 3. Making sketch RBJ-DWG-102.*

**What it is.** The two plates above and below the jaw arms that carry the pivot pin and pull back on the adapter. 7075-T6 aluminium plate, 10 mm.

**How to make it.**

1. Cut the profile by waterjet or saw and file: 404 mm long, 130 mm wide for the first 60 mm, tapering to 100 mm wide 259 mm from the back edge, ending in a 55 mm radius round the pivot.
2. With both plates clamped together, bore the 45.4 mm pivot hole 349 mm from the back edge on the centre line, and drill four 18 mm holes 15 and 45 mm from the back edge, 50 mm each side of the centre line.
3. Cut the 30 mm wide window from 80 to 234 mm from the back edge; the crosshead runs under it.
4. Upper plate only: drill two 13.6 mm handle holes on the centre line, 69 and 199 mm from the back edge.
5. Deburr; round the outside corners about 3 mm.

**How it fits.** Each plate's back end sits flat on the adapter; the pivot bore carries the main pin with the spacers between plate and arms.

**Check.** A 45 mm pin passes through both pivot bores with the plates clamped together.

### 3.3 Crosshead

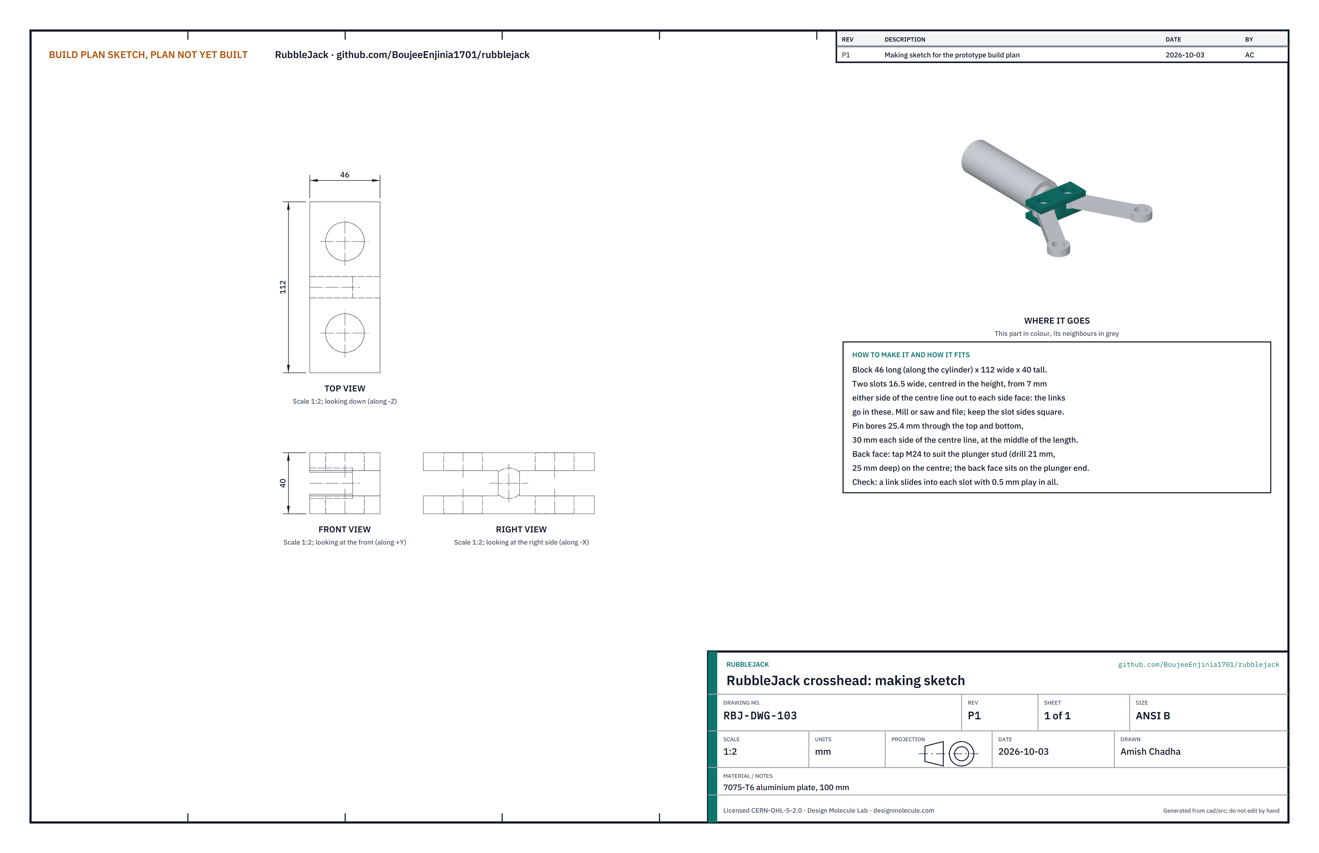
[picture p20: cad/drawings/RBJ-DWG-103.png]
Figure 4. Making sketch of the crosshead


*Figure 4. Making sketch RBJ-DWG-103.*

**What it is.** The block on the end of the spreader's plunger that pushes both links. 7075-T6 aluminium, 46 x 112 x 40 mm.

**How to make it.**

1. Mill the block to size.
2. Cut two slots 16.5 mm wide, centred in the 40 mm height, from 7 mm either side of the centre line out to each side face.
3. Bore two 25.4 mm pin holes through the top and bottom, 30 mm each side of the centre line, at the middle of the length.
4. In the back face, on the centre, drill 21 mm and tap M24, 25 mm deep, to suit the plunger stud.

**How it fits.** It screws onto an M24 stud in the plunger until its back face seats on the plunger end; the links sit in its slots (Figure 21).

**Check.** A link slides into each slot with about 0.5 mm of play.

### 3.4 Links (make 2)

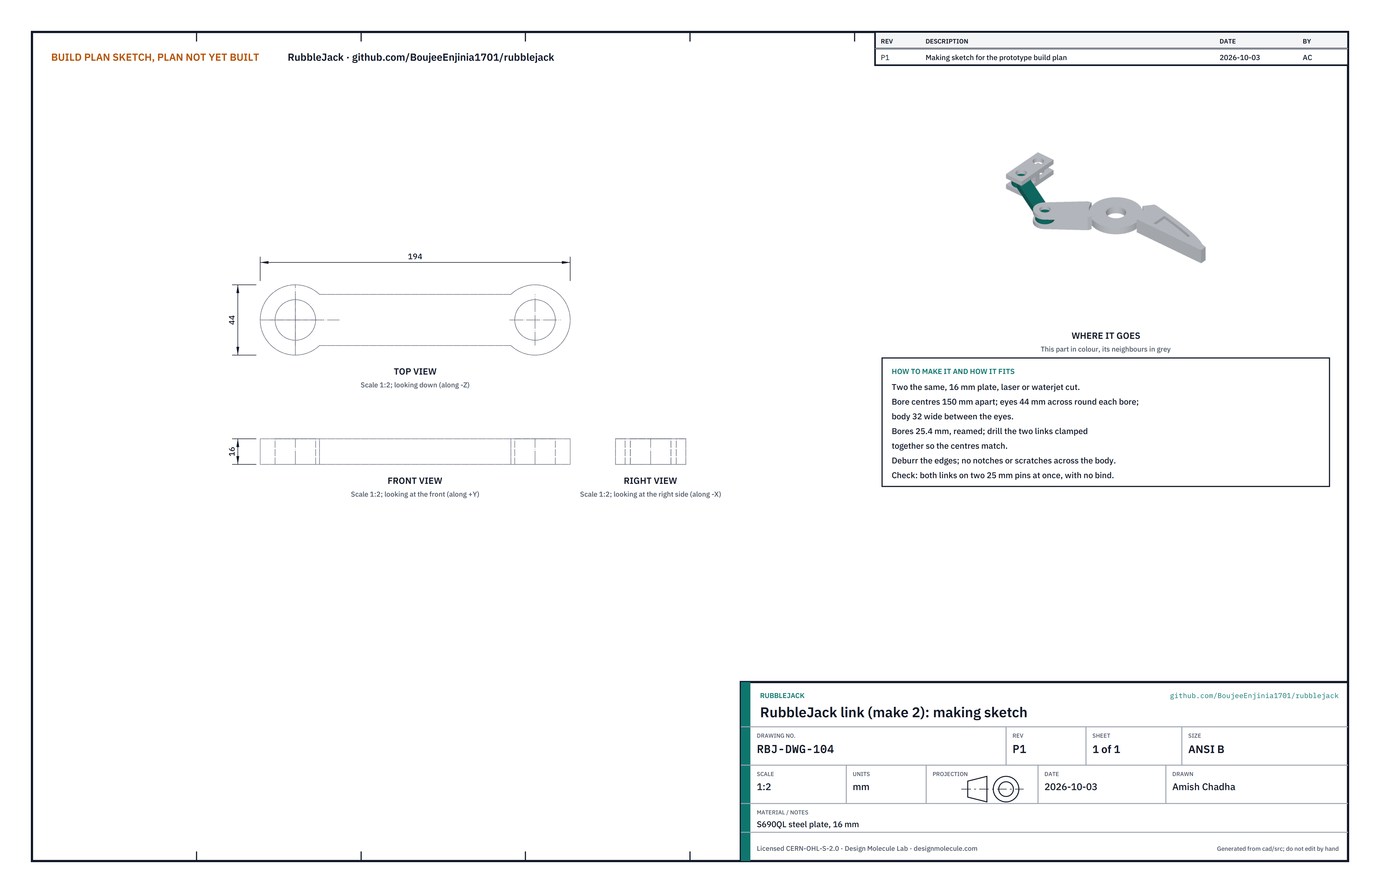
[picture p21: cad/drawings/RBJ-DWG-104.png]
Figure 5. Making sketch of the link


*Figure 5. Making sketch RBJ-DWG-104.*

**What it is.** The two bars that push the jaw arm tails. S690QL high-strength steel plate, 16 mm.

**How to make it.**

1. Laser or waterjet cut two links: 150 mm between bore centres, 44 mm eyes, 32 mm wide between the eyes.
2. With the two clamped together, drill and ream the 25.4 mm bores.
3. Deburr; leave no notches or scratches across the body.

**How it fits.** One eye goes in a crosshead slot and the other in the slot of an arm's tail, each on a 25 mm pin (Figures 21 and 22).

**Check.** Both links sit on two 25 mm pins at once without binding.

### 3.5 Jaw arm A (centre knuckle)

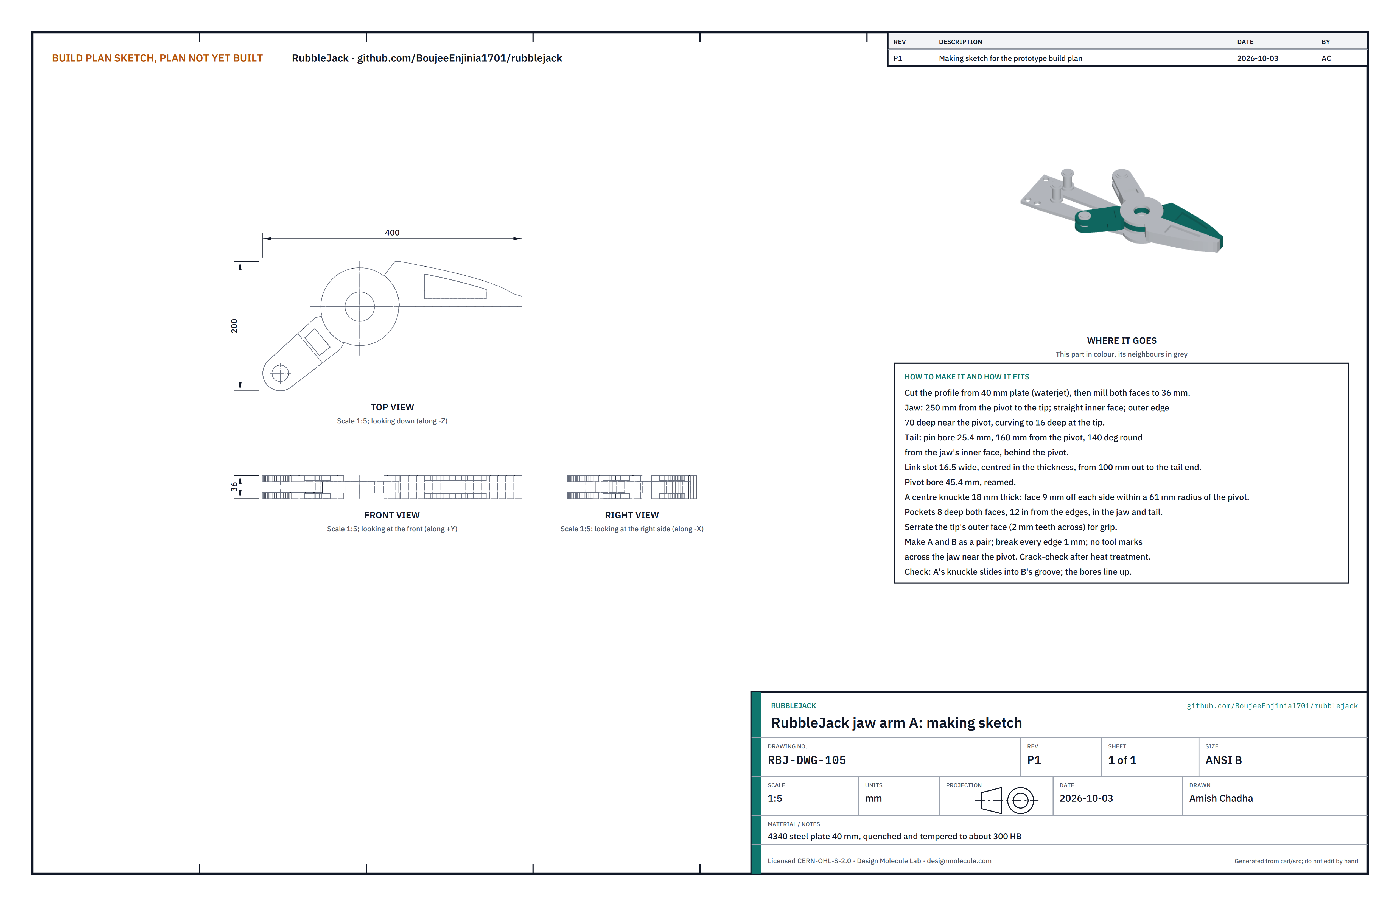
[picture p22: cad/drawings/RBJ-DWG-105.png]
Figure 6. Making sketch of jaw arm A


*Figure 6. Making sketch RBJ-DWG-105.*

**What it is.** One of the two jaws, with a tail behind the pivot that the link pushes. 4340 steel plate 40 mm, quenched and tempered to about 300 HB, milled to 36 mm.

**How to make it.**

1. Waterjet cut the profile from 40 mm plate: jaw 250 mm from the pivot to the tip, straight inner face, outer edge 70 mm deep near the pivot curving to 16 mm at the tip; tail behind the pivot ending in a 27 mm radius eye 160 mm from the pivot.
2. Mill both faces to 36 mm.
3. Bore and ream the 45.4 mm pivot hole and the 25.4 mm tail pin hole.
4. Mill the 16.5 mm slot in the tail, centred in the thickness, from 100 mm out to the tail end.
5. Within a 61 mm radius of the pivot, mill 9 mm off each face, leaving a centre knuckle 18 mm thick.
6. Mill 8 mm deep lightening pockets in both faces, 12 mm in from every edge, in the jaw and the tail.
7. Cut 2 mm serrations across the outer face of the tip for grip.
8. Break every edge 1 mm; leave no tool marks across the jaw near the pivot. Crack-check.

**How it fits.** Its knuckle sits in arm B's groove on the main pin (Figure 23); the link's eye sits in its tail slot (Figure 22).

**Check.** Its knuckle slides into arm B's groove and the bores line up.

### 3.6 Jaw arm B (twin knuckles)

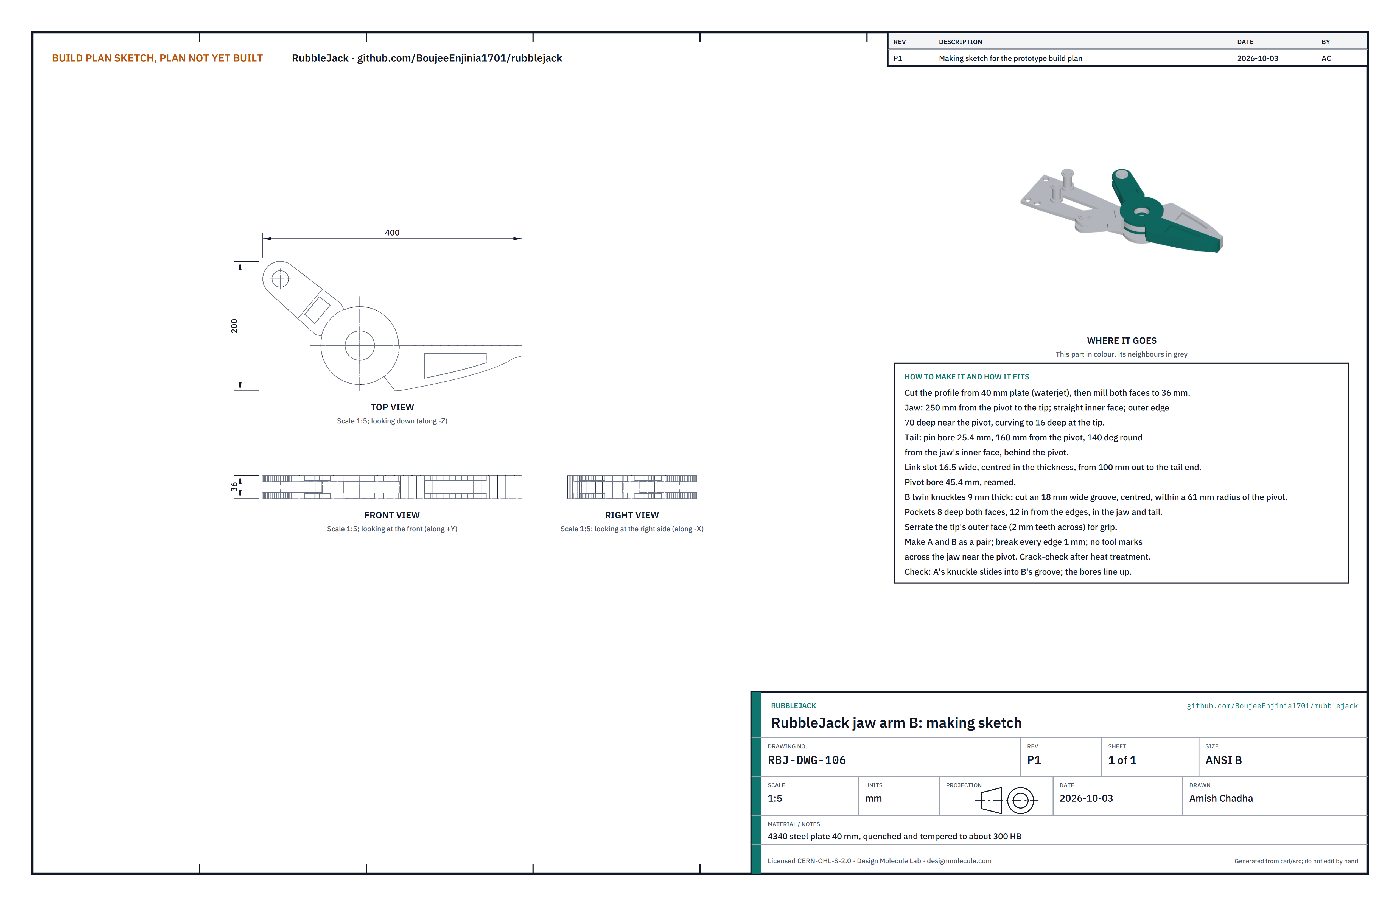
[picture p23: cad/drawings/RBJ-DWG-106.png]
Figure 7. Making sketch of jaw arm B


*Figure 7. Making sketch RBJ-DWG-106.*

**What it is.** The other jaw, a mirror image of arm A with twin knuckles. Same material.

**How to make it.** As arm A, mirrored, except step 5: within a 61 mm radius of the pivot, mill an 18 mm wide groove centred in the thickness, leaving two knuckles 9 mm thick. Make arms A and B as a pair.

**How it fits.** Arm A's knuckle sits between its two knuckles on the main pin (Figure 23).

**Check.** As arm A.

### 3.7 Pivot spacers (make 2)

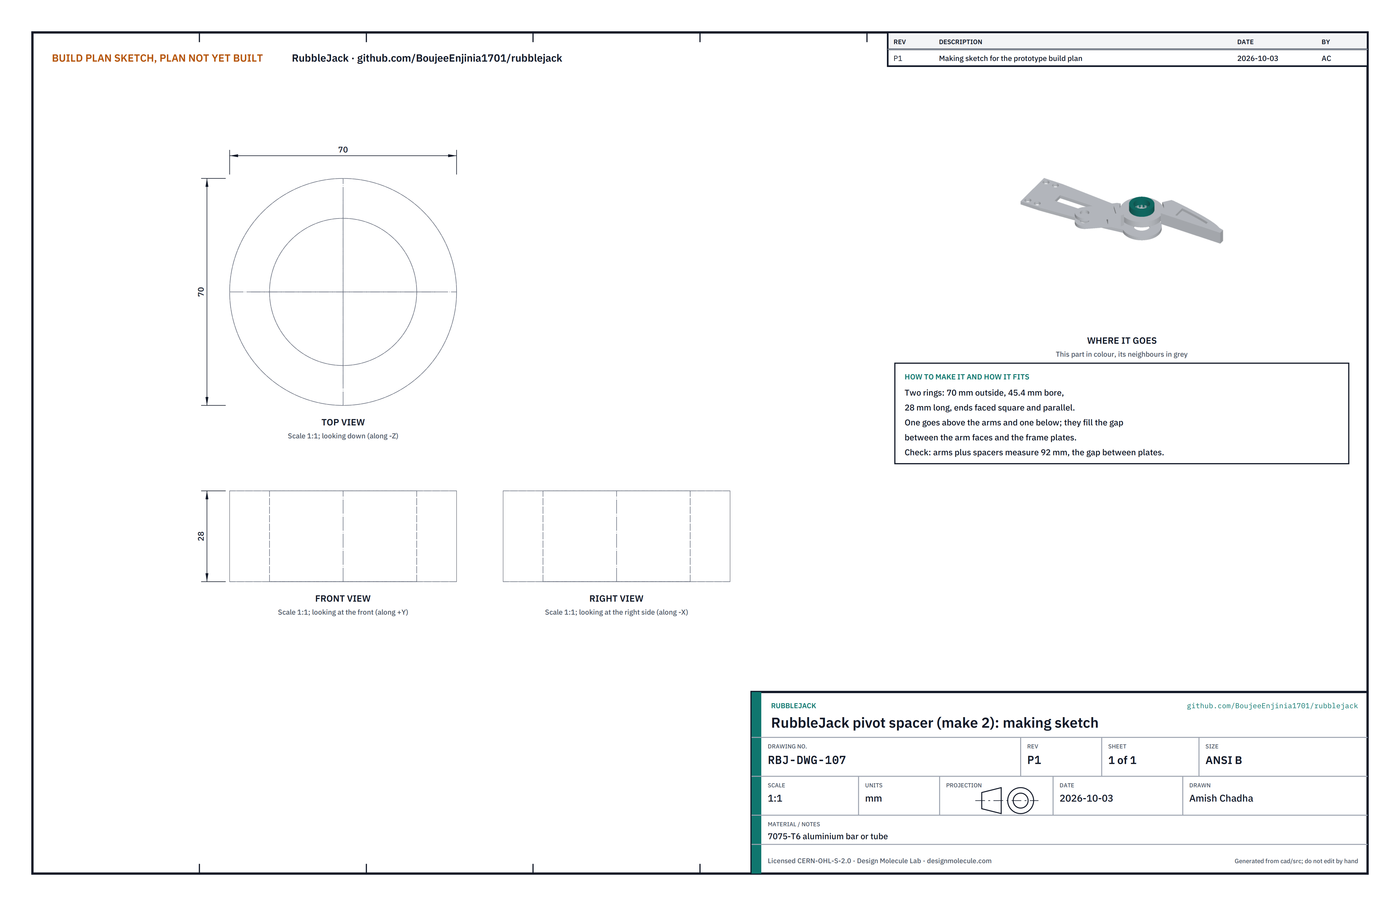
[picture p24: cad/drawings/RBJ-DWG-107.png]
Figure 8. Making sketch of the pivot spacer


*Figure 8. Making sketch RBJ-DWG-107.*

**What it is.** Two rings, 70 mm outside, 45.4 mm bore, 28 mm long, from 7075-T6 bar or tube; ends faced square and parallel.

**How it fits.** One above the arms and one below, between the arm faces and the frame plates (Figure 23).

**Check.** The two arms and two spacers stacked measure 92 mm, the gap between the plates.

### 3.8 Main pivot pin

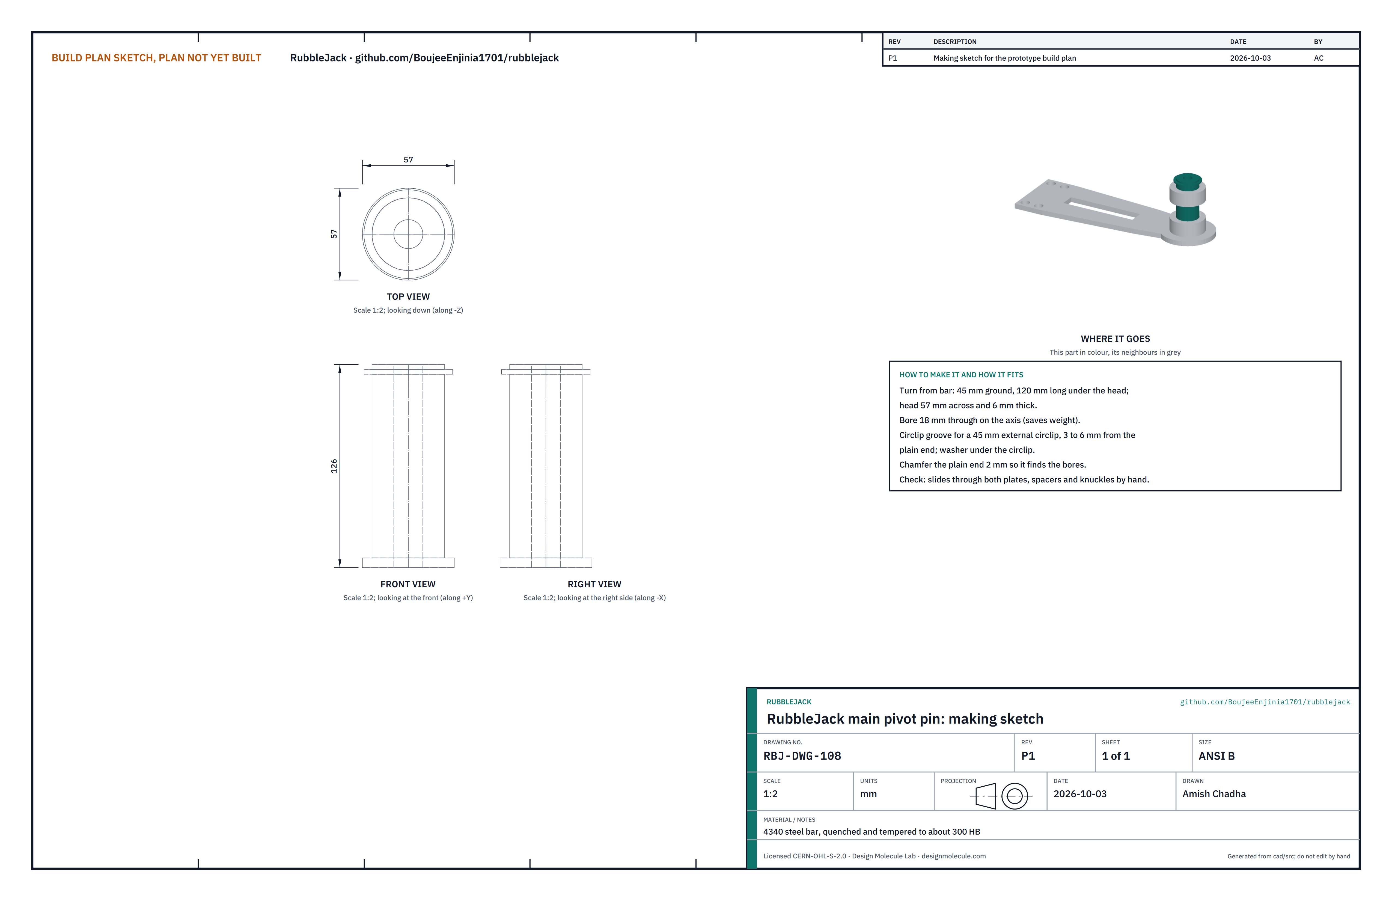
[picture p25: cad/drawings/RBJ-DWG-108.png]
Figure 9. Making sketch of the main pivot pin


*Figure 9. Making sketch RBJ-DWG-108.*

**What it is.** A 45 mm pin, 120 mm long under a 57 mm head 6 mm thick, with an 18 mm bore, from 4340 bar quenched and tempered to about 300 HB, ground.

**How to make it.** Turn, bore, cut a groove for a 45 mm external circlip 3 to 6 mm from the plain end, chamfer the plain end 2 mm, heat treat and grind.

**How it fits.** It goes up from below through the lower plate, spacer, knuckles, spacer and upper plate; a washer and circlip hold it on top (Figure 23).

**Check.** It slides through every bore by hand.

### 3.9 Link pins (make 4)

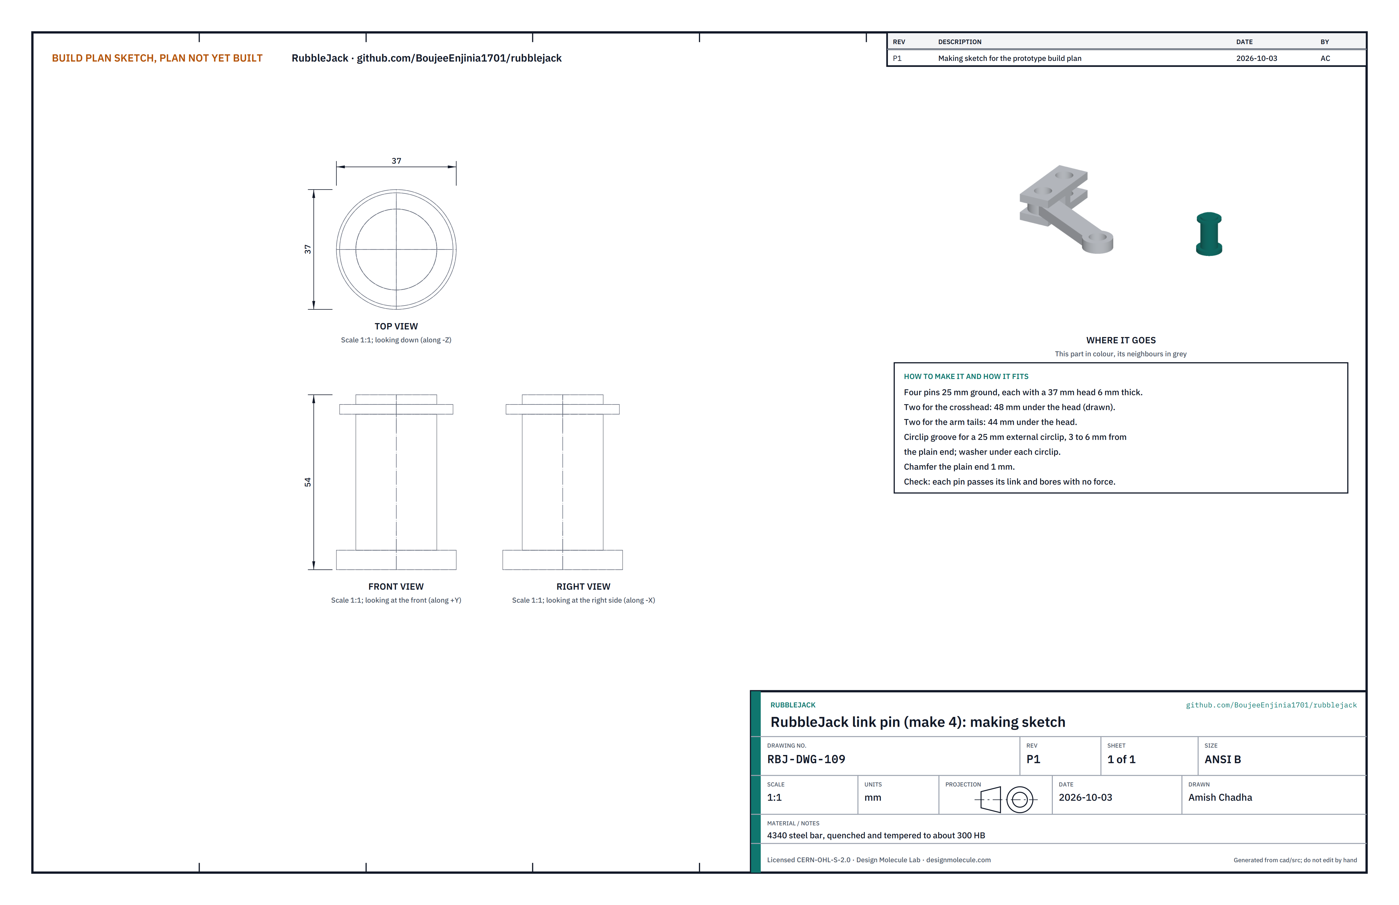
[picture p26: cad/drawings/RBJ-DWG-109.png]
Figure 10. Making sketch of the link pin


*Figure 10. Making sketch RBJ-DWG-109.*

**What it is.** Four 25 mm pins with 37 mm heads, from the same 4340 bar: two 48 mm long under the head for the crosshead, two 44 mm for the arm tails. Each has a groove for a 25 mm external circlip and a washer.

**How it fits.** Each goes up from below through a link eye and the crosshead or tail; washer and circlip on top (Figures 21 and 22).

**Check.** Each passes its link and bores without force.

### 3.10 Carry handles (make 2)

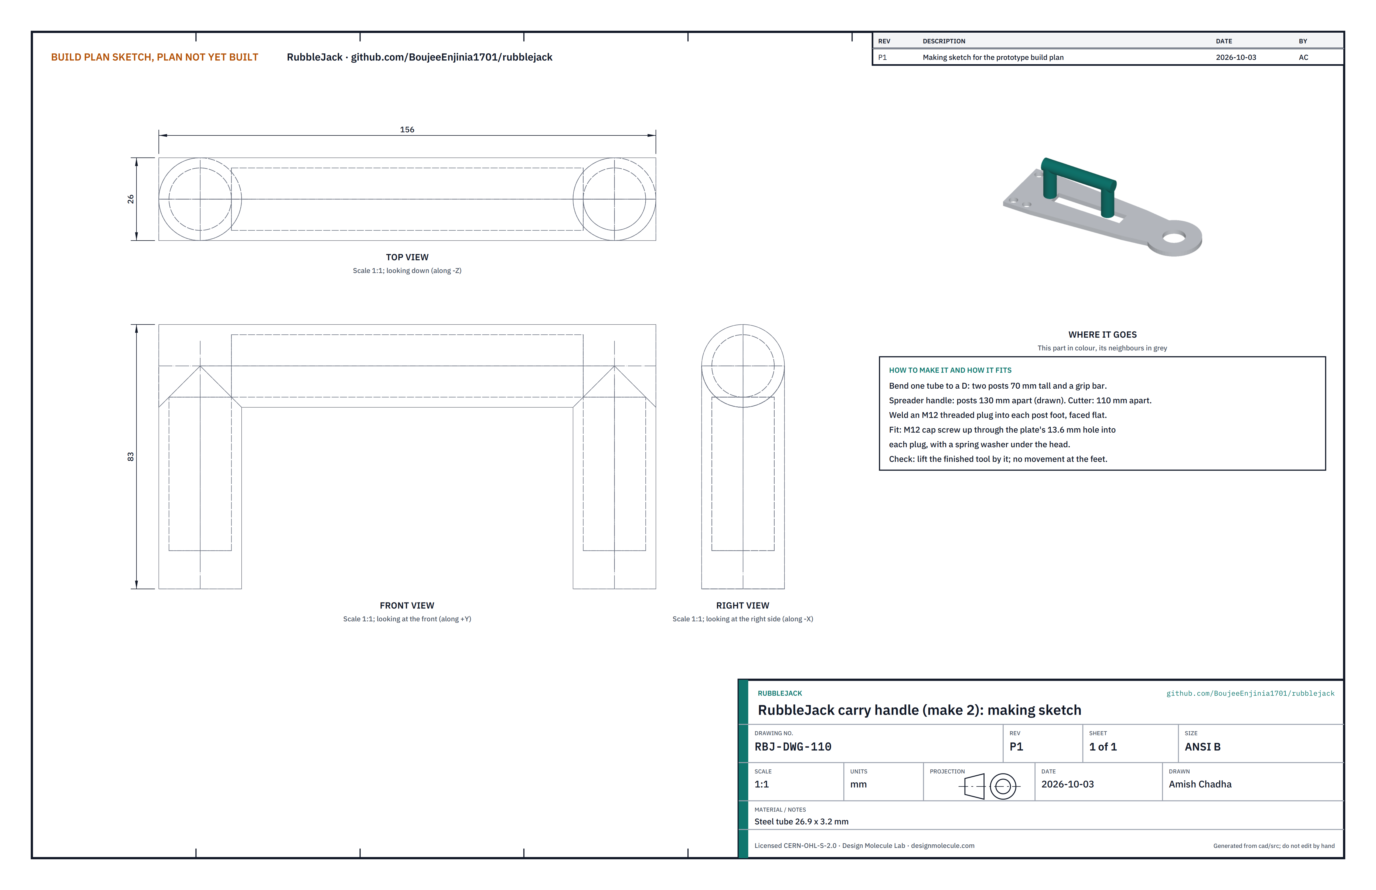
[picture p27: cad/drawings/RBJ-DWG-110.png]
Figure 11. Making sketch of the carry handle


*Figure 11. Making sketch RBJ-DWG-110.*

**What it is.** A D handle bent from 26.9 x 3.2 mm steel tube: two posts 70 mm tall, 130 mm apart for the spreader and 110 mm apart for the cutter, with an M12 threaded plug welded into each post foot and faced flat.

**How it fits.** Two M12 cap screws with spring washers come up through the upper plate into the plugs (Figure 24).

**Check.** Lift the finished tool by it; nothing moves at the feet.

### 3.11 Blade carrier

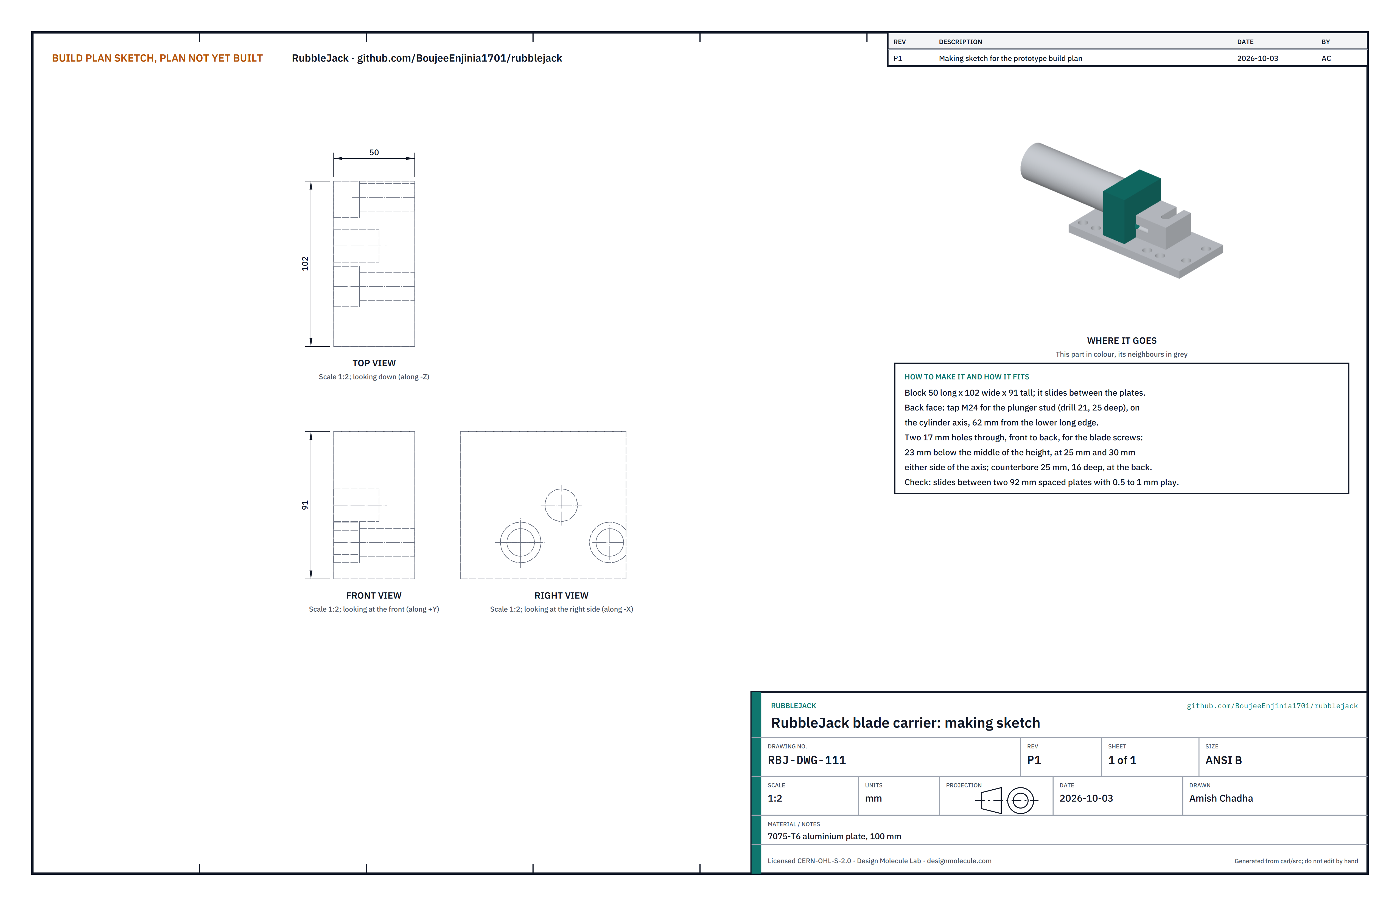
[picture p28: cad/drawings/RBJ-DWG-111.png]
Figure 12. Making sketch of the blade carrier


*Figure 12. Making sketch RBJ-DWG-111.*

**What it is.** The block on the cutter's plunger that carries the moving blade and slides between the cutter plates. 7075-T6 aluminium, 50 mm long, 102 mm wide, 91 mm tall.

**How to make it.**

1. Mill to size; the 91 mm height gives 0.5 mm of play each side between the plates.
2. In the back face, on the cylinder axis, 62 mm up from the lower long edge, drill 21 mm and tap M24, 25 mm deep.
3. Drill two 17 mm holes through, front to back, 23 mm below the middle of the height, 25 mm below and 30 mm above the cylinder axis; counterbore them 25 mm, 16 mm deep, from the back.

**How it fits.** The moving blade bolts to its front face with two M16 screws from the counterbores (Figure 25); it screws onto the plunger's M24 stud.

**Check.** It slides between two plates set 92 mm apart with 0.5 to 1 mm of play.

### 3.12 Moving blade

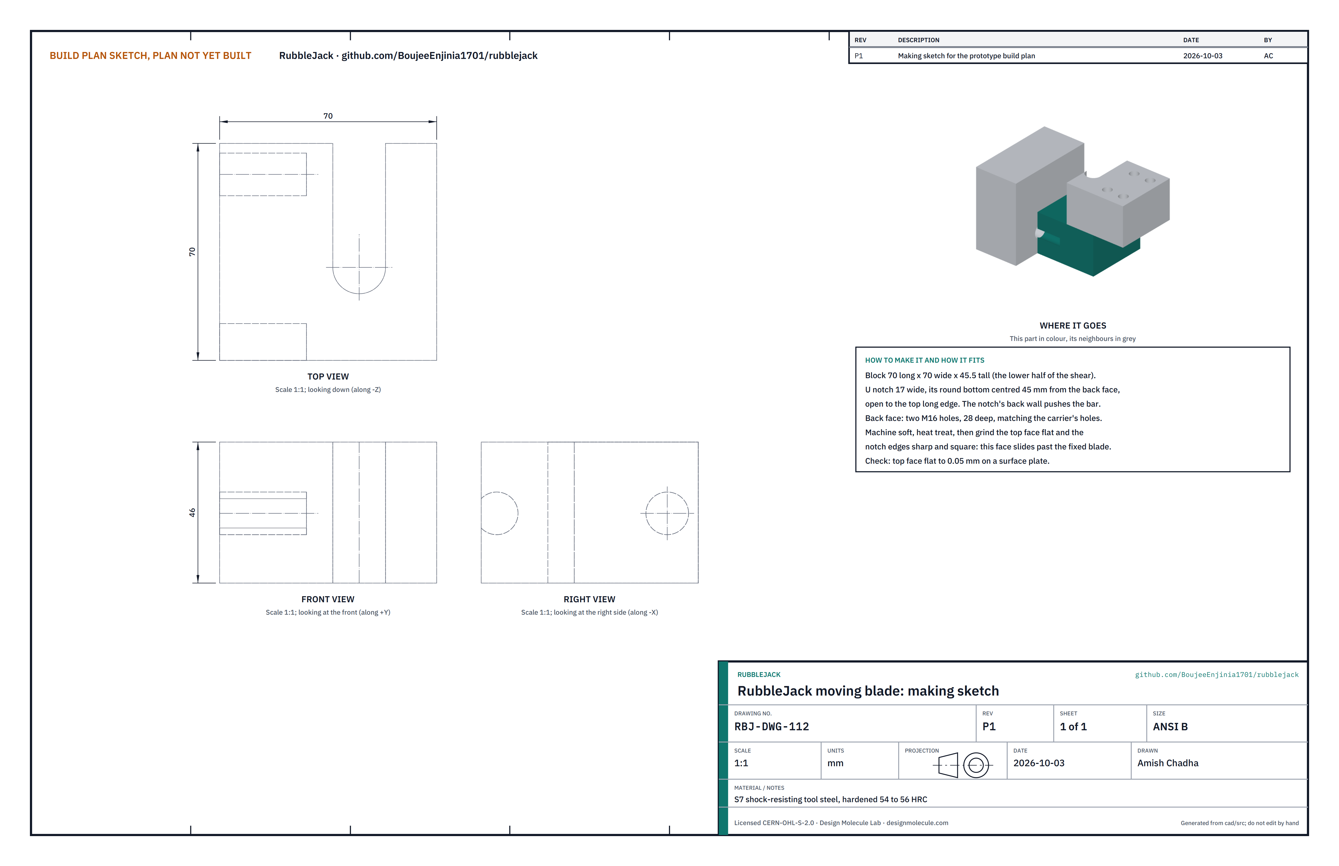
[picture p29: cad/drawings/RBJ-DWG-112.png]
Figure 13. Making sketch of the moving blade


*Figure 13. Making sketch RBJ-DWG-112.*

**What it is.** The lower half of the shear: S7 shock-resisting tool steel, 70 x 70 x 45.5 mm, hardened to 54 to 56 HRC.

**How to make it.**

1. Machine the block soft. Cut a 17 mm U notch, its round bottom centred 45 mm from the back face, open to the top long edge.
2. Drill and tap two M16 holes 28 mm deep in the back face, matching the carrier's holes.
3. Heat treat; grind the top face flat and the notch edges sharp and square.

**How it fits.** Bolted to the carrier; its top face slides 0.2 mm under the fixed blade (Figure 26).

**Check.** The top face is flat to 0.05 mm on a surface plate.

### 3.13 Fixed blade

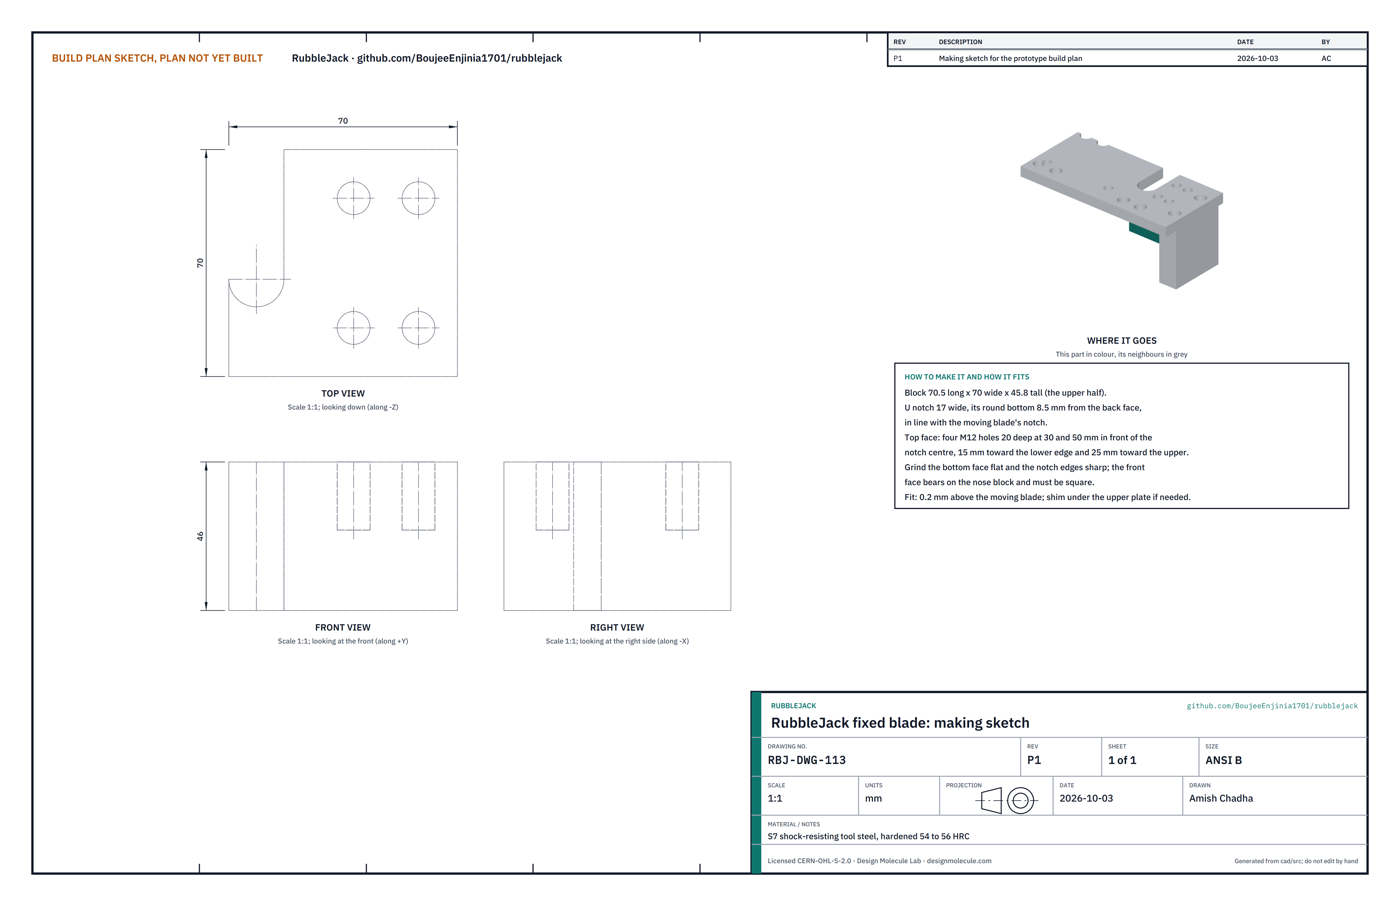
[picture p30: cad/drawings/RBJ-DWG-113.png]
Figure 14. Making sketch of the fixed blade


*Figure 14. Making sketch RBJ-DWG-113.*

**What it is.** The upper half of the shear: S7 tool steel, 70.5 x 70 x 45.8 mm, hardened to 54 to 56 HRC.

**How to make it.**

1. Machine soft; cut the same 17 mm U notch, its round bottom 8.5 mm from the back face.
2. Drill and tap four M12 holes 20 mm deep in the top face, at 30 and 50 mm in front of the notch centre, 15 mm toward the lower edge and 25 mm toward the upper.
3. Heat treat; grind the bottom face flat, the notch edges sharp and the front face square.

**How it fits.** Its front face bears on the nose block; four M12 screws through the upper plate hold it 0.2 mm above the moving blade (Figure 26).

**Check.** With both blades on a surface plate, the notches line up.

### 3.14 Nose block

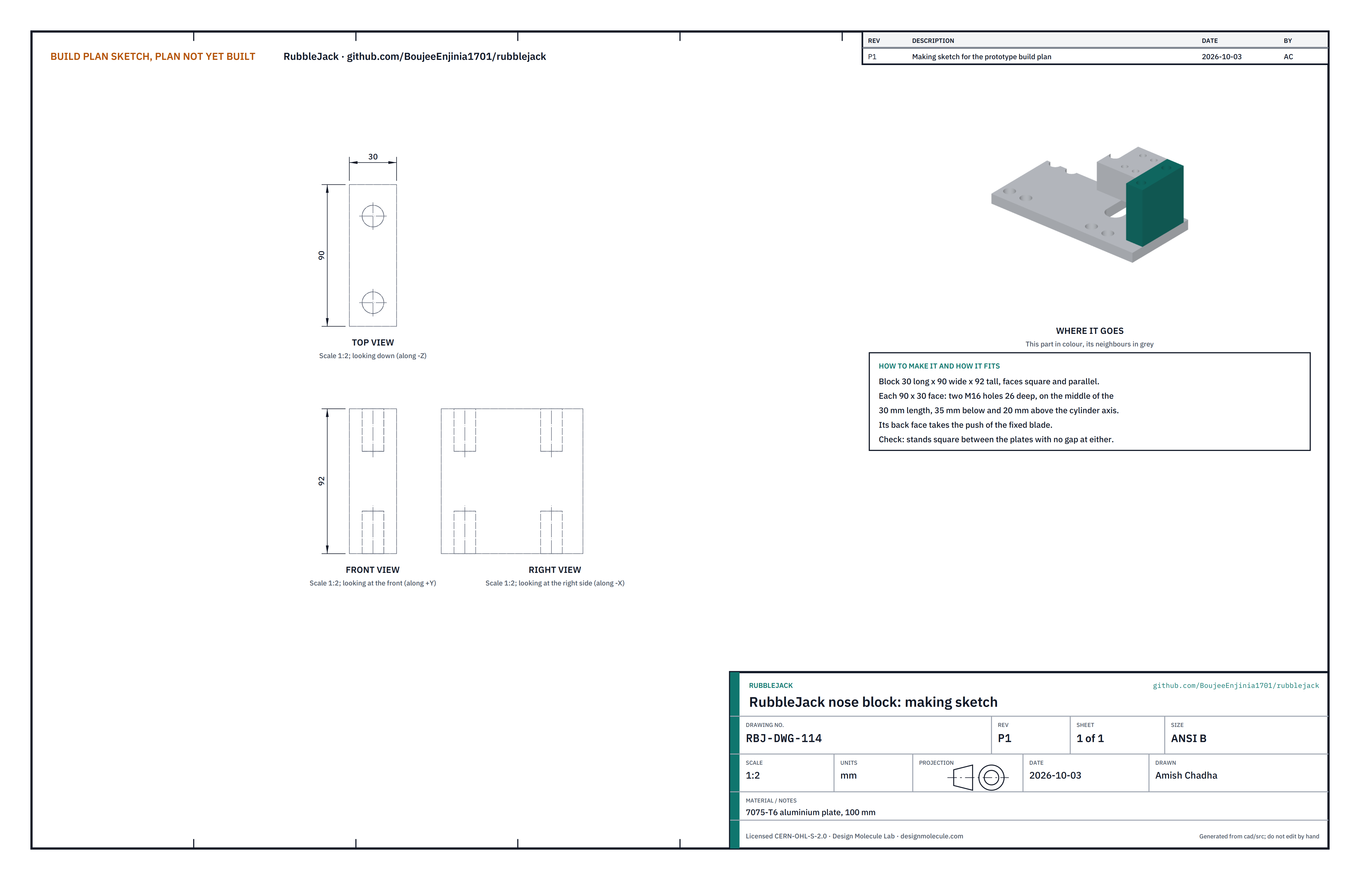
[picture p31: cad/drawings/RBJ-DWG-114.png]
Figure 15. Making sketch of the nose block


*Figure 15. Making sketch RBJ-DWG-114.*

**What it is.** A 7075-T6 block 30 x 90 x 92 mm that takes the fixed blade's thrust. Each 90 x 30 face has two M16 holes, 26 mm deep, on the middle of the 30 mm length, 35 mm below and 20 mm above the cylinder axis.

**How it fits.** Between the plates at the front, held by two screws in each plate; the fixed blade bears on its back face (Figure 26).

**Check.** It stands square between the plates with no gap at either.

### 3.15 Stop bar

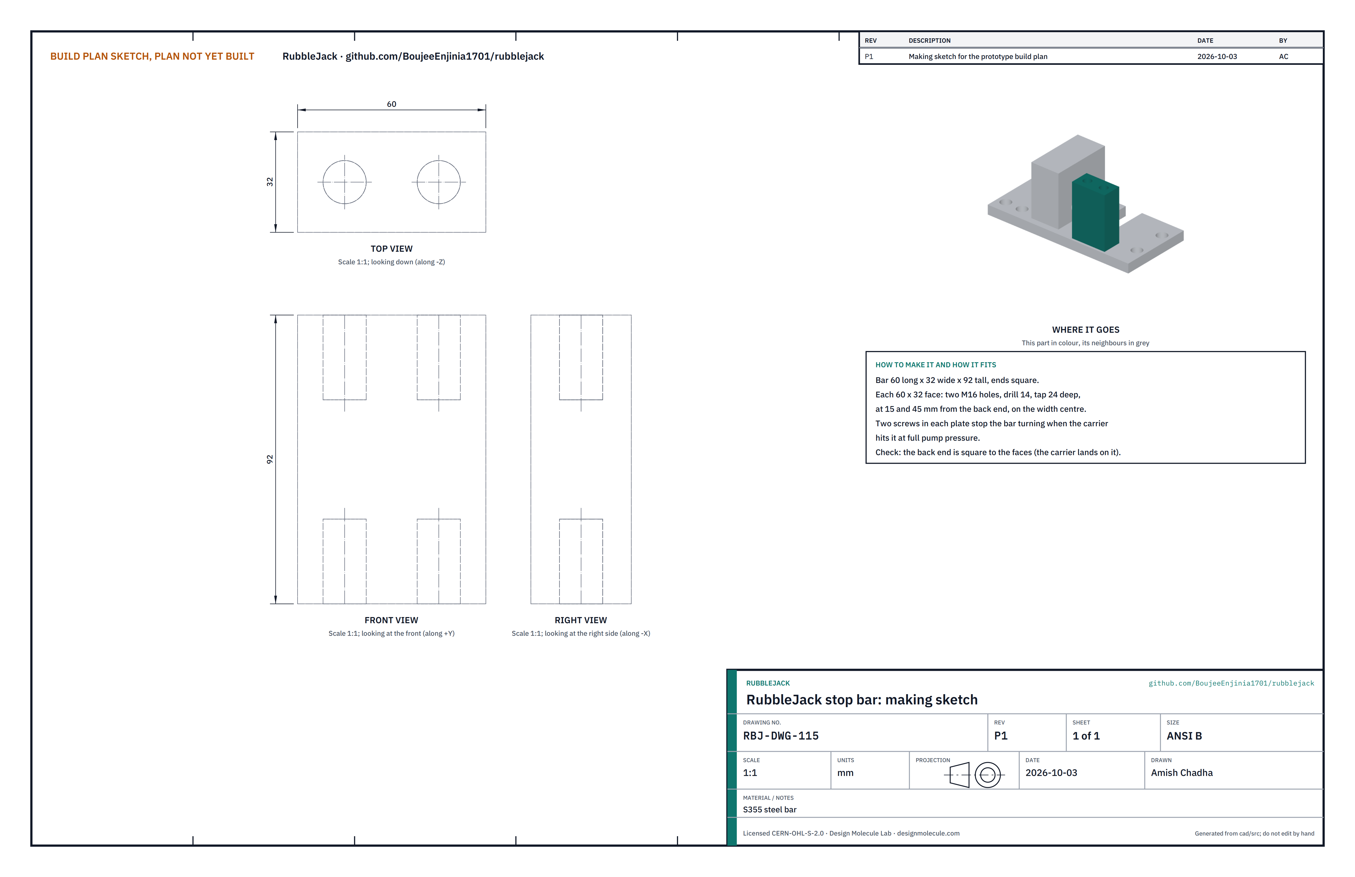
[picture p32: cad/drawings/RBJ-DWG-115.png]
Figure 16. Making sketch of the stop bar


*Figure 16. Making sketch RBJ-DWG-115.*

**What it is.** An S355 steel bar 60 x 32 x 92 mm that ends the cutter's stroke. Each 60 x 32 face has two M16 holes, drilled 14 mm and tapped 24 mm deep, 15 and 45 mm from the back end, on the width centre.

**How it fits.** Between the plates below the blades; the carrier lands on its back end 30 mm after the cut starts (Figure 27).

**Check.** The back end is square to the faces.

### 3.16 Cutter plates (make 2)

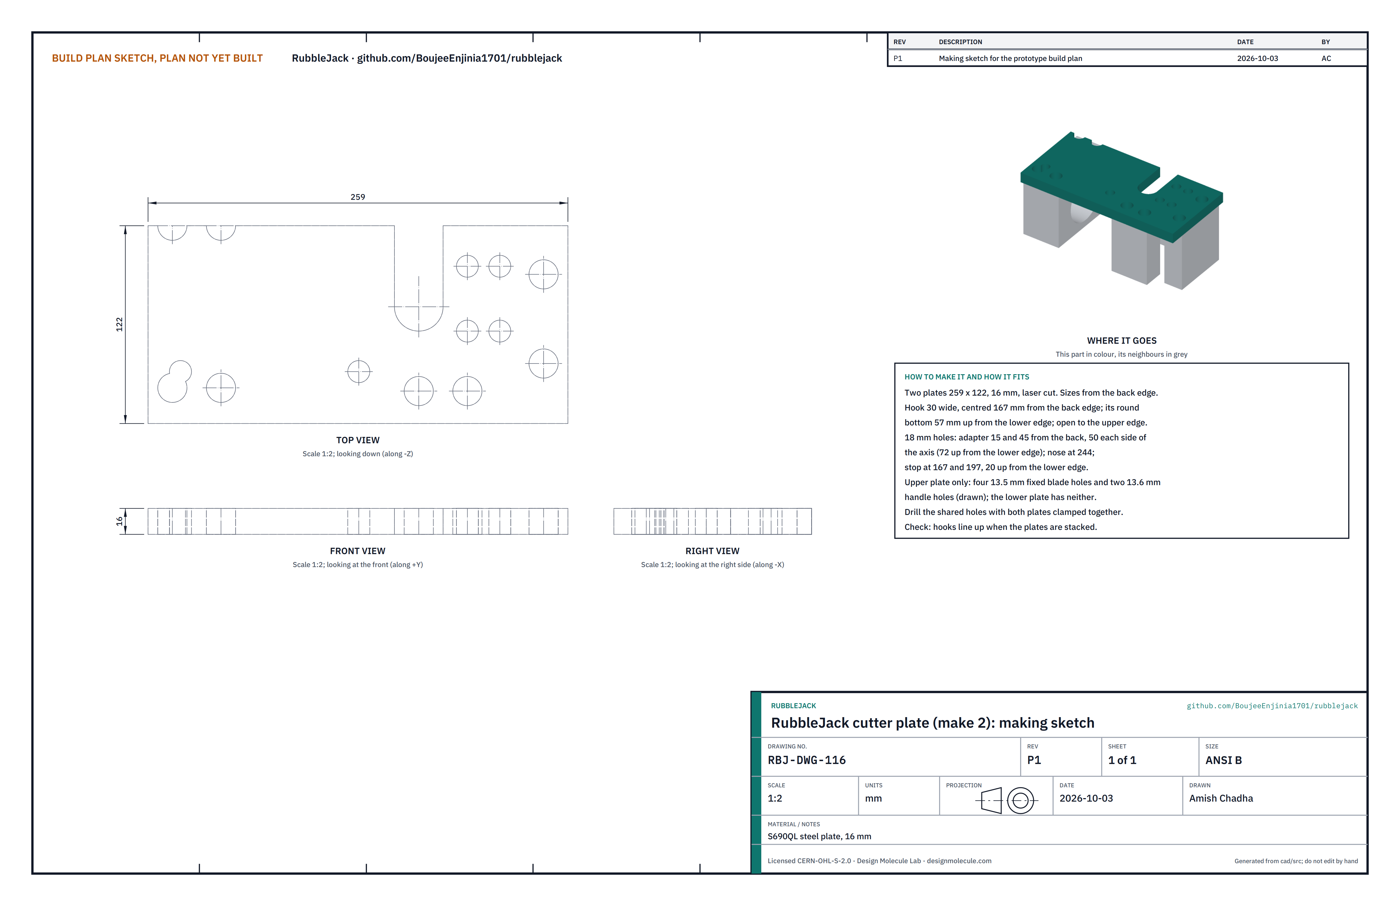
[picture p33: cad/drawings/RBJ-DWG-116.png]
Figure 17. Making sketch of the cutter plate


*Figure 17. Making sketch RBJ-DWG-116.*

**What it is.** The two steel plates that hold the cutter together, with a hook for the bar. S690QL high-strength steel, 16 mm, 259 x 122 mm.

**How to make it.**

1. Laser cut both plates with the 30 mm hook: centred 167 mm from the back edge, its round bottom 57 mm up from the lower edge, open to the upper edge.
2. With the plates clamped together, drill the shared 18 mm holes: adapter at 15 and 45 mm from the back, 50 mm each side of the axis (the axis is 72 mm up from the lower edge); nose at 244 mm from the back, 37 and 92 mm up; stop at 167 and 197 mm from the back, 20 mm up.
3. Upper plate only: four 13.5 mm fixed blade holes and two 13.6 mm handle holes, as the sketch shows.

**How it fits.** Each bolts to the adapter's faces, and to the nose block and stop bar; the upper plate also holds the fixed blade and handle.

**Check.** The hooks line up when the plates are stacked.

### 3.17 Ram base plate

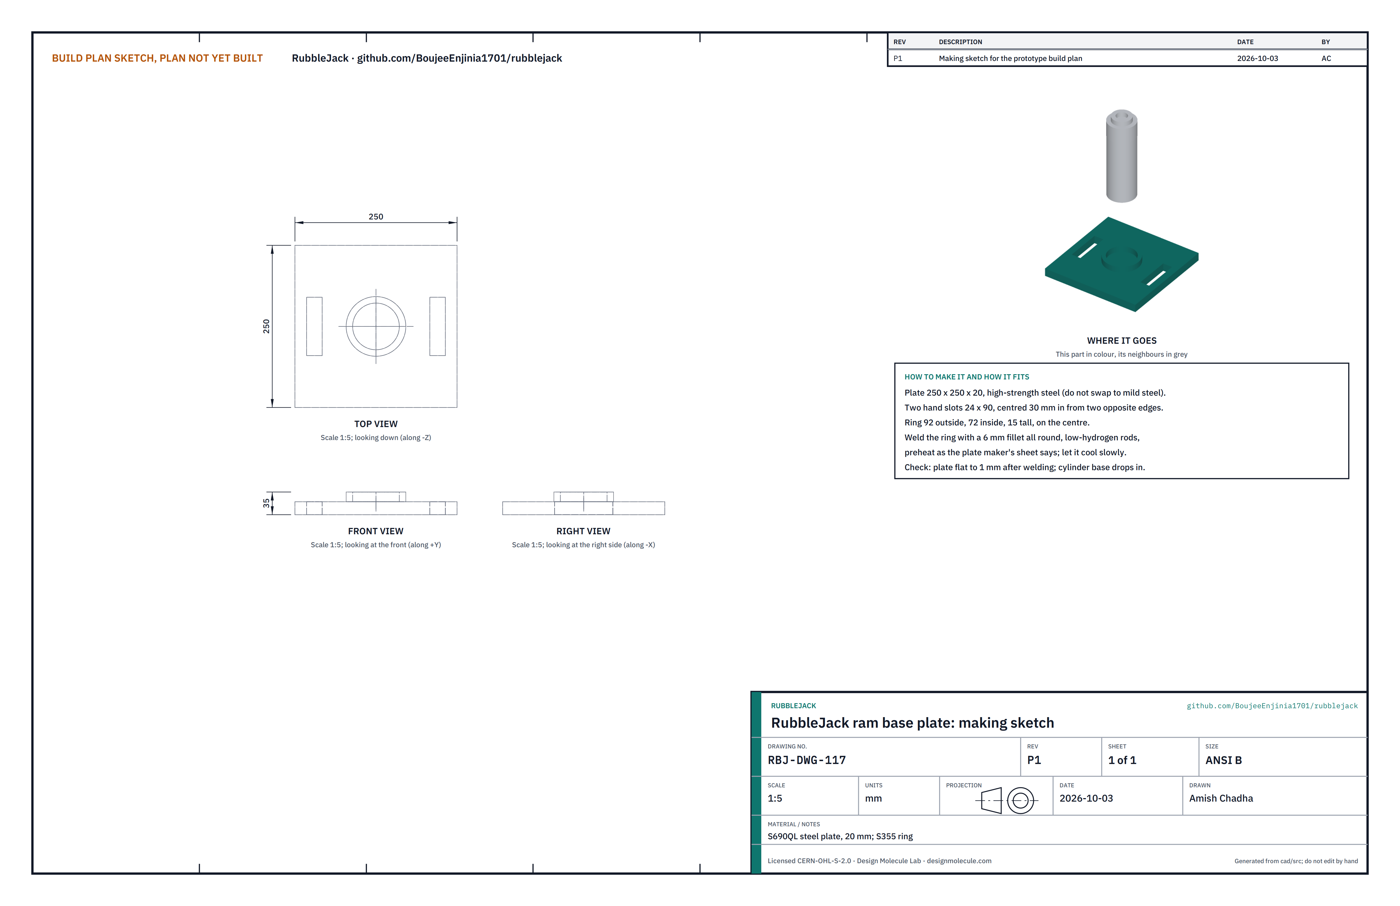
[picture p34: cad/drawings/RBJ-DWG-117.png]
Figure 18. Making sketch of the ram base plate


*Figure 18. Making sketch RBJ-DWG-117.*

**What it is.** A 250 mm square plate of S690QL high-strength steel, 20 mm thick, with two 24 x 90 mm hand slots and a locating ring 92 mm outside, 72 mm inside and 15 mm tall welded on the centre. Do not swap it for mild steel.

**How to make it.** Cut the plate and slots; turn the ring from S355; weld it with a 6 mm fillet all round using low-hydrogen consumables, preheating as the plate maker's sheet says; let it cool slowly.

**How it fits.** The cylinder base or the riser spigot drops into the ring (Figure 28). The plate always sits on hardwood cribbing.

**Check.** The plate is flat to 1 mm after welding.

### 3.18 Riser block

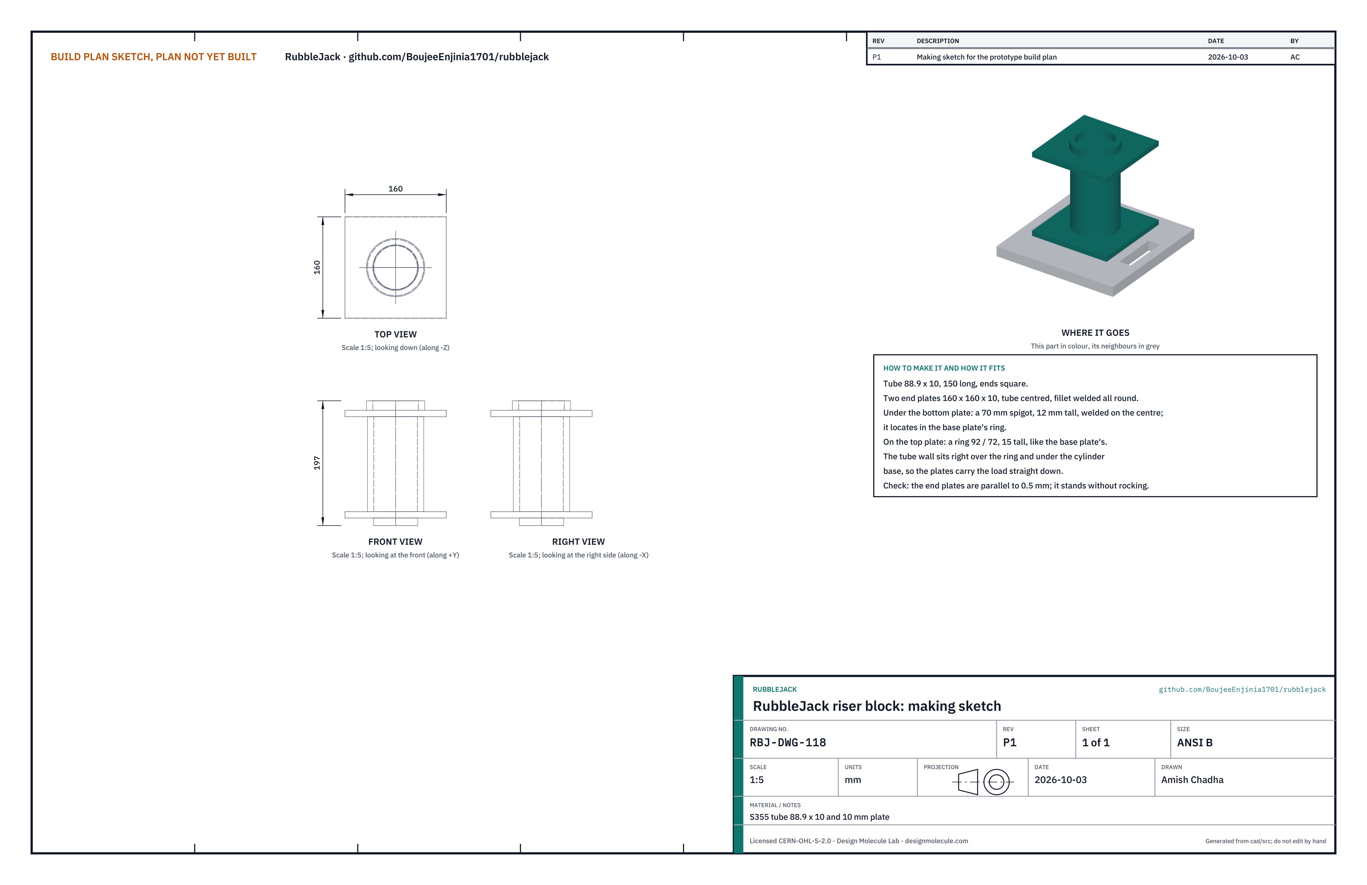
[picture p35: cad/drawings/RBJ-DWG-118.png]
Figure 19. Making sketch of the riser block


*Figure 19. Making sketch RBJ-DWG-118.*

**What it is.** An S355 tube 88.9 x 10 mm, 150 mm long, welded between two 160 mm square, 10 mm plates, with a 70 mm spigot 12 mm tall under the bottom plate and a ring like the base plate's on the top plate.

**How it fits.** Its spigot drops into the base plate's ring; the cylinder base drops into its top ring (Figure 28). It goes only under the cylinder.

**Check.** The end plates are parallel to 0.5 mm and it stands without rocking.

### 3.19 Bought components

| Component | What to buy | What to do to it |
| --- | --- | --- |
| Hand pump | Two-speed, 700 bar, internal relief at 700 bar, about 900 cm³ oil, for single-acting cylinders | Fill and bleed as the maker says |
| Gauge and adapter | 0 to 1,000 bar glycerine gauge and a 700 bar gauge adapter | Fit to the pump outlet with thread sealant |
| Hoses and couplers | Two 2 m hoses, 700 bar, at least 4 to 1 burst; coupler halves for the three cylinders; dust caps | Check every coupler is the same series |
| Cylinders (3) | 15 t single-acting, spring return, 101 mm stroke, collar thread, plunger with an attachment thread | Measure the collar and plunger threads before making the adapters and studs |
| Tilting saddle | For a 15 t cylinder | None |
| Screws and studs | M16 and M12 class 12.9 cap screws, M24 class 10.9 studs, hardened and spring washers, circlips | None |
| Carry bags (4) | Heavy nylon tool bags with straps | None |

## 4. Putting it together

Torque every class 12.9 screw to the fastener maker's table, using the lower value for threads tapped in aluminium, with thread-locker on studs and on screws into aluminium.

### Step 1: collar adapter onto the spreader cylinder

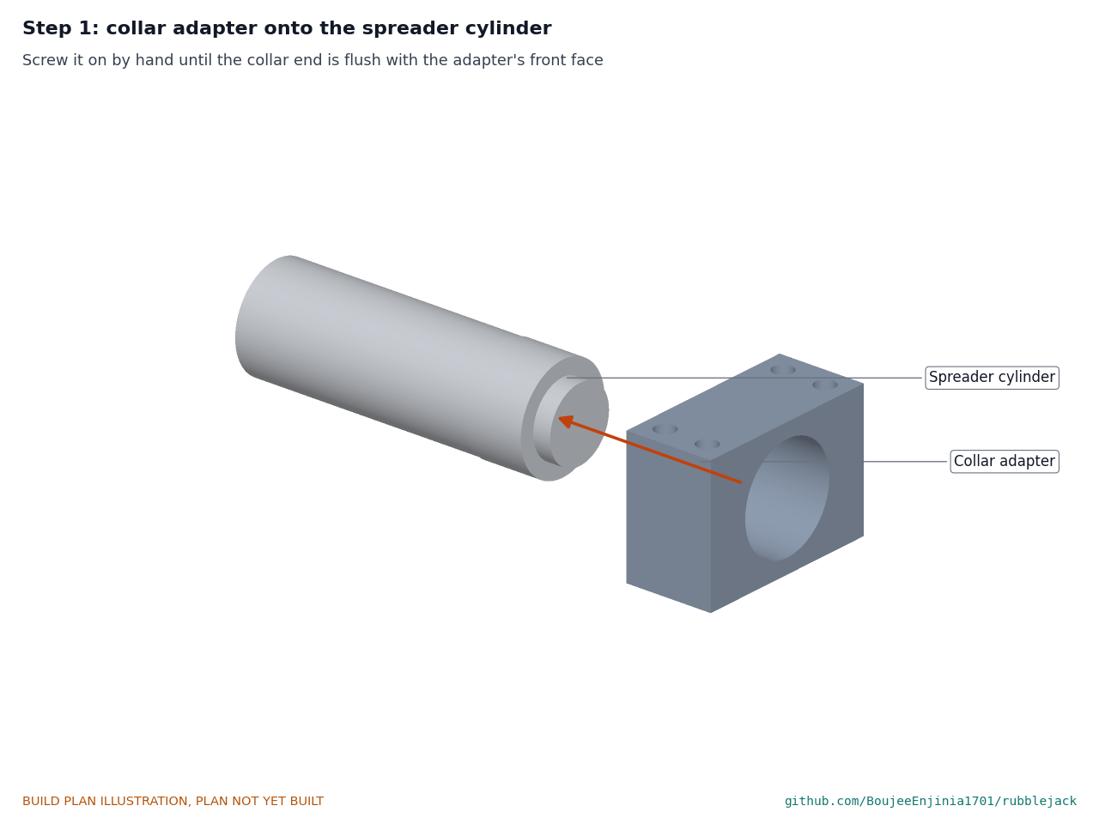
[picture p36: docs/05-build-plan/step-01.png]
Step 1


Screw the adapter onto the collar by hand until the collar's end is flush with its front face.

### Step 2: crosshead onto the plunger

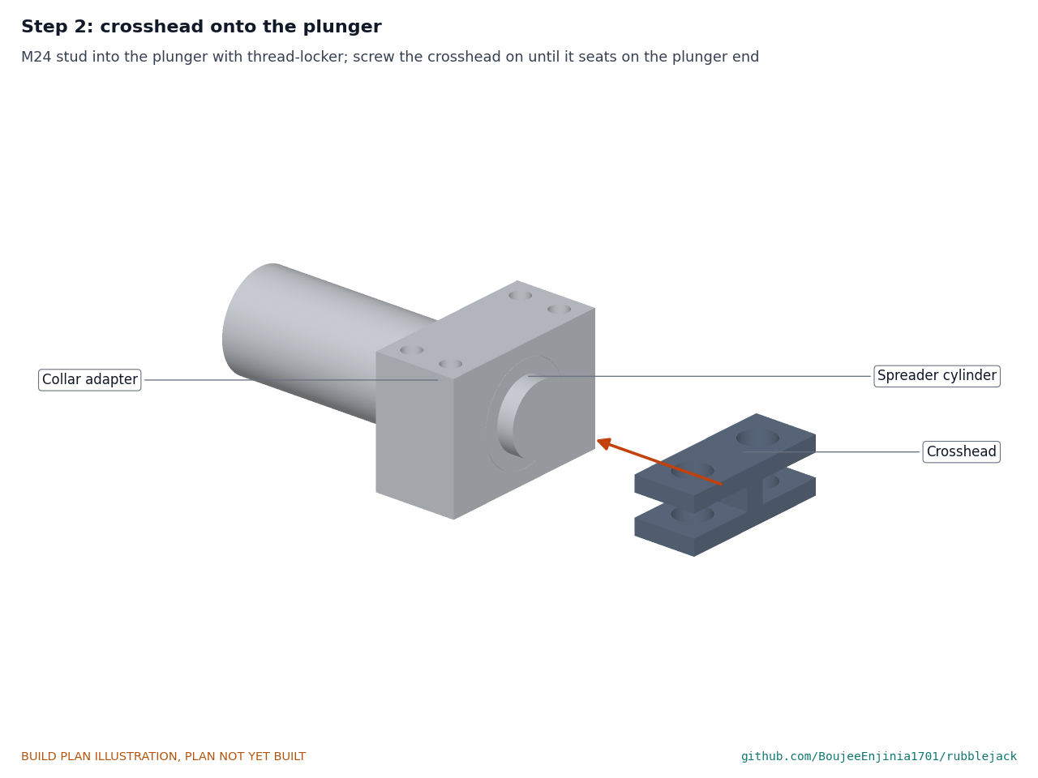
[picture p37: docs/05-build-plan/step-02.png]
Step 2


Fit the M24 stud into the plunger with thread-locker, then screw the crosshead on until it seats on the plunger end. The plunger turns in the cylinder, so the crosshead's angle is set later by the links.

### Step 3: links onto the crosshead

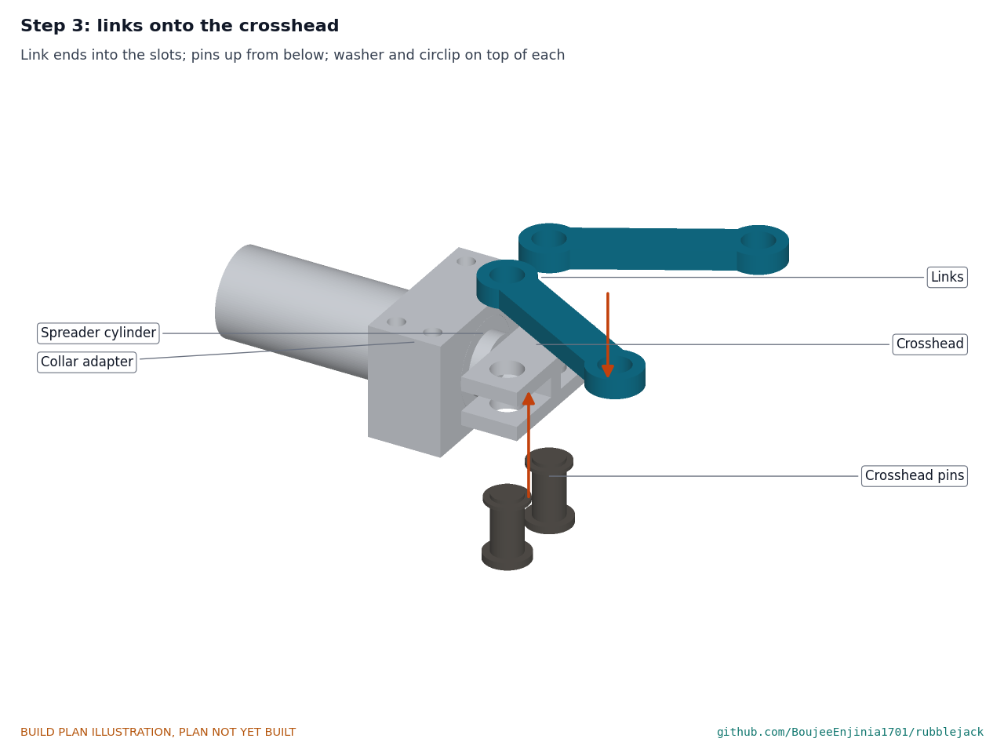
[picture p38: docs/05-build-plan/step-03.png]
Step 3


Put a link eye into each crosshead slot and push a 48 mm link pin up from below; washer and circlip on top of each (Figure 21).

### Step 4: lower frame plate onto the adapter

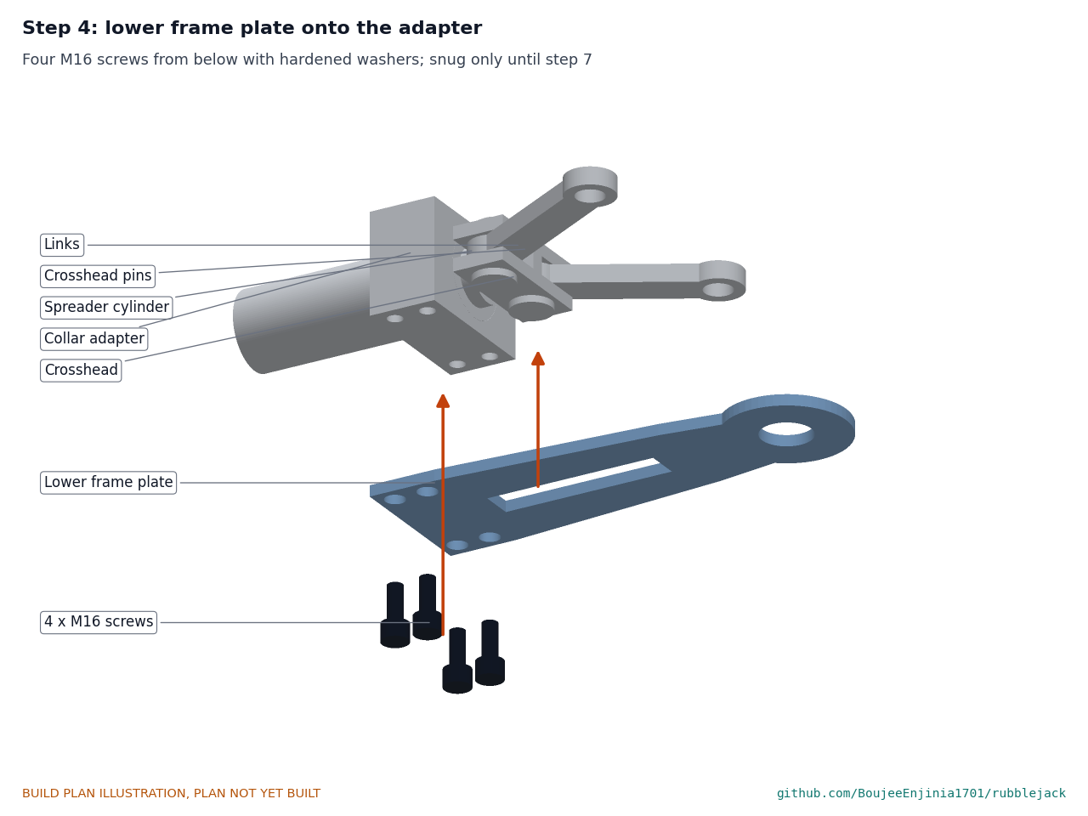
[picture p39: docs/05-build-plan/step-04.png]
Step 4


Hold the lower plate flat against the adapter's lower face and fit four M16 screws from below with hardened washers. Snug only until step 7.

### Step 5: pair the jaw arms

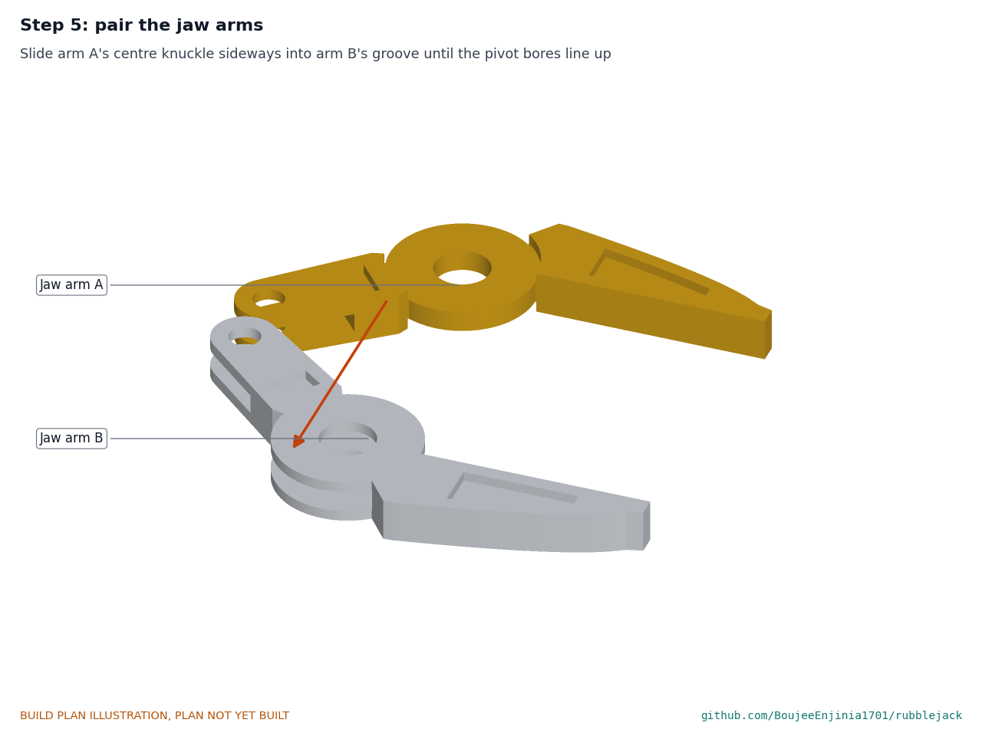
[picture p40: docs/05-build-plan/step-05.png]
Step 5


Slide arm A's centre knuckle sideways into arm B's groove until the pivot bores line up.

### Step 6: spacer and jaw arms onto the lower plate

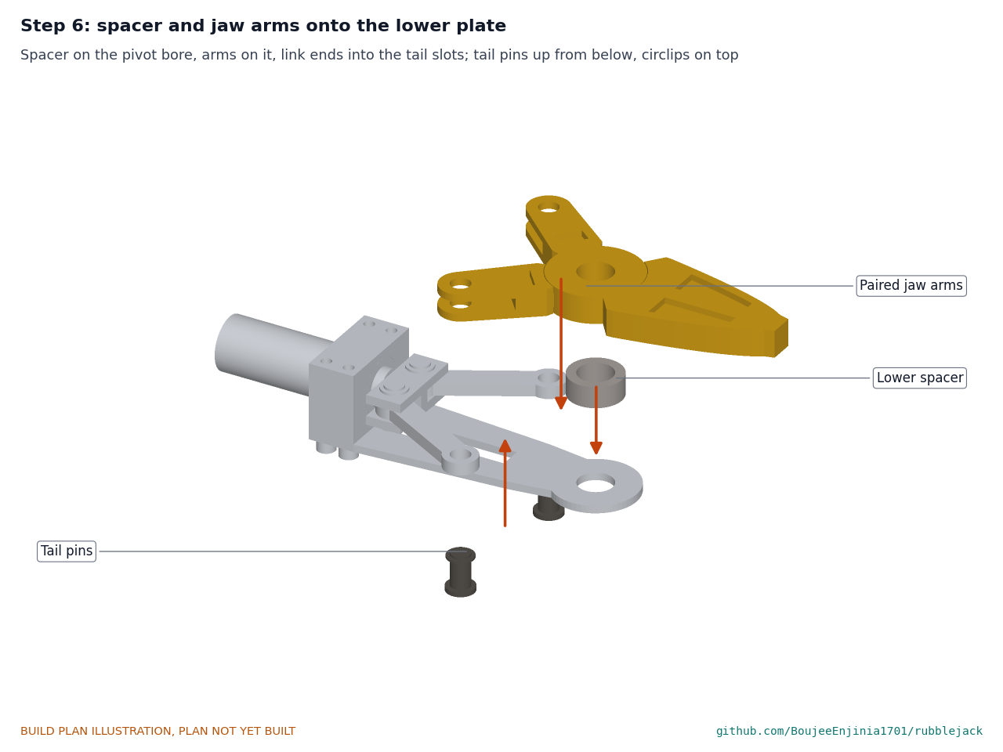
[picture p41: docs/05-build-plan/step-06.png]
Step 6


Set the tool on two wooden blocks so the pin can come from below. Put the lower spacer on the plate's pivot bore and the paired arms on it, with the links' free eyes in the tail slots. Push the two 44 mm tail pins up from below; washers and circlips on top (Figure 22).

### Step 7: upper spacer, upper plate and main pin

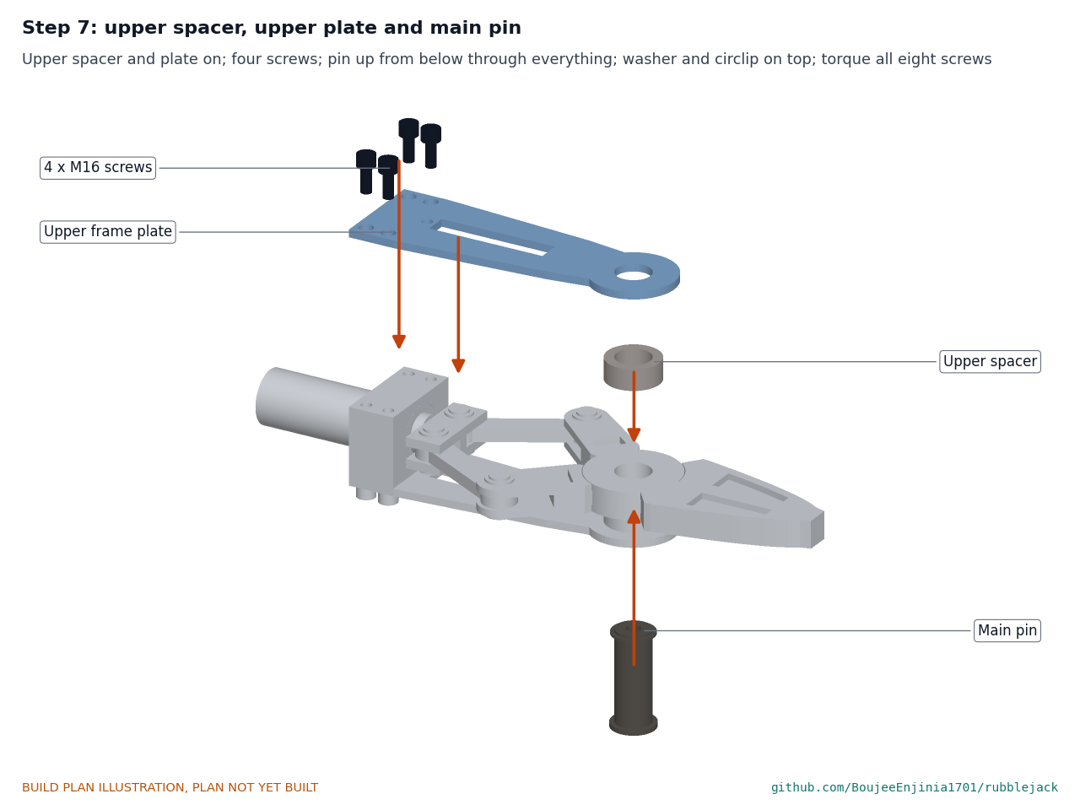
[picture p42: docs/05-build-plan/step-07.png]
Step 7


Put the upper spacer on the arms and the upper plate on the adapter; fit its four screws. Push the main pin up from below through everything; washer and circlip on top (Figure 23). Torque all eight adapter screws. **Hold point:** the arms turn by hand through their whole opening with no bind.

### Step 8: carry handle onto the spreader

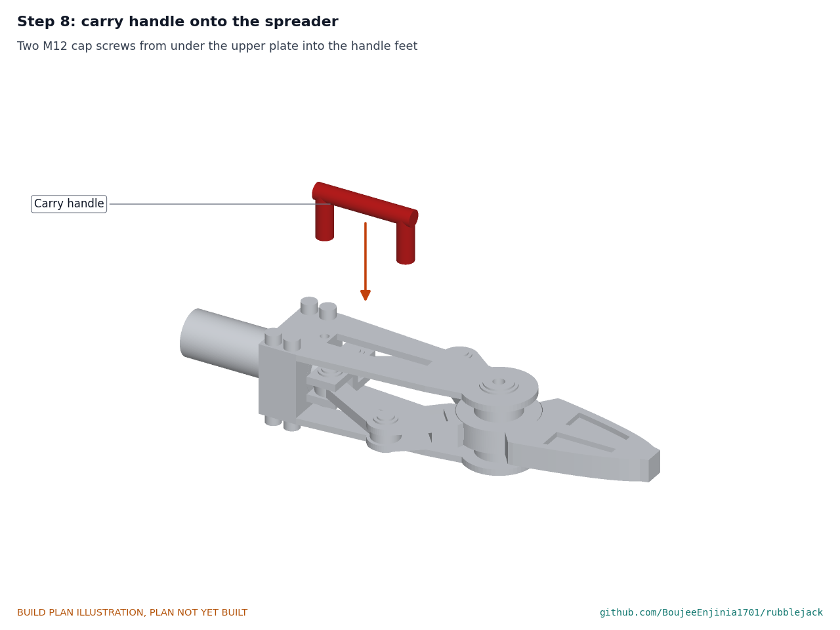
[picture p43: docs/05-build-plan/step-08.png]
Step 8


Two M12 cap screws with spring washers from under the upper plate into the handle feet (Figure 24).

### Step 9: collar adapter onto the cutter cylinder

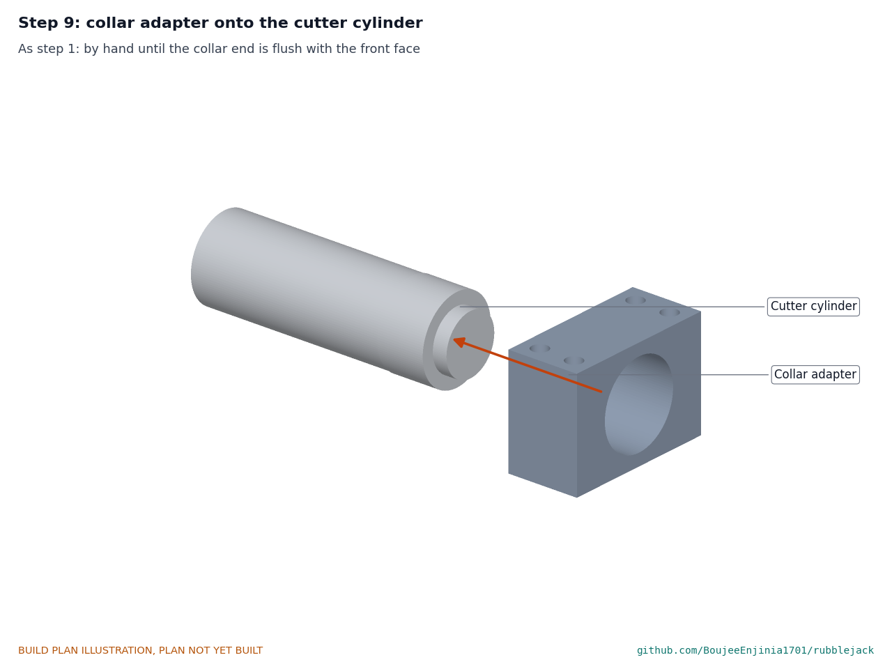
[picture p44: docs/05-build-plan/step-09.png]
Step 9


As step 1.

### Step 10: blade carrier onto the plunger

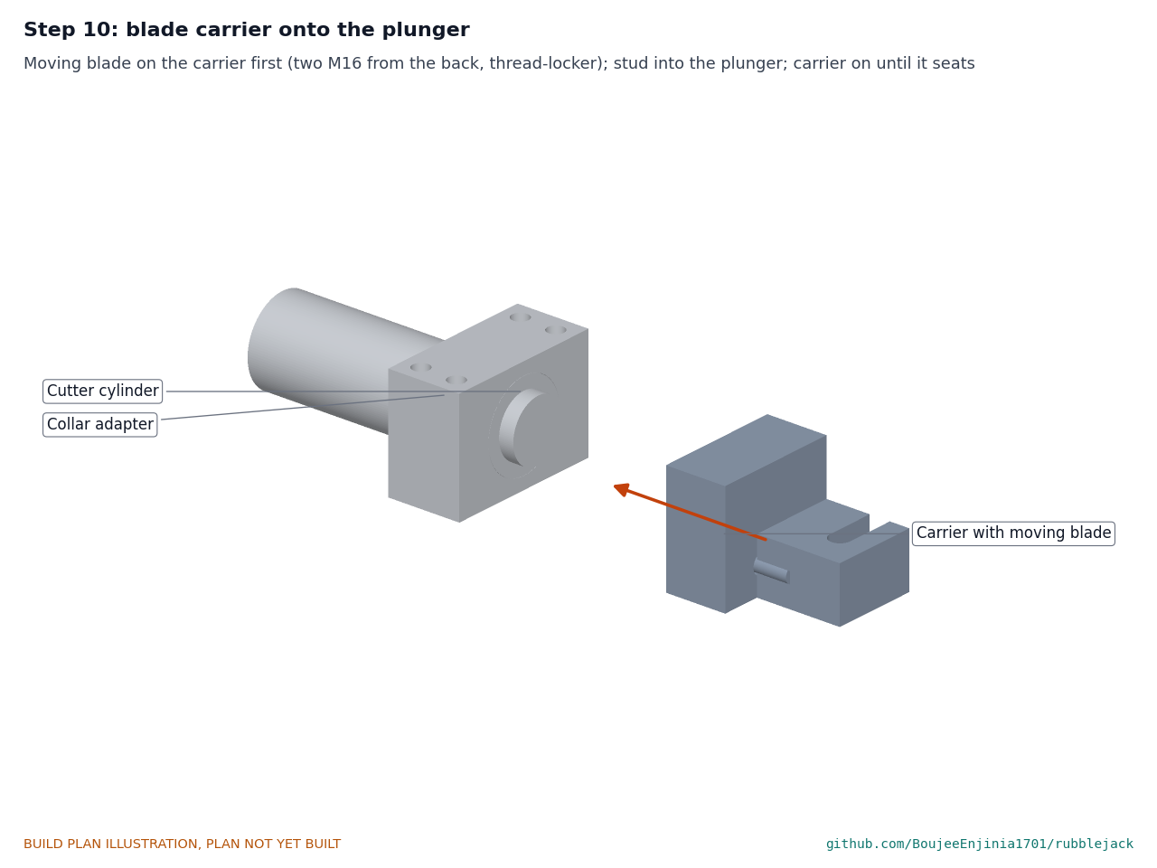
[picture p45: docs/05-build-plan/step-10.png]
Step 10


Bolt the moving blade to the carrier first with two M16 screws from the counterbores, with thread-locker (Figure 25). Fit the M24 stud into the plunger and screw the carrier on until it seats on the plunger end.

### Step 11: lower cutter plate onto the adapter

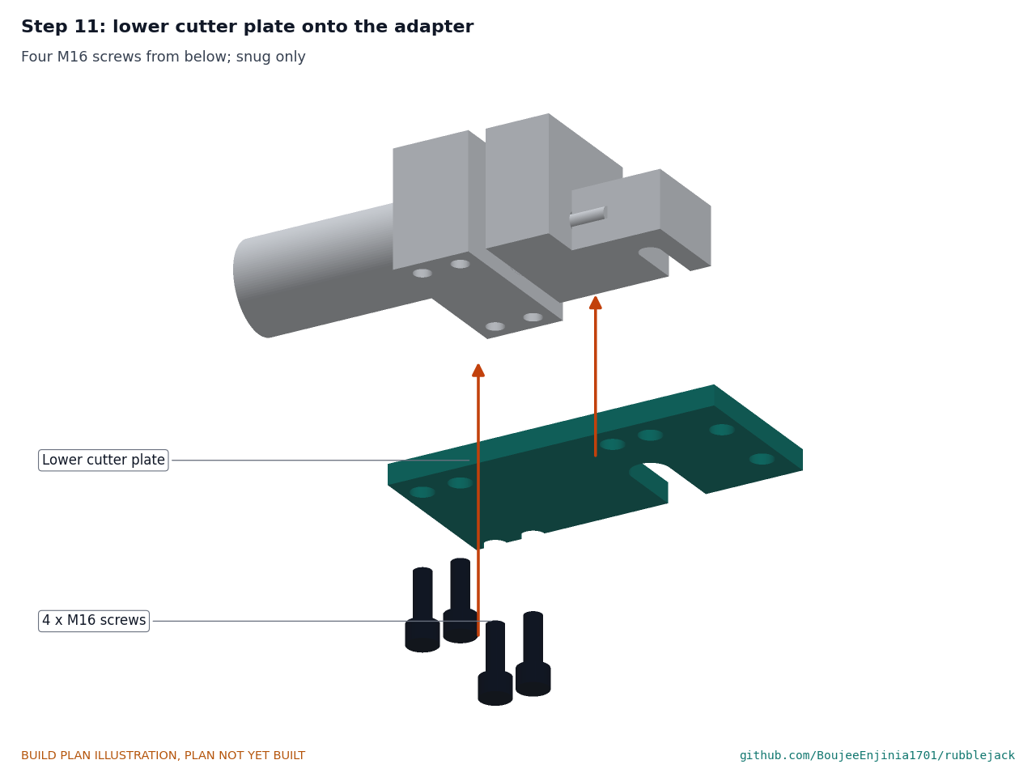
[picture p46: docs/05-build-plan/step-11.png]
Step 11


Four M16 screws from below; snug only.

### Step 12: fixed blade, nose block and stop bar

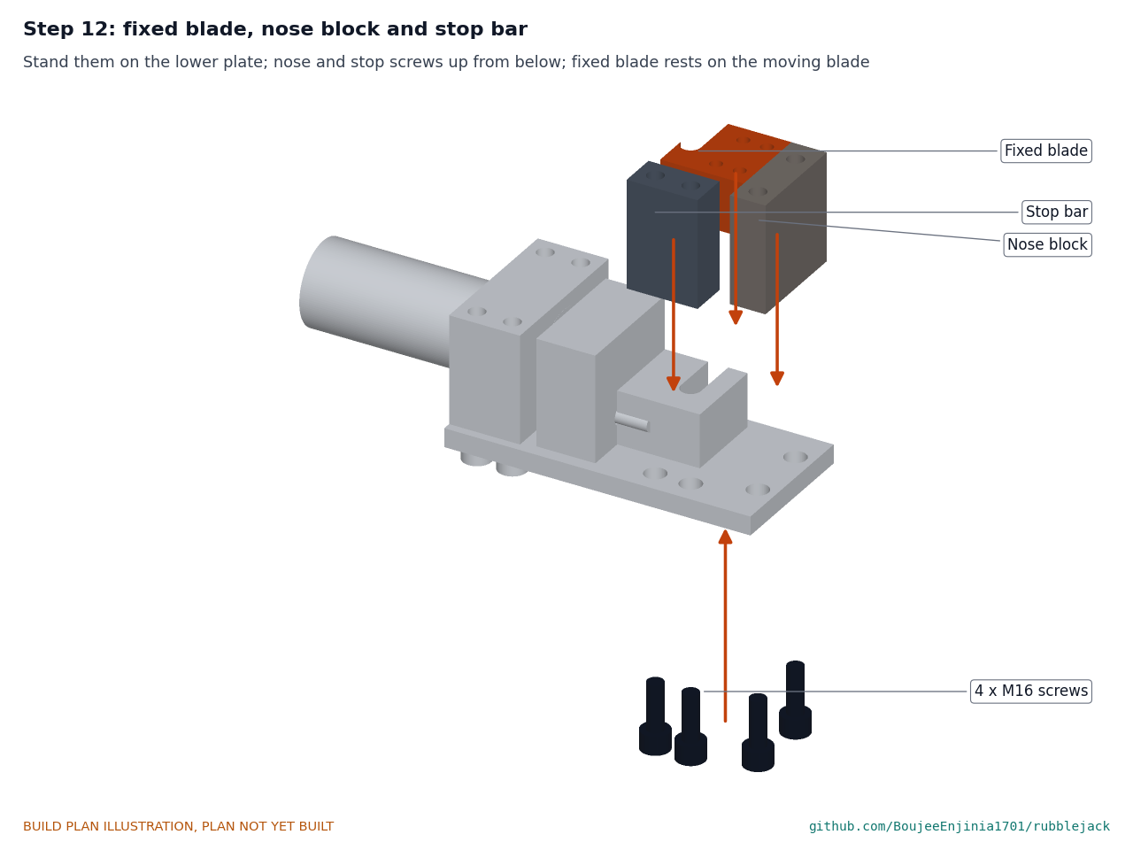
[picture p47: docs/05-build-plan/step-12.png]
Step 12


Stand the nose block and stop bar on the lower plate and fit their two screws each from below. Lay the fixed blade on the moving blade, notches in line, front face against the nose block.

### Step 13: upper cutter plate

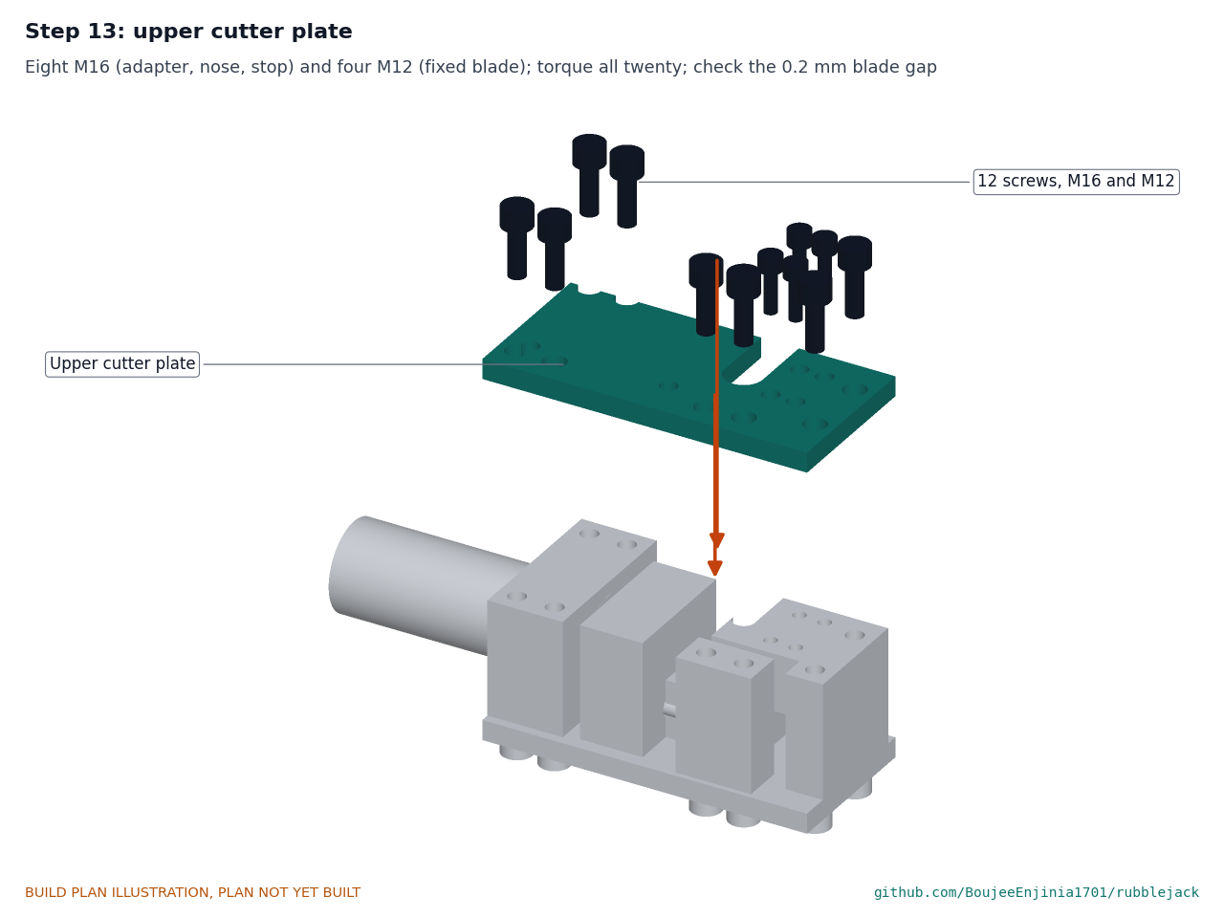
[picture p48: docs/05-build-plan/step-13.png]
Step 13


Put the upper plate on; fit four M16 adapter screws, two nose and two stop screws, and four M12 fixed blade screws. Torque all twenty. **Hold point:** a 0.2 mm feeler passes between the blades and the carrier slides by hand from open to the stop bar; shim under the upper plate at the fixed blade if the gap is short.

### Step 14: carry handle onto the cutter

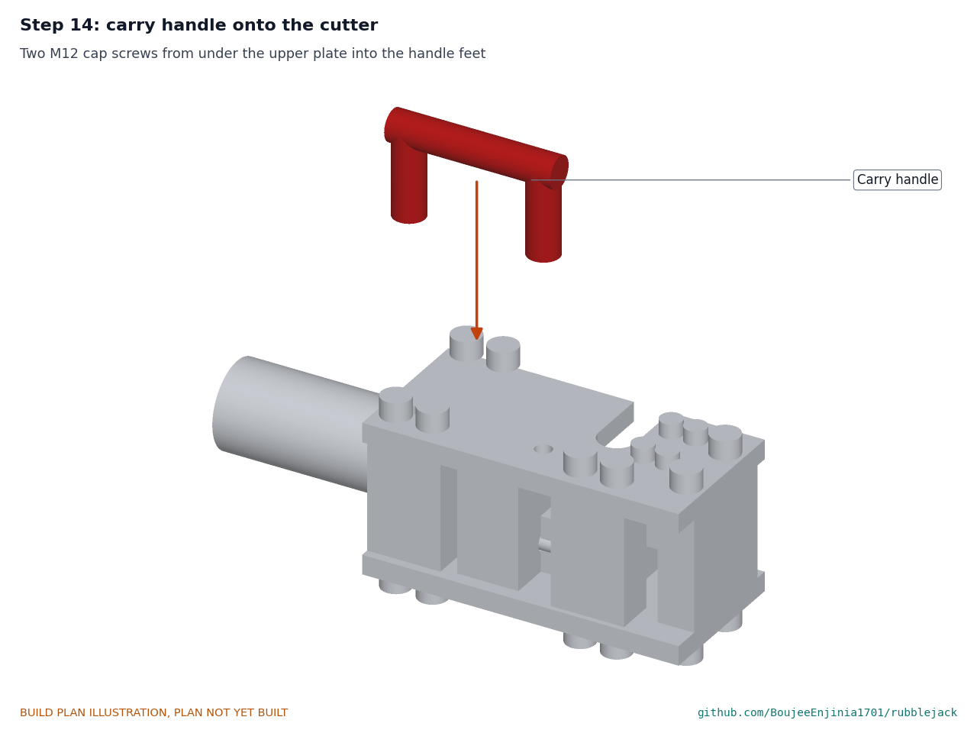
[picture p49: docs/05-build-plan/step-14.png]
Step 14


As step 8.

### Step 15: the lifting ram stack

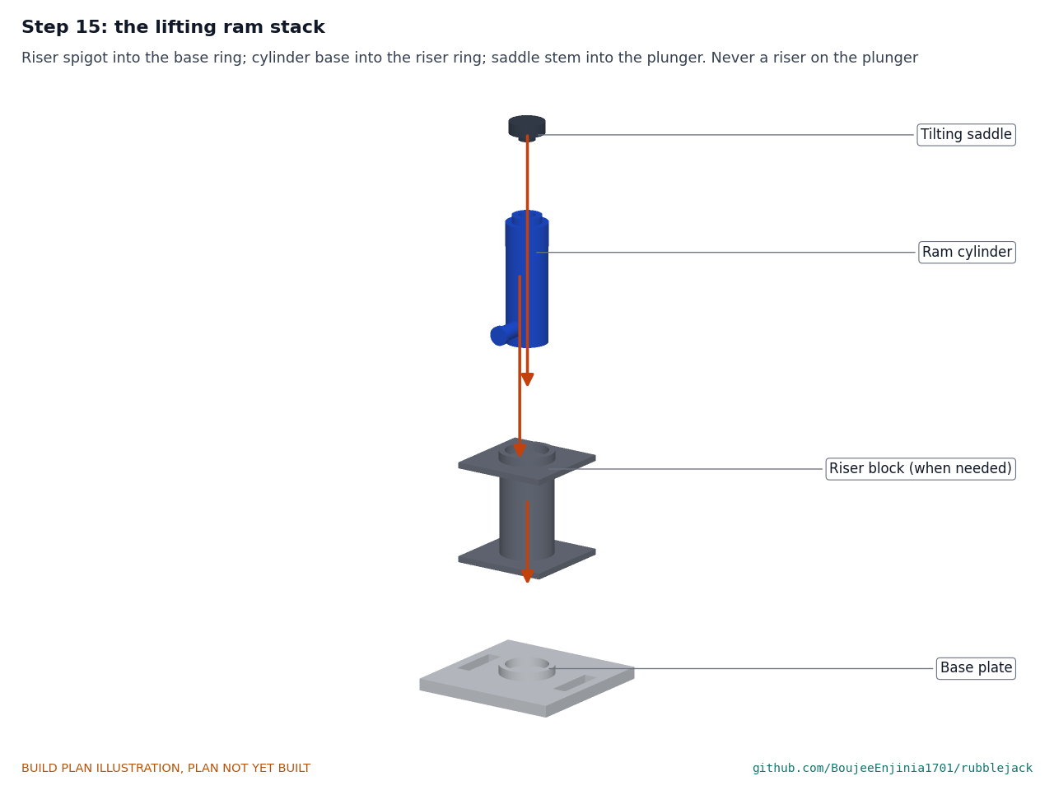
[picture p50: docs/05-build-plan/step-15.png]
Step 15


Drop the riser's spigot into the base plate's ring (only when the extra reach is needed), the cylinder's base into the riser's ring (or the base plate's ring), and the saddle's stem into the plunger (Figure 28). Never put the riser on top of the plunger.

### Step 16: gauge and hose onto the pump

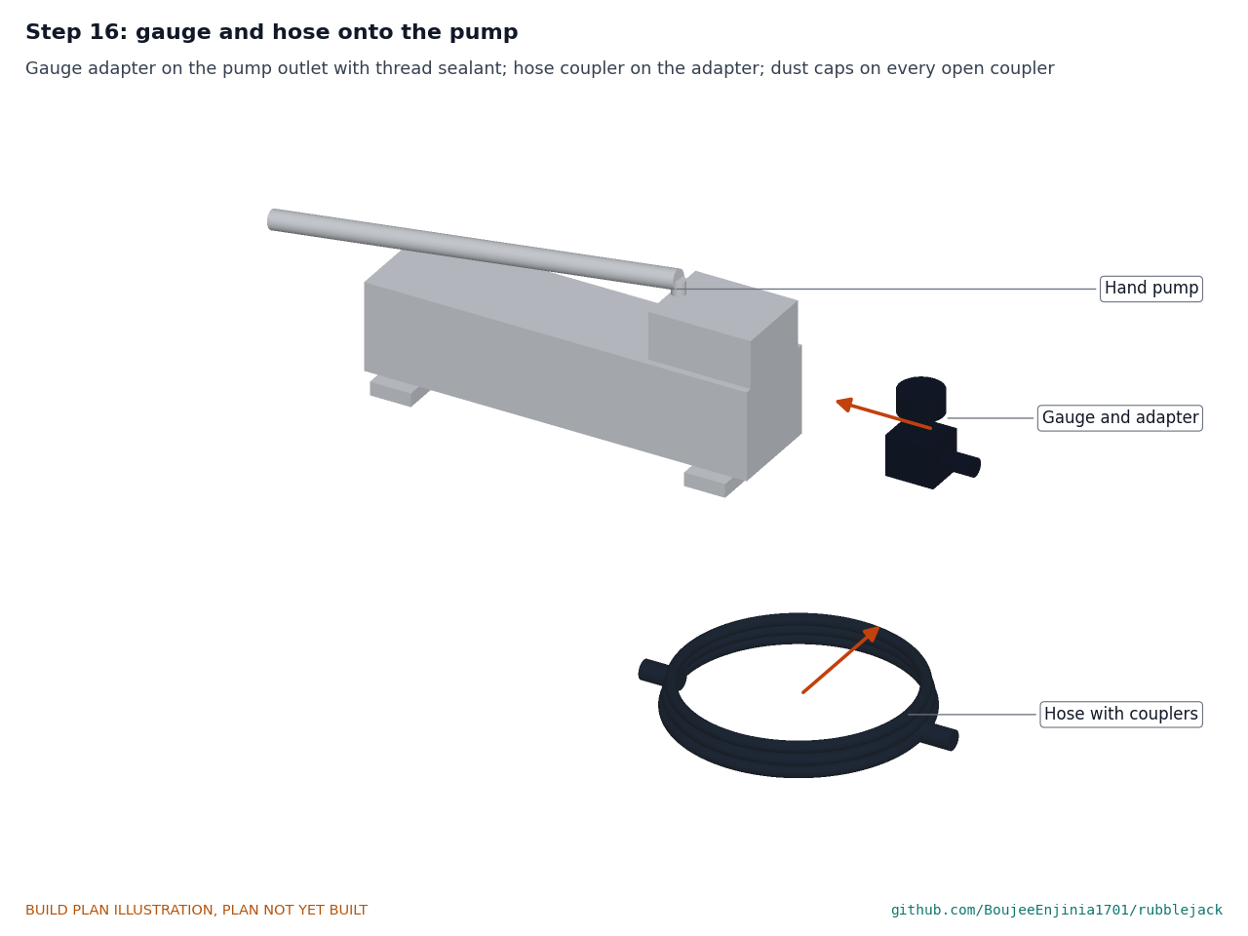
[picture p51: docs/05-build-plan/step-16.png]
Step 16


Fit the gauge adapter to the pump outlet with thread sealant and the hose's coupler to the adapter. Fit a dust cap on every open coupler.

### Joint close-ups

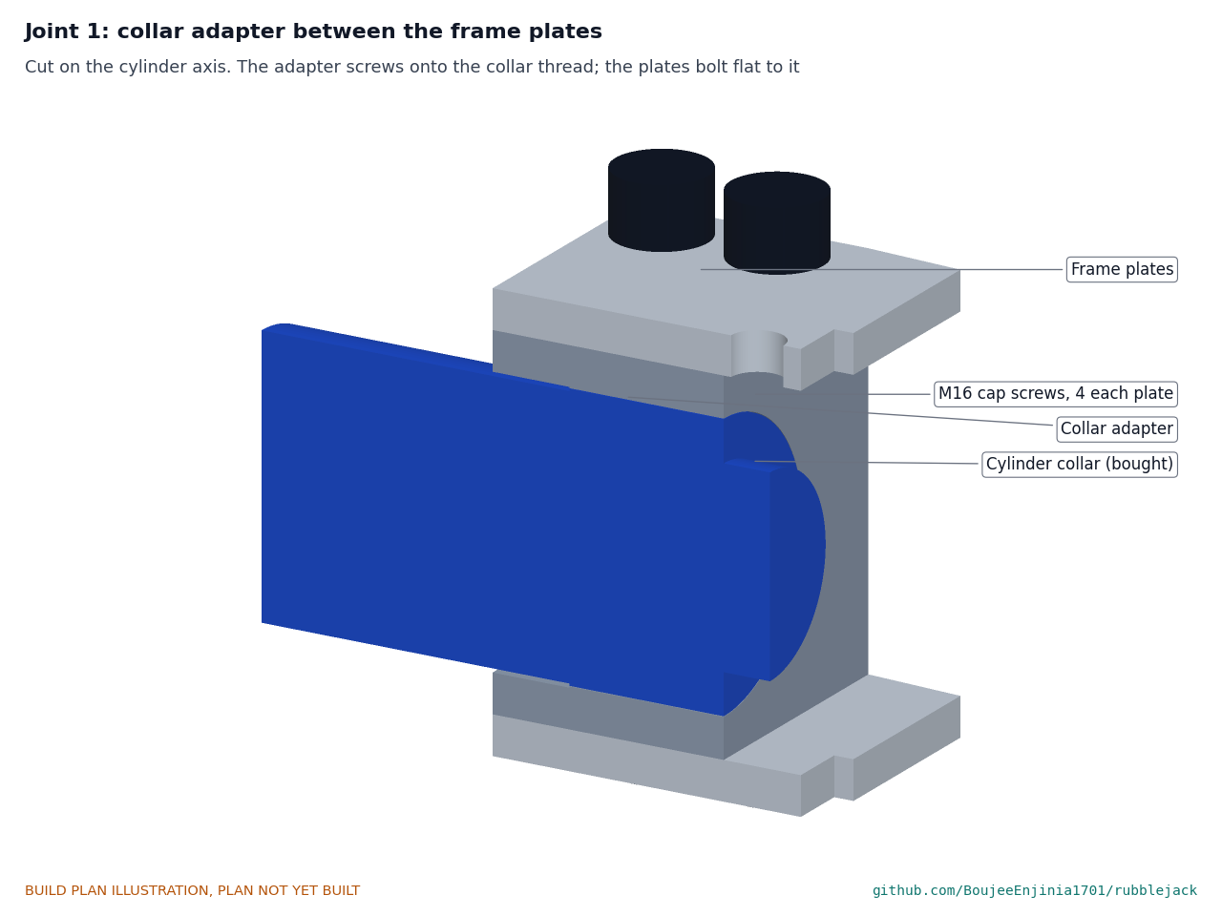
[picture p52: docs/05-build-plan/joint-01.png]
Figure 20. Joint 1: collar adapter between the frame plates


*Figure 20. Joint 1: the adapter screws onto the collar thread; the plates bolt flat to it with four M16 screws each.*

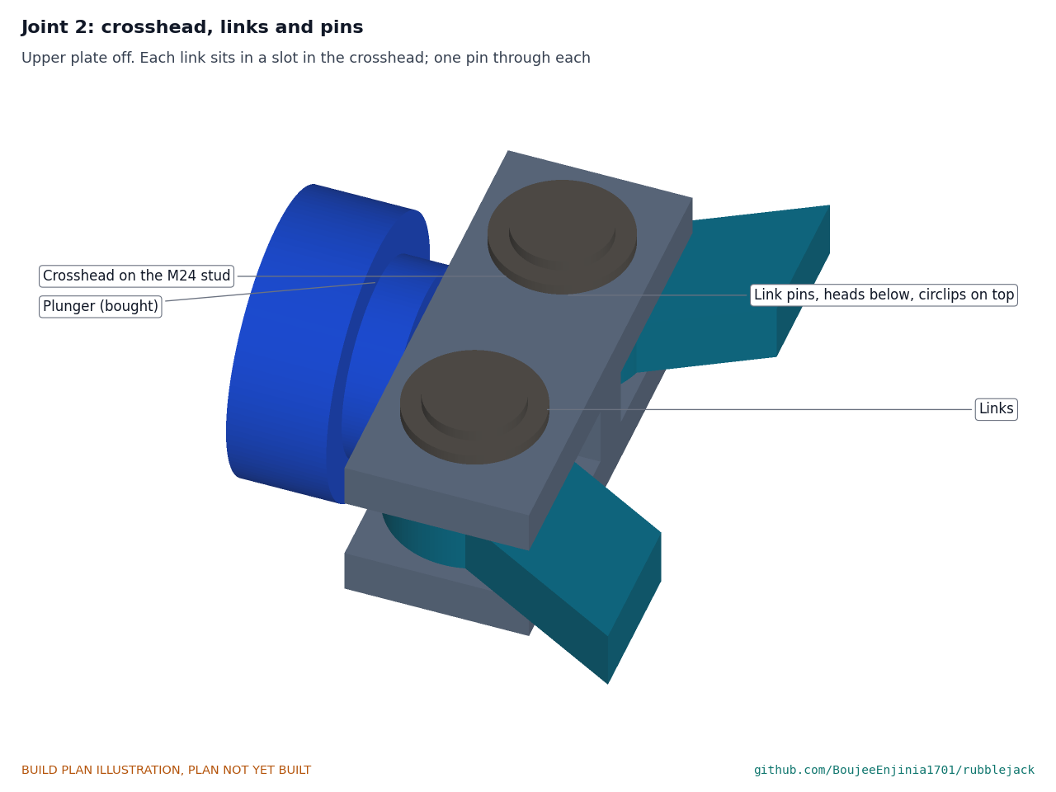
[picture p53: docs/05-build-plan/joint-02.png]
Figure 21. Joint 2: crosshead, links and pins


*Figure 21. Joint 2: each link sits in a slot in the crosshead on one pin.*

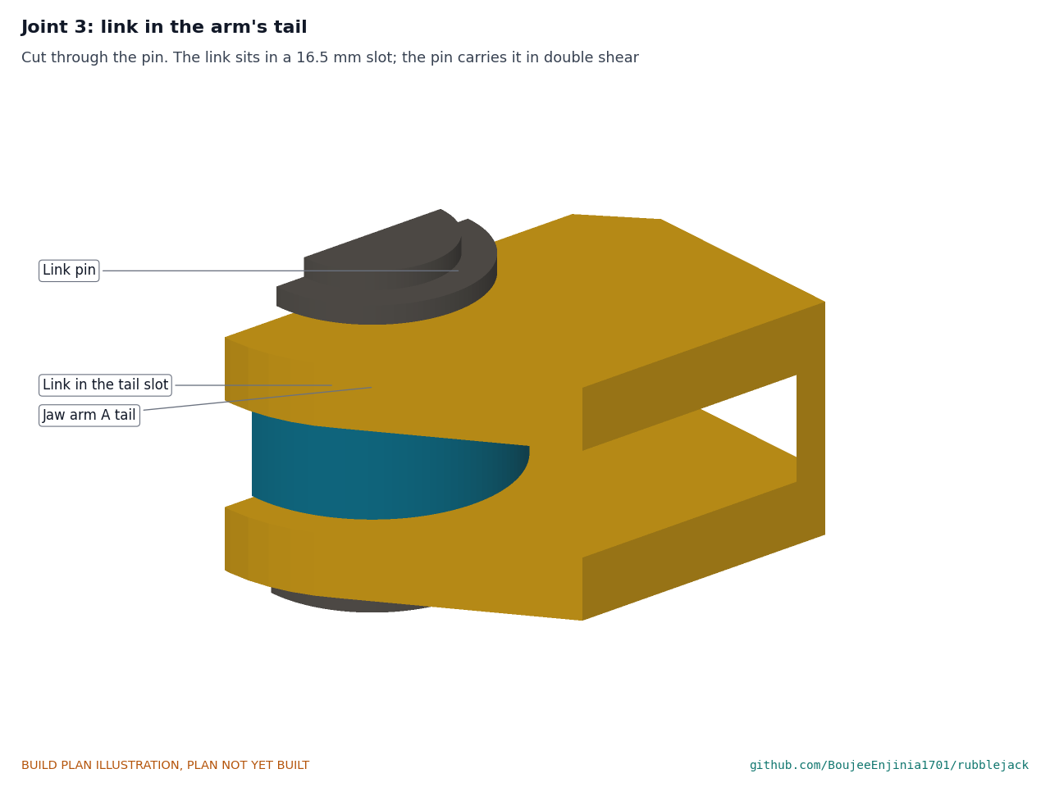
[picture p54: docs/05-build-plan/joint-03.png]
Figure 22. Joint 3: link in the arm's tail


*Figure 22. Joint 3: the link sits in the tail's 16.5 mm slot; the pin carries it in double shear.*

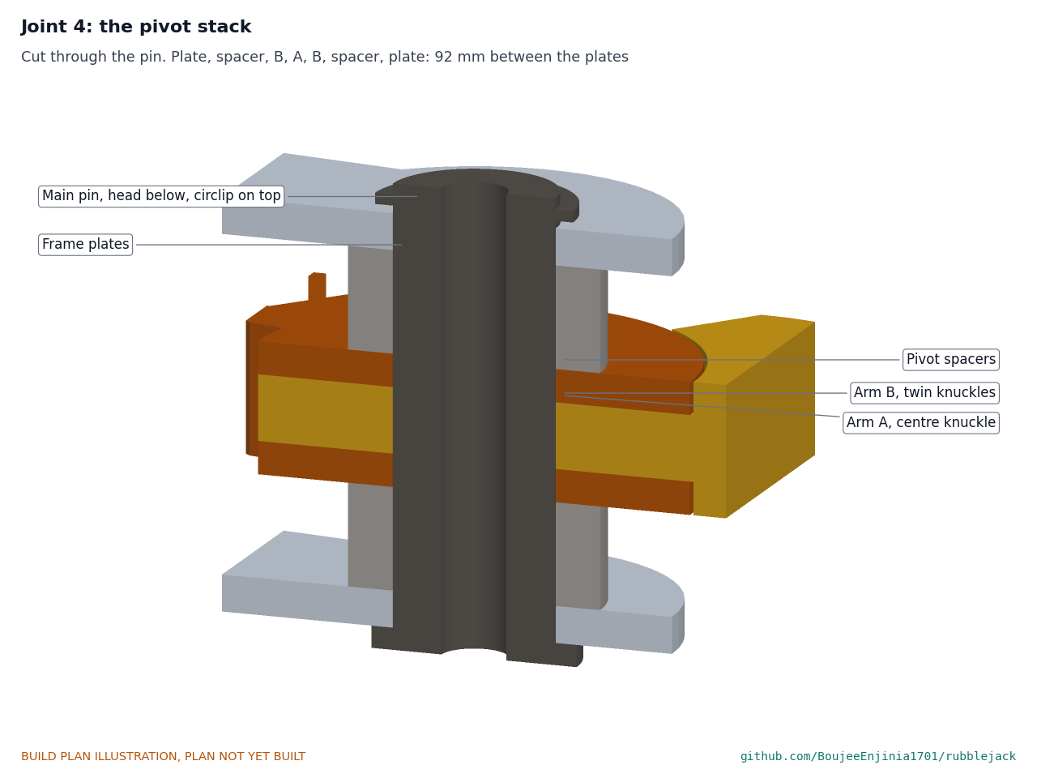
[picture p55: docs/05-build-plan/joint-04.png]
Figure 23. Joint 4: the pivot stack


*Figure 23. Joint 4: plate, spacer, arm B, arm A, arm B, spacer, plate, all on the main pin; 92 mm between the plates.*

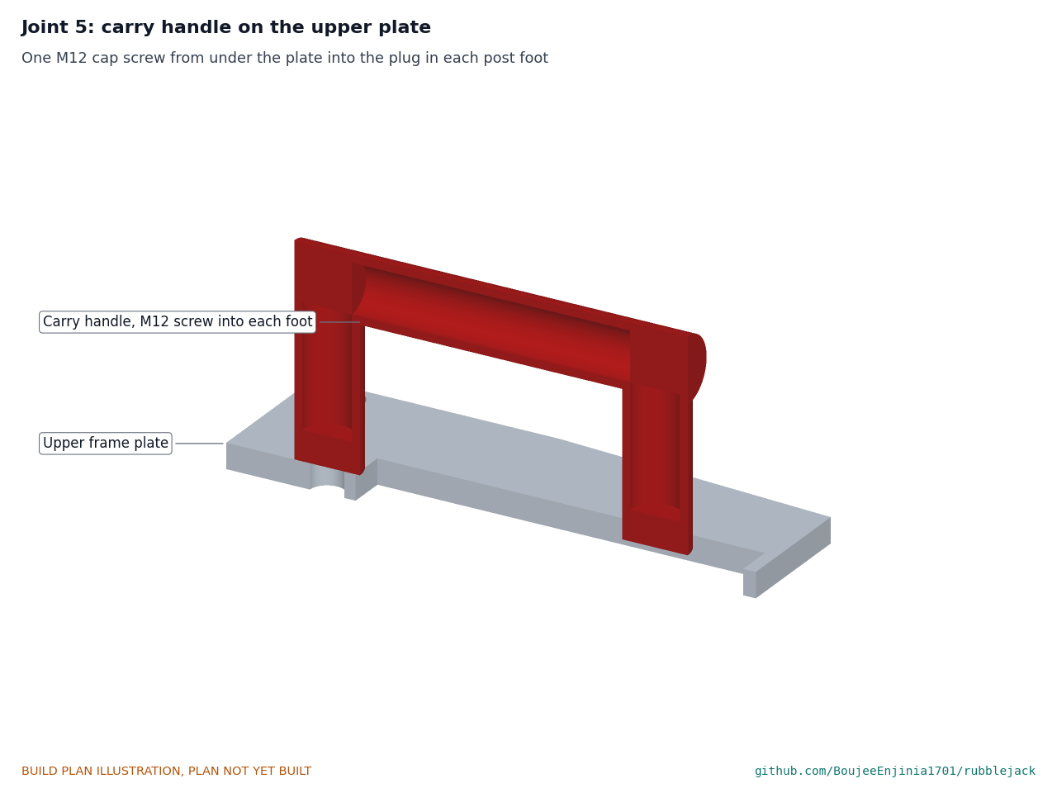
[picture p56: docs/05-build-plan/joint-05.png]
Figure 24. Joint 5: carry handle on the upper plate


*Figure 24. Joint 5: one M12 screw from under the plate into each handle foot.*

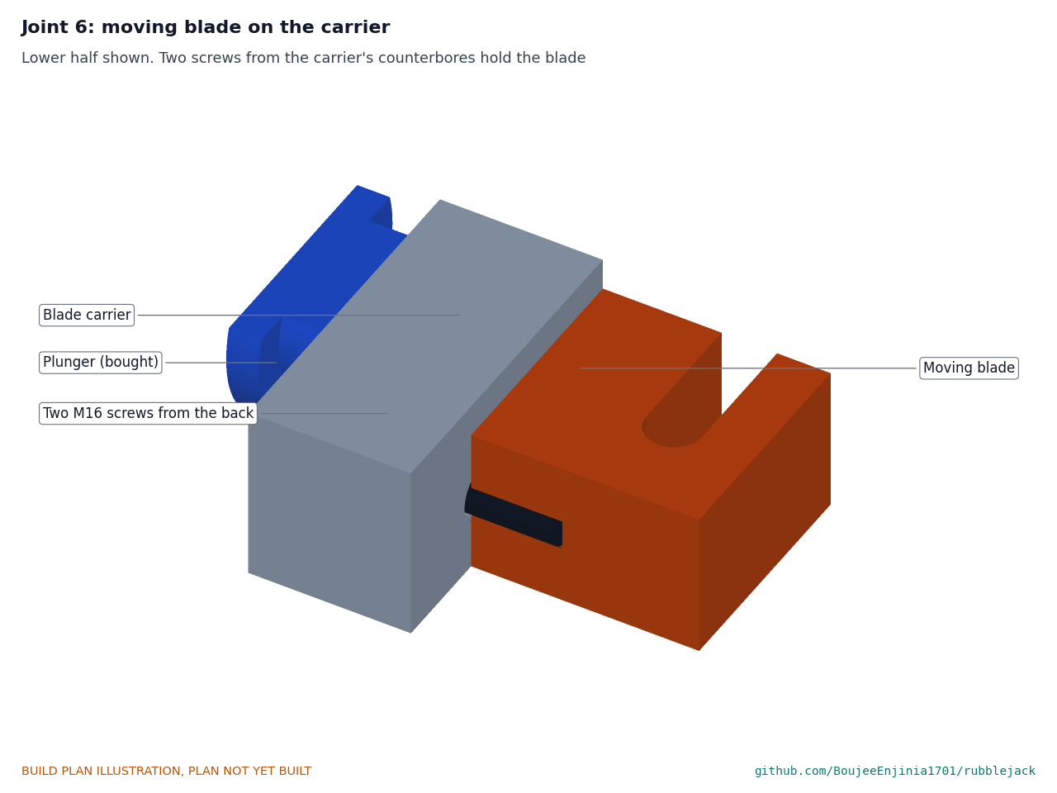
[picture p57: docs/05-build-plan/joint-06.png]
Figure 25. Joint 6: moving blade on the carrier


*Figure 25. Joint 6: two M16 screws from the carrier's counterbores hold the moving blade.*

Figure 26. Joint 7: blades, nose block and the bar

*Figure 26. Joint 7: the bar crosses both notches; the fixed blade bears on the nose block, 0.2 mm above the moving blade.*

Figure 27. Joint 8: stop bar between the plates

*Figure 27. Joint 8: the carrier lands on the stop bar after the cut; two screws in each plate hold it.*

Figure 28. Joint 9: the lifting ram stack

*Figure 28. Joint 9: riser spigot in the base ring, cylinder base in the riser's ring, saddle on the plunger.*

## 5. First checks

These are listed here and recorded in a TRL 4 test report; none is done at TRL 3.

| Check | Requirement | Pass when |
| --- | --- | --- |
| Every tool moves through its stroke by hand pressure on the pump, no load | R3, R8 | Spreader opens to at least 250 mm; cutter carrier reaches the stop; ram extends 101 mm; nothing binds |
| Couplers swap between tools | R7, R8 | Pump to working tool in 3 min from the bags; a tool change in under 1 min |
| Pressure hold, each tool against a fixed stop, at 700 bar on the gauge for 5 min | R5 | No leak, no gauge drop over 5 %, no visible deformation |
| Proof load on CalRig at 1.5 times the force at 700 bar, then crack check | R1, R2, R11 | No crack, no permanent set over 0.2 mm at the tips, pins or plates |
| Spreading force at the tips at five openings | R2 | 40 kN or more at every opening |
| Cut 16 mm B500B or A615 grade 60 bar | R4 | Clean cut below 700 bar on the gauge; blades undamaged |
| Weigh each packed bag | R6 | Each 25 kg or less |
| Ram on three hardwood sleepers with cribbing | R1, R12 | Lifts 10 t on CalRig without the plate rocking or the sleepers crushing |

## 6. Safety stops

Work stops at each point until everything listed is true.

| Stop | Before | What must be true to carry on |
| --- | --- | --- |
| S1 | Heat treatment is accepted | Arms, pins and blades have a hardness test result in range and pass a crack check; S690QL and 7075-T6 have mill certificates |
| S2 | Welded parts are used | Base plate and riser welds pass visual and dye-penetrant checks; the base plate is flat |
| S3 | First pressure on any tool | Every hose, coupler, gauge and cylinder is marked or documented at 700 bar; the gauge is fitted; couplers fully engaged; every screw torqued and every circlip seated; people out of the line of the tool and the hoses; eye and face protection on |
| S4 | First load | The tool is against a fixed stop or a load cell on CalRig, inside a guard, never on a load anyone stands near |
| S5 | Proof load | CalRig rated above 1.5 times 142 kN; operator behind a shield; pressure raised in steps of 100 bar with a pause at each |
| S6 | Any lift with the ram | Base plate on hardwood sleepers; cribbing ready to follow the load within 25 mm; nobody under the load; riser only under the cylinder |
| S7 | Any cut | Only reinforcing bar of 16 mm or less; bar ends guarded or held; everyone clear of the line of the ends |
| S8 | Any use outside the test bench | The tool has passed its proof load and crack check, and the co-design partner has trained the crew; it is still not certified rescue equipment |

> **Safety:** Never feel for a leak by hand. Release pressure at the pump's valve before uncoupling a hose, adjusting a tool or touching a load. Replace any hose that is kinked, abraded or bulging.

## 7. Tools, skills and workspace

- **Workshop:** waterjet or laser cutting service; a milling machine and lathe with boring and threading; drilling and tapping to M24; a surface plate; access to heat treatment with hardness testing; MIG or stick welding with low-hydrogen consumables and preheat; dye-penetrant crack-check kit.
- **Assembly:** torque wrench covering M12 and M16 class 12.9, circlip pliers, feeler gauges, thread-locker and thread sealant, two wooden blocks.
- **Skills:** machinist able to cut a fine collar thread and hold 0.05 mm flatness; welder qualified for high-strength steel; someone trained in high-pressure hydraulics for the first pressure checks.
- **Space:** a bench in a workshop with a clear zone around the test bench and a guard or shield for any pressurised test.

## 8. Where the numbers come from

- Model and constructability checks: `cad/src/model.py` (`cad/step/rubblejack-kit.step`, `-spreader`, `-cutter`, `-ram`)
- General arrangement: `cad/drawings/RBJ-DWG-001`; making sketches `cad/drawings/RBJ-DWG-101` to `RBJ-DWG-118`
- Pictures: `cad/src/build_plan_media.py`
- Calculations: `docs/04-calcs/01-sizing.md` (RBJ-CAL-001) and `docs/04-calcs/sizing.py`
- Parts and prices: `bom/bom.csv`
- Design changes: `docs/decisions/0002-design-for-construction.md` (RBJ-DDR-002)

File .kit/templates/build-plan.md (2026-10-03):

---
doc_id: PRJ-BLD-001
title: Project prototype build plan
project: Project name
doc_type: Build plan
version: "0.1"
status: Draft
date: YYYY-MM-DD
author: Amish Chadha
license: CERN-OHL-S-2.0
revisions:
  - version: "0.1"
    date: YYYY-MM-DD
    author: Amish Chadha
    change: First build plan; design made constructable
---

# Project prototype build plan

**Plan, not yet built.** How to build the first proof-of-concept prototype, component by component. Building and testing to it is TRL 4 work. Decisions still to be made are kept in the design decisions register (`docs/06-design-decisions.md`), not here.

## 1. What you are building

Every component, pulled apart and numbered in build order

One short paragraph: what the prototype is, how many components, which are made and which are bought, and the main ways they are made.

## 2. What changed to make it buildable

| Component | The concept had | The buildable design has | Why |
| --- | --- | --- | --- |

## 3. Making the components

### 3.1 Component name

Making sketch

**What it is and what it is made from.**

**How to make it.**

1. Mark out ...
2. Cut ...

**How it fits the parts next to it.**

Close-up of the joint

**Check before moving on.**

## 4. Putting it together

### Step 1: ...

Step 1

## 5. First checks

| Check | Requirement | How | Pass when |
| --- | --- | --- | --- |

## 6. Safety stops

## 7. Tools, skills and workspace

## 8. Where the numbers come from

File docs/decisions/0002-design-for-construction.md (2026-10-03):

---
doc_id: RBJ-DDR-002
title: RubbleJack design for construction
project: RubbleJack
doc_type: Design decision record
version: "0.1"
status: Draft
date: '2026-10-03'
author: Amish Chadha
license: CERN-OHL-S-2.0
revisions:
- version: "0.1"
  date: '2026-10-03'
  author: Amish Chadha
  change: Changes that make the kit physically buildable, with the reason for each, decided under Amish's 2026-10-03 pre-approval
---

# 0002: Design for construction

- **Date:** 2026-10-03
- **Status:** decided. Amish, 2026-10-03: "start with the first 14 repos from the list of 29 projects. I pre-approve the batch runs along with any recommendations you come up with. I also accept any cost overruns or variations from the assumed scope cost." This covers every change below.

## Context

The scaffold precis (RBJ-PRC-001 v0.1) described bolt-on spreader and cutter heads on standard cylinders, a ram with base plates and extension tubes, and a pump and hoses, but no part had been checked for how it is made or how it joins the next one. Under Amish's 2026-09-30 instruction ("fix the design assumptions to match and be physically feasible"), the model in `cad/src/model.py` was built as a constructable design: every part has a stated making process and material, every joint has a fixing, and 228 build123d checks confirm that parts which must touch do touch, parts which must not touch stay clear through the whole stroke of each tool, and every screw and pin passes through clear holes. All 228 pass.

The changes keep what the kit does: one hand pump drives a spreader, a cutter and a lifting ram, each carried in a load of 25 kg or less. None of them changes the pitch. Changes C2 and C8 to C10 touch the safety case and take the conservative option.

> **Safety:** These changes make the kit buildable on paper; they do not make it safe to use. Every tool must be proof-loaded on CalRig and inspected before use (RBJ-DDR-001, D9), and the kit is not certified rescue equipment.

## Decision

*Table 1. Changes made to the model, the BOM and the calculations.*

| # | Component | The concept had | The constructable design has | Why |
| --- | --- | --- | --- | --- |
| C1 | Spreader and cutter heads | "Bolt-on heads that fit onto standard cylinders", no interface defined | Each head is two frame plates bolted with eight M16 screws to a 7075-T6 collar adapter that screws onto the cylinder's collar thread; one cylinder per tool (RBJ-DDR-001, D2) | The collar thread is the cylinder's own fixture interface; the plates then carry the reaction back to it in plain tension |
| C2 | Spreader frame plates | 12 mm 7075-T6 in the first constructable layout | 10 mm 7075-T6 | Saves 0.4 kg on the heaviest load; the plates still have a margin of 1.82 at the pivot bore with a stress concentration of 2.5 (RBJ-CAL-001, C6) |
| C3 | Spreader pivot | One pin, arms shown overlapping | Arm A has a centre knuckle 18 mm thick and arm B twin knuckles 9 mm thick, interleaved on one 45 mm pin, with a 28 mm spacer each side filling the gap to the plates | Both arms share one pin with no overlap; the spacers stop the arms sliding along the pin |
| C4 | Pins | 4140 quenched and tempered | 4340 quenched and tempered to about 300 HB | Link pin bending margin was 1.35; now 1.76 (C5 in RBJ-CAL-001) |
| C5 | Jaw arm tail | Link slot from 95 mm | Link slot from 100 mm | Raises the tail's margin at the slot from 1.50 to 1.60; the links still clear the slot ends through the whole stroke (checked at nine positions) |
| C6 | Cutter stop bar | 30 mm long, one screw in each plate | 60 mm long, two M16 screws in each plate | With one screw a side each screw had a margin of 1.29 when the carrier lands at full pressure, and the bar could turn; with two a side the margin is 2.59 and it cannot turn |
| C7 | Fixed blade screws | Four M16 at 20 mm spacing | Four M12 at the same positions, 13.5 mm holes in the upper plate | The four M16 heads touched each other; the fixed blade's thrust goes into the nose block in bearing, so the screws only locate it |
| C8 | Ram base plate | 12 mm S355 | 20 mm S690QL with a welded S355 ring | A free plate on an even reaction bends to 931 MPa at 12 mm S355 (margin 0.37); 20 mm S690QL gives 335 MPa (margin 2.06). Conservative choice; relax only with a strain-gauged proof load on cribbing |
| C9 | Riser block | 114.3 x 8 tube between 160 mm plates | 88.9 x 10 tube between the same plates | The tube wall now stands right over the base ring and under the cylinder base, so the end plates carry the load in bearing instead of bending |
| C10 | Ram stack | Base plates and extension tubes, no location | A 15 mm locating ring on the base plate and on the riser's top plate, and a 70 mm spigot under the riser; the riser goes only under the cylinder | Every stacked part is held against sliding sideways; nothing stands on the plunger but the tilting saddle |
| C11 | Crosshead and blade carrier | Not defined | 7075-T6 blocks on an M24 stud into the plunger's attachment thread; the carrier slides between the cutter plates with 0.5 mm each side | The plunger turns freely in its cylinder, so the links and the plates set the angle; the carrier cannot twist |
| C12 | Shear | Not defined | Moving blade (lower half) on the carrier, fixed blade (upper half) held to the upper plate and bearing on a nose block, 0.2 mm apart, both with a 17 mm U notch in line with a 30 mm hook in the plates | Single shear with the bar held in the hook; the carrier lands on the stop bar 30 mm later, after the cut |
| C13 | Jaw arms | Solid plate | 8 mm deep lightening pockets each face, 12 mm in from every edge | Saves 0.84 kg on the spreader (0.42 kg an arm); the bending margins stay at 1.84 or more |
| C14 | Carry handles | Not defined | A 26.9 x 3.2 tube bent to a D, with welded M12 plugs, two M12 screws from under the upper plate | No weld on the aluminium or high-strength plates |

## Consequences

- Masses: spreader 24.0 kg, cutter 21.2 kg, ram set 22.9 kg, pump with gauge and hoses 15.1 kg; with a 0.8 kg bag each, every load is under 25 kg (R6). The spreader has 0.2 kg in hand.
- Cost: lines 12, 14, 15 and 21 changed and line 24 (M12 screws) was added; the estimate is USD 5,895 against the USD 3,500 value-engineering target.
- Drawings and media: STEP and STL regenerated, general arrangement RBJ-DWG-001 Rev P1 and making sketches RBJ-DWG-101 to 118 drawn from the constructable model, concept media refreshed.
- To confirm when parts are bought (RBJ-DEC-001): the collar thread and the load allowed through it, the plunger's attachment thread and that the plunger turns freely, the collapsed length, and the hose burst ratio.

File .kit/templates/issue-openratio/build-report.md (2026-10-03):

---
name: Build report
about: Tell us what happened when you built, printed or tested part of this design
title: "Build report: "
labels: build-report
---

This is a research and educational prototype, not a medical device. It is a TRL 3 concept and is not released for fabrication. If you build any part of it, you do so at your own risk. Reports help everyone.

**What you built** (part, sub-assembly or test)

**Materials, tools and settings**

**What worked**

**What did not work, with photos or measurements if you have them**

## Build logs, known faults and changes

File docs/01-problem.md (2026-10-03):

---
doc_id: RBJ-PRB-001
title: RubbleJack problem statement
project: RubbleJack
doc_type: Problem statement
version: "0.2"
status: Draft
date: '2026-10-03'
author: Amish Chadha
license: CERN-OHL-S-2.0
revisions:
- version: "0.1"
  date: '2026-09-30'
  author: Amish Chadha
  change: Initial scaffold
- version: "0.2"
  date: '2026-10-03'
  author: Amish Chadha
  change: TRL 2 update; budget stated as a value-engineering target, co-design candidate recorded, open questions answered by RBJ-DDR-001 and RBJ-CAL-001, safety note added
---

# RubbleJack problem statement

Neighbours and local crews reach trapped people first, often within minutes, but without tools they can only dig by hand. Powered rescue tools exist, and most crews in the places that need them cannot afford them.

> **Safety:** This problem involves lifting and spreading heavy loads with high-pressure hydraulics inside unstable structures. Any answer to it is safety-critical; RubbleJack is published as an open engineering reference, not as certified rescue equipment.

## The problem

Most live rescues after earthquakes are made locally, often by relatives and neighbours ([Rom and Kelman, 2020](https://pmc.ncbi.nlm.nih.gov/articles/PMC7745699/)), and reporting from Turkey in 2023 and Myanmar in 2025 describes people digging by hand and waiting for machines ([Euronews, 2023](https://www.euronews.com/2023/02/07/we-could-hear-their-voices-digging-with-bare-hands-for-earthquake-survivors); [Al Jazeera, 2025](https://www.aljazeera.com/news/2025/3/29/lack-of-equipment-stalls-race-to-save-earthquake-survivors-in-myanmar)). Even in wealthy countries, small volunteer departments depend on grants to buy powered tools ([Texas A&M Forest Service, 2017](https://tfsweb.tamu.edu/?p=12405)).

Certified rescue tools are compliant with standards such as EN 13204 and NFPA 1960 ([Holmatro](https://www.holmatro.com/en/rescue/spreader-psp40)) and priced accordingly. At the other end, 10-tonne hydraulic body repair kits with a hand pump, hose and ram are sold as commodity tools ([Porto-Power](https://www.amazon.com/Porto-Power-B65115-Black-Hydraulic-Repair/dp/B000XMI1RO)). The gap is an open, documented kit that turns commodity hydraulics into spreading, lifting and cutting tools, with published proof-load data and clear limits.

## Users and context

| User | Need | Context |
| --- | --- | --- |
| Volunteer and rural fire crews | Spread, lift and cut at a fraction of the cost of branded tools | Vehicle incidents and structure collapses far from larger stations |
| Community emergency response teams | A kit they can carry to a collapse and use after basic training | First hours after an earthquake, before specialist teams arrive |
| Disaster NGOs and civil protection agencies | Kits they can preposition and maintain with local parts | Earthquake-prone cities and districts |
| Local hydraulic workshops | Drawings and specifications to build and repair jaws and fittings | Towns with truck, construction and body repair trades |

## Operating environment

- Collapsed masonry and reinforced concrete buildings, with dust, unstable debris and aftershocks.
- Night work, rain, heat or freezing cold; no power on site.
- Kit carried by hand over rubble, often by two to four people.
- Loads from lightweight masonry to heavy concrete slabs; reinforcing bar and timber to cut.
- Work in confined voids with little room to swing a pump handle.

## Constraints

- Value-engineering target of USD 3,500 for pump, hoses, ram, spreader and cutter: a hypothetical control target that keeps the design thinking along a value-engineering lens, not a spending limit.
- Hand pump only; no engine or battery power unit in the first version.
- Commodity hydraulic parts (standard hand pump, hoses, couplers and cylinders) wherever possible.
- Carried in loads of 25 kg (55 lb) or less each (target).
- Open design: hardware under CERN-OHL-S-2.0.
- Not certified to NFPA or EN rescue tool standards; published as an engineering reference.

## Out of scope

- Search and detection (see VoidScope for void search).
- Shoring systems and cribbing design beyond guidance on their use.
- Heavy machinery such as excavators and cranes.
- Powered or battery hydraulic units.
- Vehicle extrication certification.

## Prior work

| Prior work | What it does | Gap for these users | Source |
| --- | --- | --- | --- |
| Porto-Power 10-tonne hydraulic body repair kit | Commodity hand pump, hose, ram and attachments for body repair | No purpose-built rescue spreader or cutter jaws, and no rescue proof-load data | [link](https://www.amazon.com/Porto-Power-B65115-Black-Hydraulic-Repair/dp/B000XMI1RO) |
| Holmatro PSP40 spreader | Battery rescue spreader, 280 kN maximum spreading force, 19.5 kg, EN 13204 and NFPA 1960 compliant | Certified and costly; out of reach for many volunteer crews | [link](https://www.holmatro.com/en/rescue/spreader-psp40) |
| Holmatro HCT-3120 hand pump spreader and cutter | Hand-pumped combination tool, about 11,690 lbf spreading force, 23 lb | Proprietary and costly even second-hand | [link](https://www.fentonfire.com/equipment/holmatro-hct-3120-hand-pump-spreader-cutter-a1758/) |
| US7937838B2 hydraulic rescue tool with quick-change head | Rescue tool with detachable head on a hydraulic cylinder | Patent lapsed in 2019 for unpaid fees; free prior art for interchangeable heads | [link](https://patents.google.com/patent/US7937838?oq=hurst+jaws+of+life) |

## Co-design

A volunteer fire service or community emergency response programme in an earthquake-prone region, working with a local hydraulic workshop, so jaws and fittings are shaped by real training scenarios and can be made and serviced locally. The first candidate to approach is a volunteer search and rescue association in southern Turkey (AKUT is the first candidate), in the region hit in February 2023, with a local hydraulic workshop; this is a first candidate, not an agreement (RBJ-DDR-001, D12).

- [ ] Partner approached and willing to review the kit
- [ ] Training scenarios and typical loads confirmed with the partner
- [ ] Local workshop able to make the jaws, blades and plates identified

## Open questions

The scaffold's questions are answered on paper; none remain open.

- Can bolt-on jaws on standard cylinders reach useful forces? Yes on paper: a 15 t cylinder gives 49 to 64 kN at the spreader tips and shears 16 mm bar with a ratio of 1.36 (RBJ-CAL-001).
- Proof load and inspection: every made tool is proof-loaded on CalRig at 1.5 times the force at 700 bar and crack-checked before use; the routine between uses is set with the co-design partner at TRL 4 (RBJ-DDR-001, D9).
- Cribbing and shoring: cribbing is required and guidance is given, but cribbing is not designed or supplied (RBJ-DDR-001, D11).
- First drills: the first candidate host is recorded under Co-design.

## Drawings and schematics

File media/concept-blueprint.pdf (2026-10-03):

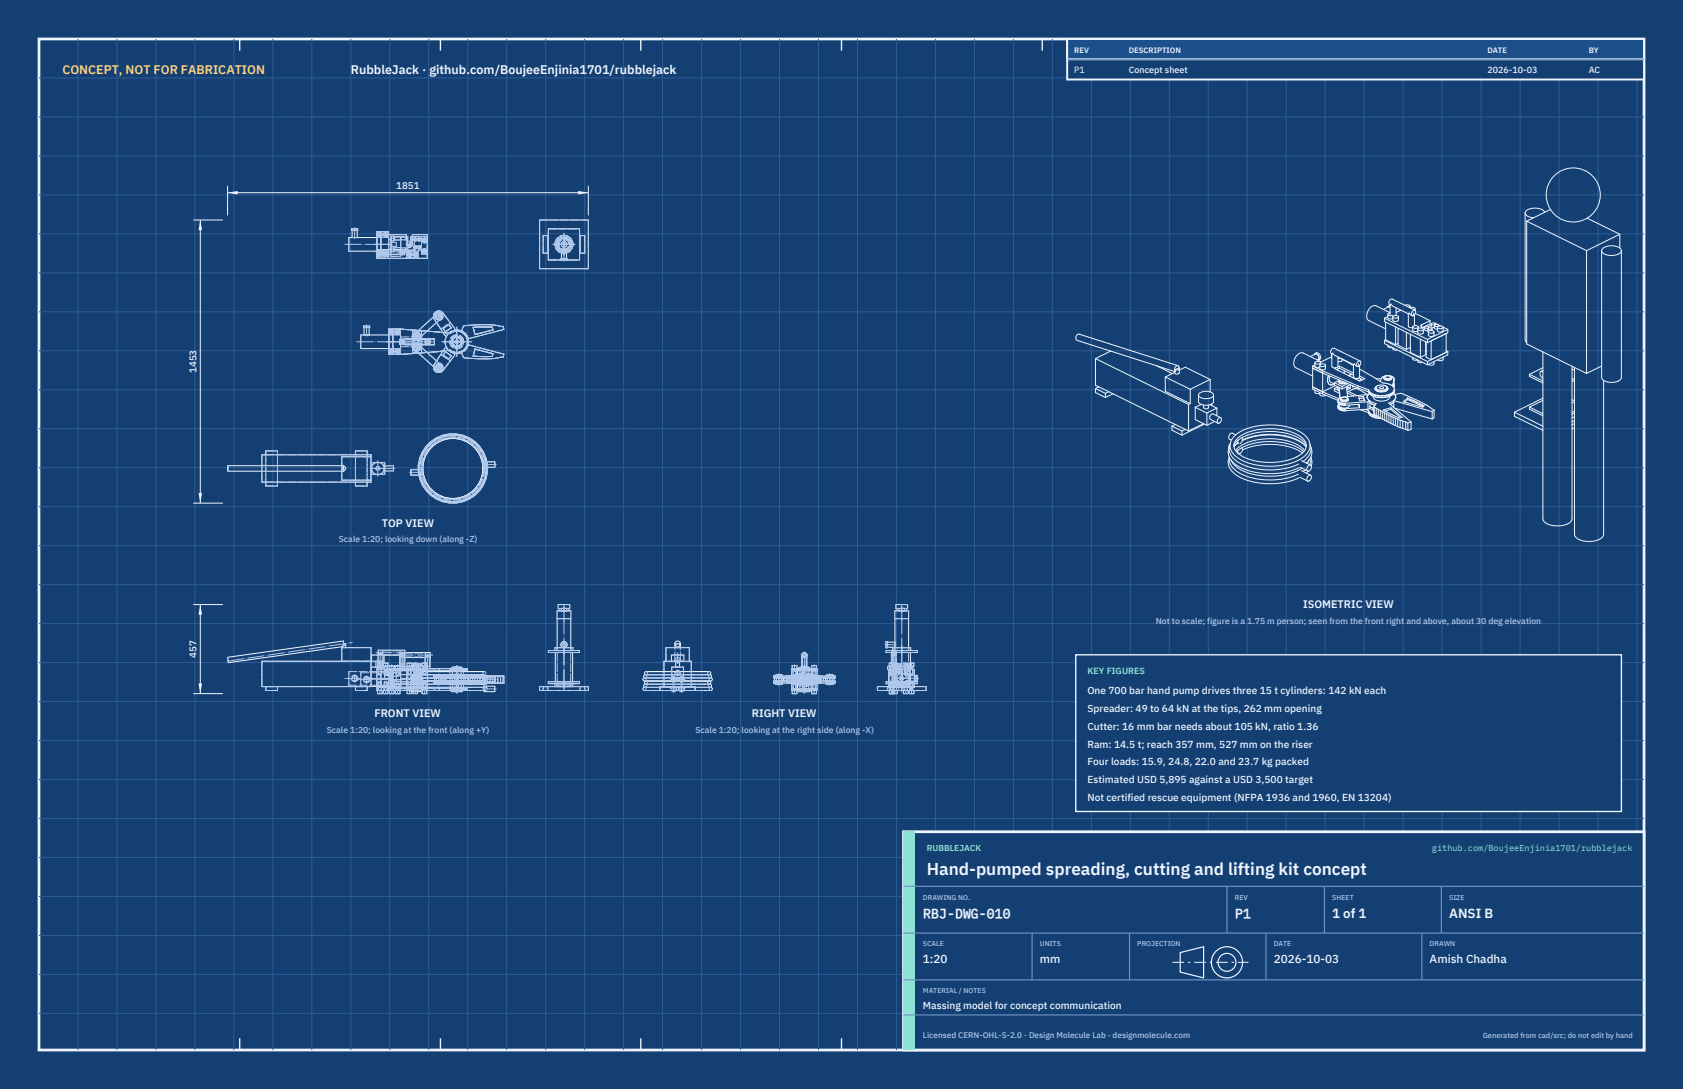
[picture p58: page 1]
CONCEPT, NOT FOR FABRICATION; RubbleJack · github.com/BoujeeEnjinia1701/rubblejack; FRONT VIEW; TOP VIEW; RIGHT VIEW; ISOMETRIC VIEW; REV; DESCRIPTION; DATE; Concept sheet; RUBBLEJACK; github.com/BoujeeEnjinia1701/rubblejack; DRAWING NO. RBJ-DWG-010; REV P1; SHEET 1 of 1; SIZE ANSI B; SCALE 1:20; UNITS mm; PROJECTION; DRAWN Amish Chadha; Licensed CERN-OHL-S-2.0 · Design Molecule Lab · designmolecule.com; Generated from cad/src; do not edit by hand

Scale 1:20; looking down (along -Z)

Not to scale; figure is a 1.75 m person; seen from the front right and above, about 30 deg elevation

KEY FIGURES
One 700 bar hand pump drives three 15 t cylinders: 142 kN each
Spreader: 49 to 64 kN at the tips, 262 mm opening
Cutter: 16 mm bar needs about 105 kN, ratio 1.36
Ram: 14.5 t; reach 357 mm, 527 mm on the riser
Four loads: 15.9, 24.8, 22.0 and 23.7 kg packed
Estimated USD 5,895 against a USD 3,500 target
Not certified rescue equipment (NFPA 1936 and 1960, EN 13204)

Scale 1:20; looking at the front (along +Y)

Scale 1:20; looking at the right side (along -X)

Hand-pumped spreading, cutting and lifting kit concept

MATERIAL / NOTES
Massing model for concept communication

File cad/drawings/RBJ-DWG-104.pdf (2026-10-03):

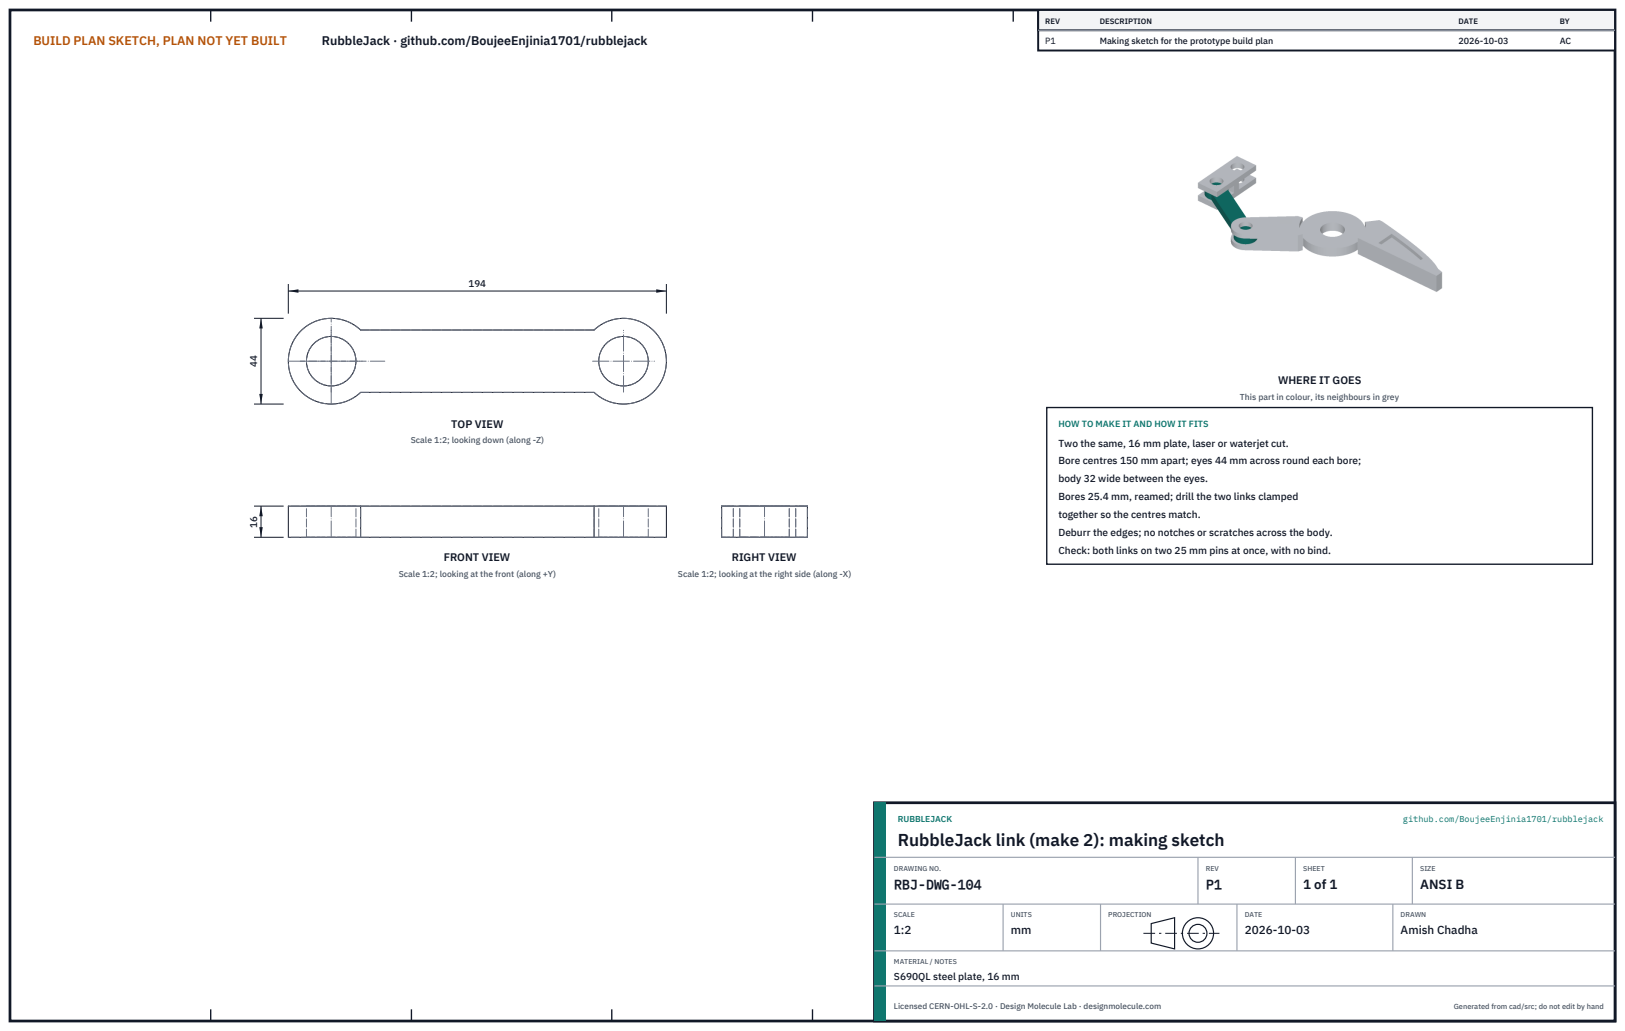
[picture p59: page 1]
BUILD PLAN SKETCH, PLAN NOT YET BUILT; RubbleJack · github.com/BoujeeEnjinia1701/rubblejack; FRONT VIEW; TOP VIEW; RIGHT VIEW; REV; DESCRIPTION; DATE; Making sketch for the prototype build plan; RUBBLEJACK; github.com/BoujeeEnjinia1701/rubblejack; DRAWING NO. RBJ-DWG-104; REV P1; SHEET 1 of 1; SIZE ANSI B; SCALE 1:2; UNITS mm; PROJECTION; DRAWN Amish Chadha; Licensed CERN-OHL-S-2.0 · Design Molecule Lab · designmolecule.com; Generated from cad/src; do not edit by hand

WHERE IT GOES

This part in colour, its neighbours in grey

HOW TO MAKE IT AND HOW IT FITS
Two the same, 16 mm plate, laser or waterjet cut.
Bore centres 150 mm apart; eyes 44 mm across round each bore;
body 32 wide between the eyes.
Bores 25.4 mm, reamed; drill the two links clamped
together so the centres match.
Deburr the edges; no notches or scratches across the body.
Check: both links on two 25 mm pins at once, with no bind.

Scale 1:2; looking down (along -Z)

Scale 1:2; looking at the front (along +Y)

Scale 1:2; looking at the right side (along -X)

RubbleJack link (make 2): making sketch

MATERIAL / NOTES
S690QL steel plate, 16 mm

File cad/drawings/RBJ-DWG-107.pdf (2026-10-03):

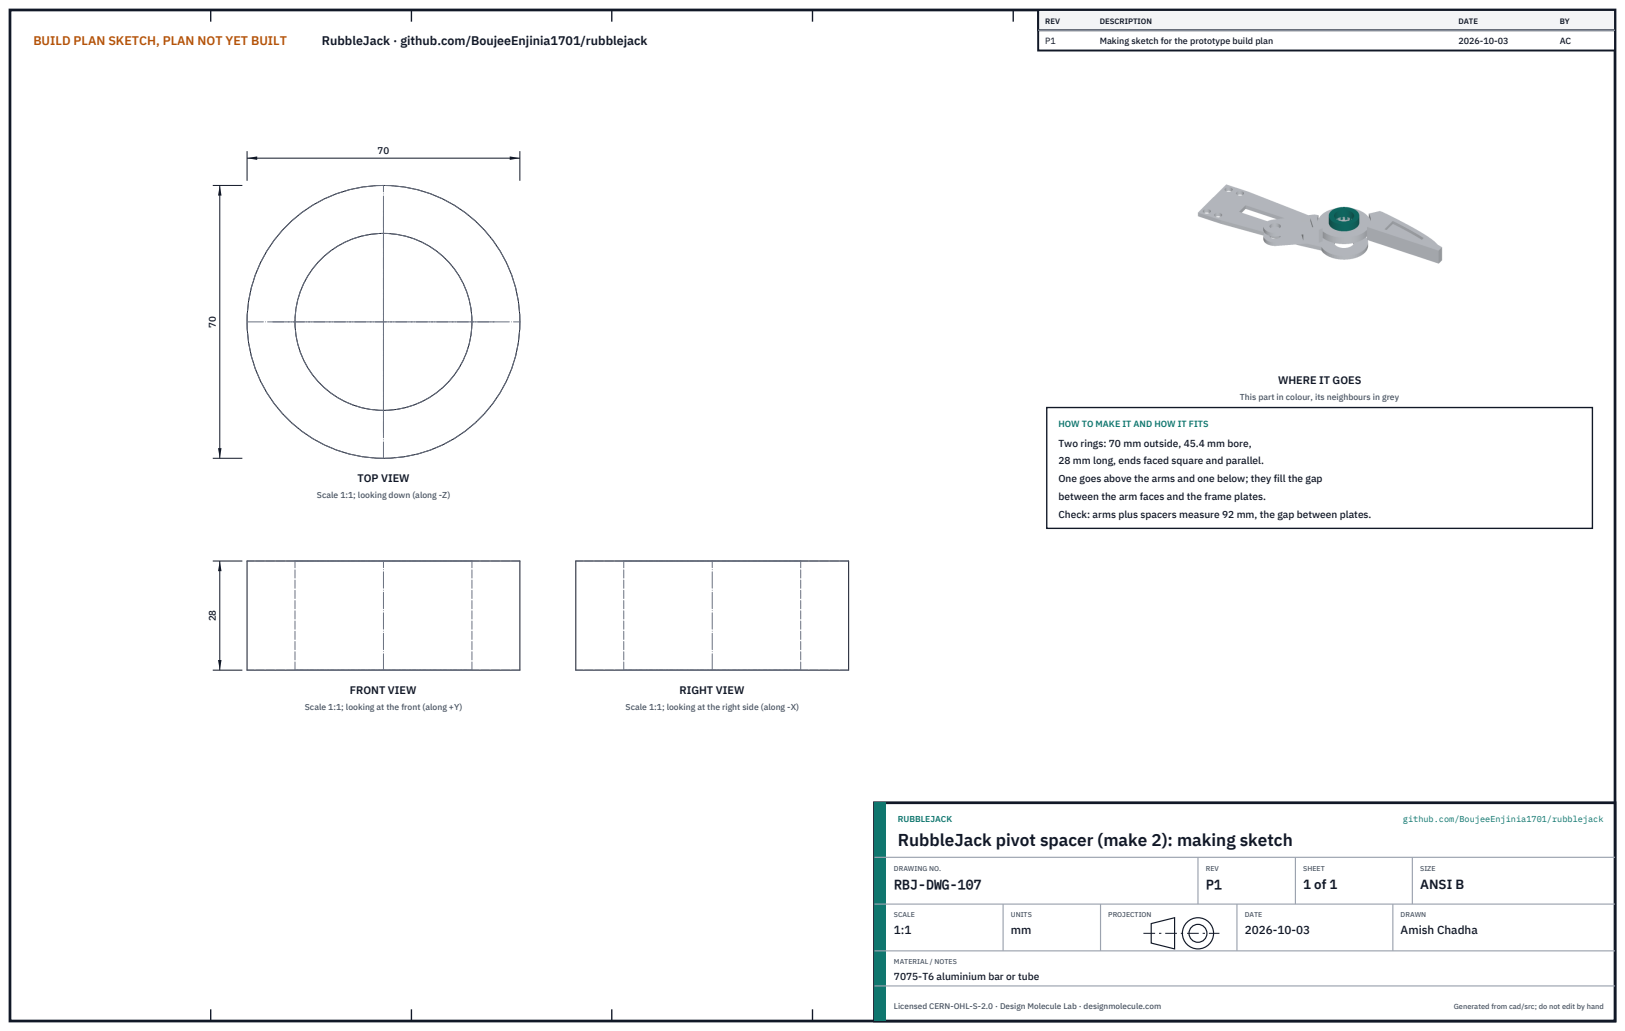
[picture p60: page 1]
BUILD PLAN SKETCH, PLAN NOT YET BUILT; RubbleJack · github.com/BoujeeEnjinia1701/rubblejack; FRONT VIEW; TOP VIEW; RIGHT VIEW; REV; DESCRIPTION; DATE; Making sketch for the prototype build plan; RUBBLEJACK; github.com/BoujeeEnjinia1701/rubblejack; DRAWING NO. RBJ-DWG-107; REV P1; SHEET 1 of 1; SIZE ANSI B; SCALE 1:1; UNITS mm; PROJECTION; DRAWN Amish Chadha; Licensed CERN-OHL-S-2.0 · Design Molecule Lab · designmolecule.com; Generated from cad/src; do not edit by hand

WHERE IT GOES

This part in colour, its neighbours in grey

HOW TO MAKE IT AND HOW IT FITS
Two rings: 70 mm outside, 45.4 mm bore,
28 mm long, ends faced square and parallel.
One goes above the arms and one below; they fill the gap
between the arm faces and the frame plates.
Check: arms plus spacers measure 92 mm, the gap between plates.

Scale 1:1; looking down (along -Z)

Scale 1:1; looking at the front (along +Y)

Scale 1:1; looking at the right side (along -X)

RubbleJack pivot spacer (make 2): making sketch

MATERIAL / NOTES
7075-T6 aluminium bar or tube

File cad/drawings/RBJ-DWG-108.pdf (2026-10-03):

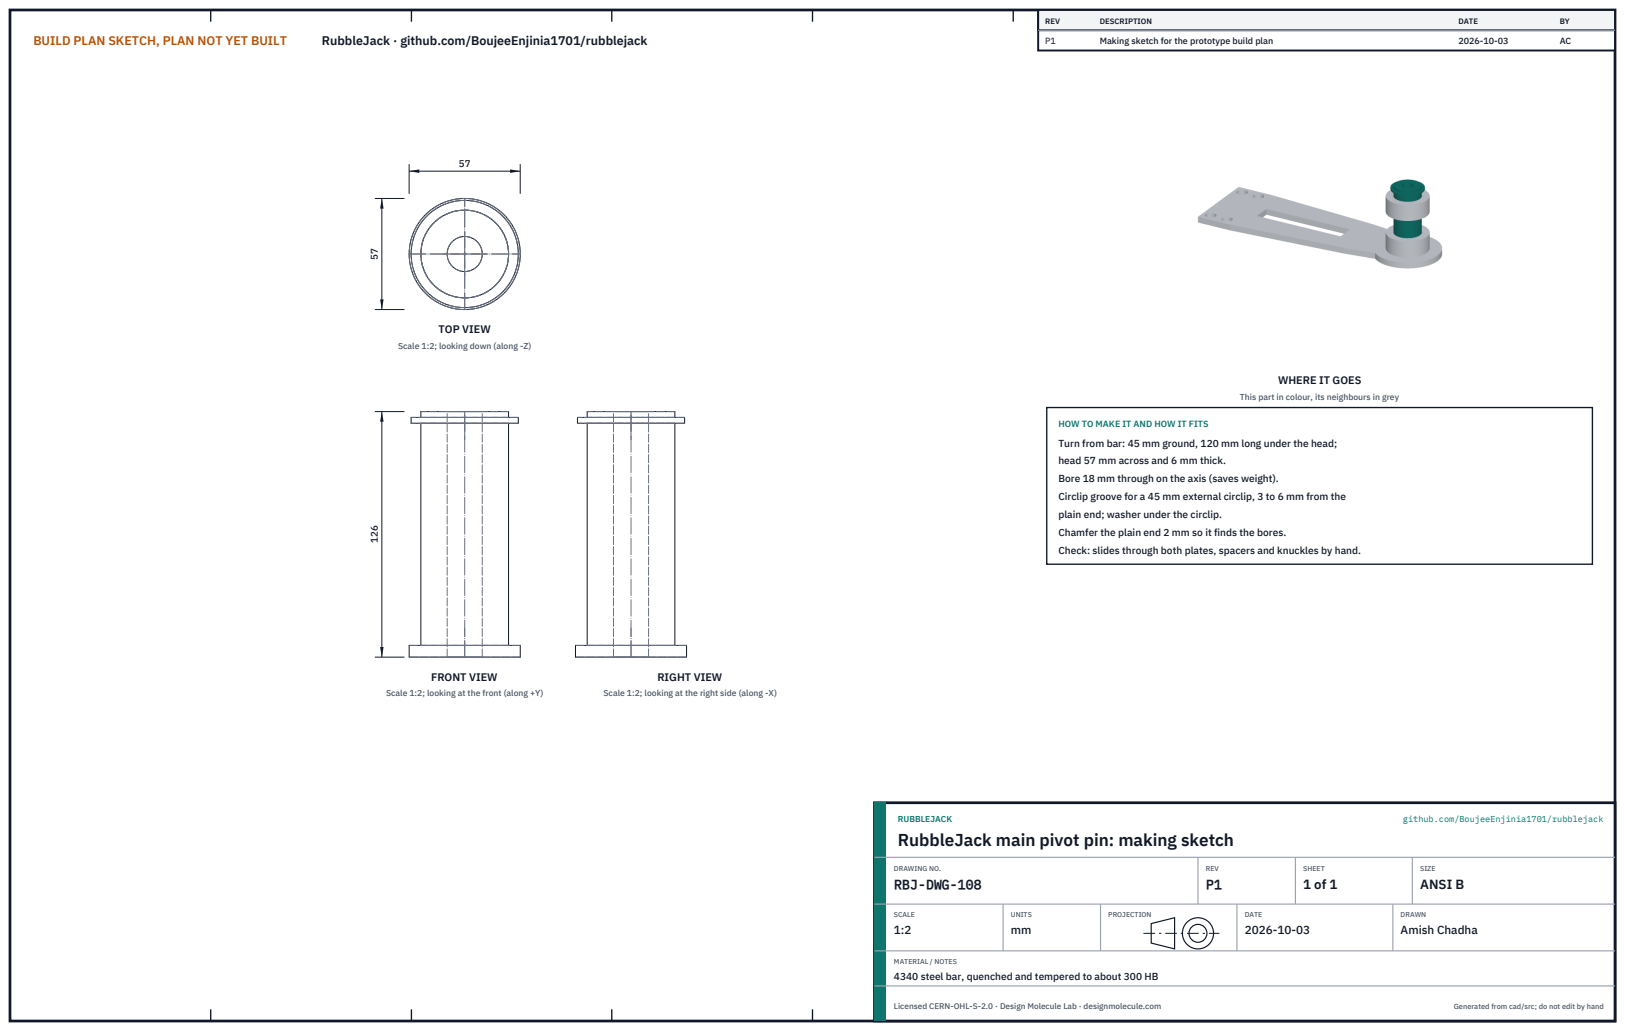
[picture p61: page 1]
BUILD PLAN SKETCH, PLAN NOT YET BUILT; RubbleJack · github.com/BoujeeEnjinia1701/rubblejack; FRONT VIEW; TOP VIEW; RIGHT VIEW; REV; DESCRIPTION; DATE; Making sketch for the prototype build plan; RUBBLEJACK; github.com/BoujeeEnjinia1701/rubblejack; DRAWING NO. RBJ-DWG-108; REV P1; SHEET 1 of 1; SIZE ANSI B; SCALE 1:2; UNITS mm; PROJECTION; DRAWN Amish Chadha; Licensed CERN-OHL-S-2.0 · Design Molecule Lab · designmolecule.com; Generated from cad/src; do not edit by hand

Scale 1:2; looking down (along -Z)

WHERE IT GOES

This part in colour, its neighbours in grey

HOW TO MAKE IT AND HOW IT FITS
Turn from bar: 45 mm ground, 120 mm long under the head;
head 57 mm across and 6 mm thick.
Bore 18 mm through on the axis (saves weight).
Circlip groove for a 45 mm external circlip, 3 to 6 mm from the
plain end; washer under the circlip.
Chamfer the plain end 2 mm so it finds the bores.
Check: slides through both plates, spacers and knuckles by hand.

Scale 1:2; looking at the front (along +Y)

Scale 1:2; looking at the right side (along -X)

RubbleJack main pivot pin: making sketch

MATERIAL / NOTES
4340 steel bar, quenched and tempered to about 300 HB

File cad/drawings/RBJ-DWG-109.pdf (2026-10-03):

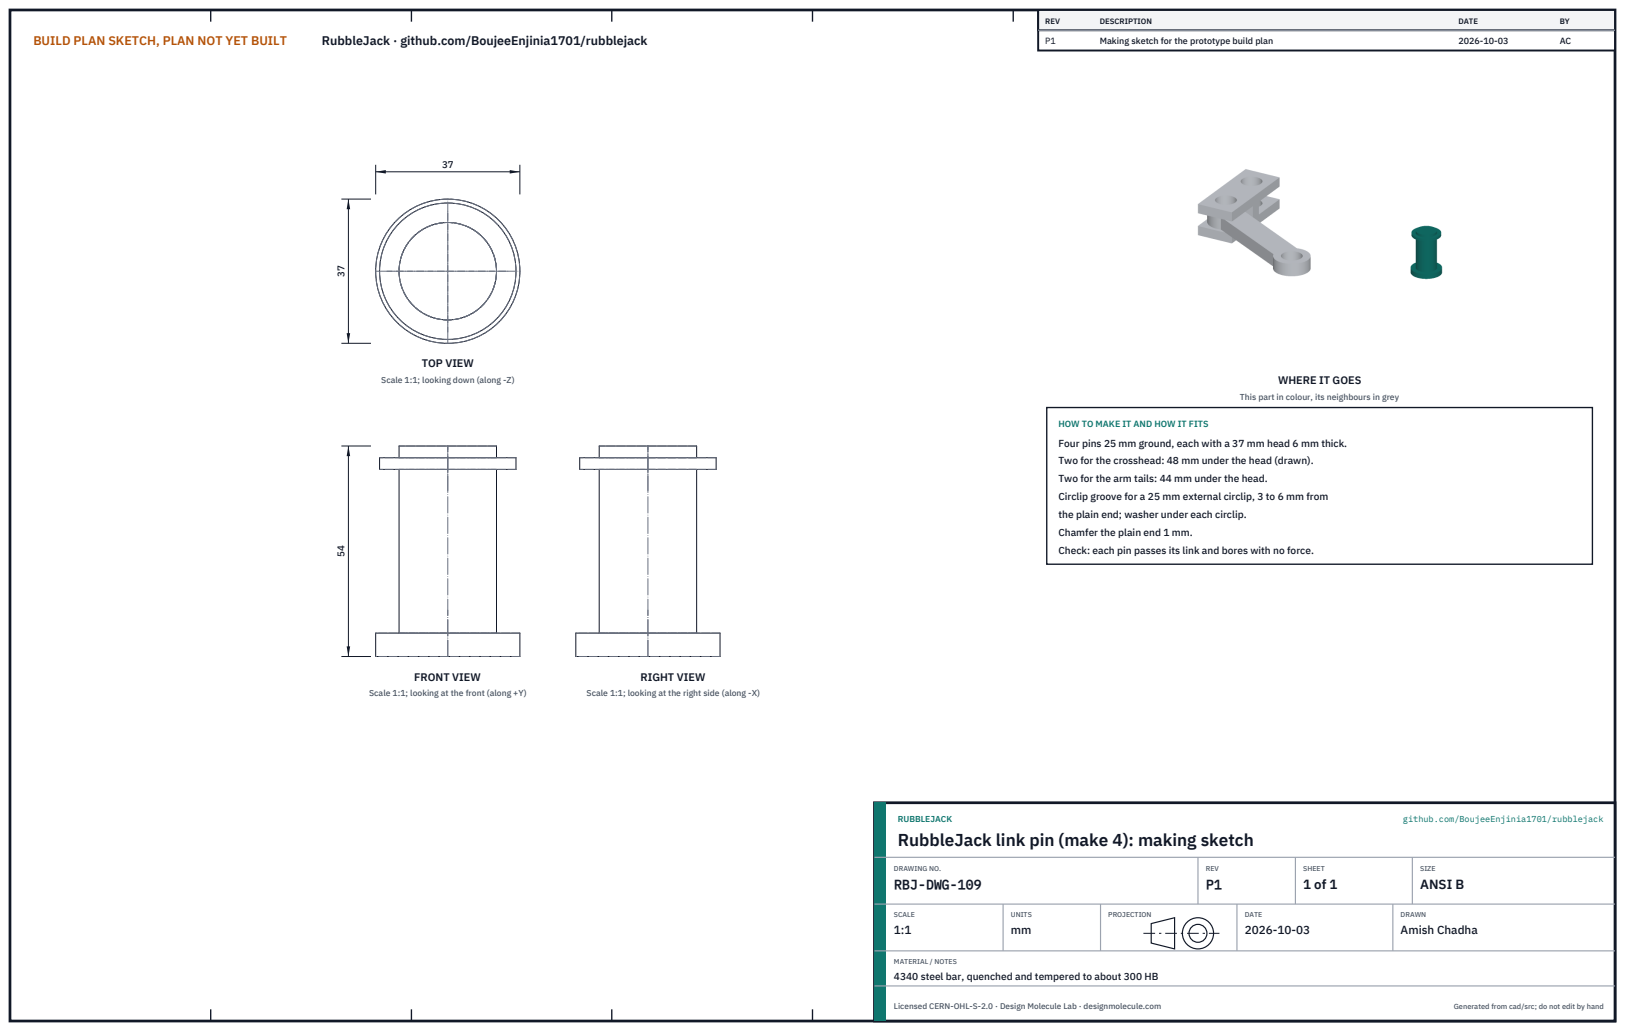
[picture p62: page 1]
BUILD PLAN SKETCH, PLAN NOT YET BUILT; RubbleJack · github.com/BoujeeEnjinia1701/rubblejack; FRONT VIEW; TOP VIEW; RIGHT VIEW; REV; DESCRIPTION; DATE; Making sketch for the prototype build plan; RUBBLEJACK; github.com/BoujeeEnjinia1701/rubblejack; DRAWING NO. RBJ-DWG-109; REV P1; SHEET 1 of 1; SIZE ANSI B; SCALE 1:1; UNITS mm; PROJECTION; DRAWN Amish Chadha; Licensed CERN-OHL-S-2.0 · Design Molecule Lab · designmolecule.com; Generated from cad/src; do not edit by hand

Scale 1:1; looking down (along -Z)

WHERE IT GOES

This part in colour, its neighbours in grey

HOW TO MAKE IT AND HOW IT FITS
Four pins 25 mm ground, each with a 37 mm head 6 mm thick.
Two for the crosshead: 48 mm under the head (drawn).
Two for the arm tails: 44 mm under the head.
Circlip groove for a 25 mm external circlip, 3 to 6 mm from
the plain end; washer under each circlip.
Chamfer the plain end 1 mm.
Check: each pin passes its link and bores with no force.

Scale 1:1; looking at the front (along +Y)

Scale 1:1; looking at the right side (along -X)

RubbleJack link pin (make 4): making sketch

MATERIAL / NOTES
4340 steel bar, quenched and tempered to about 300 HB

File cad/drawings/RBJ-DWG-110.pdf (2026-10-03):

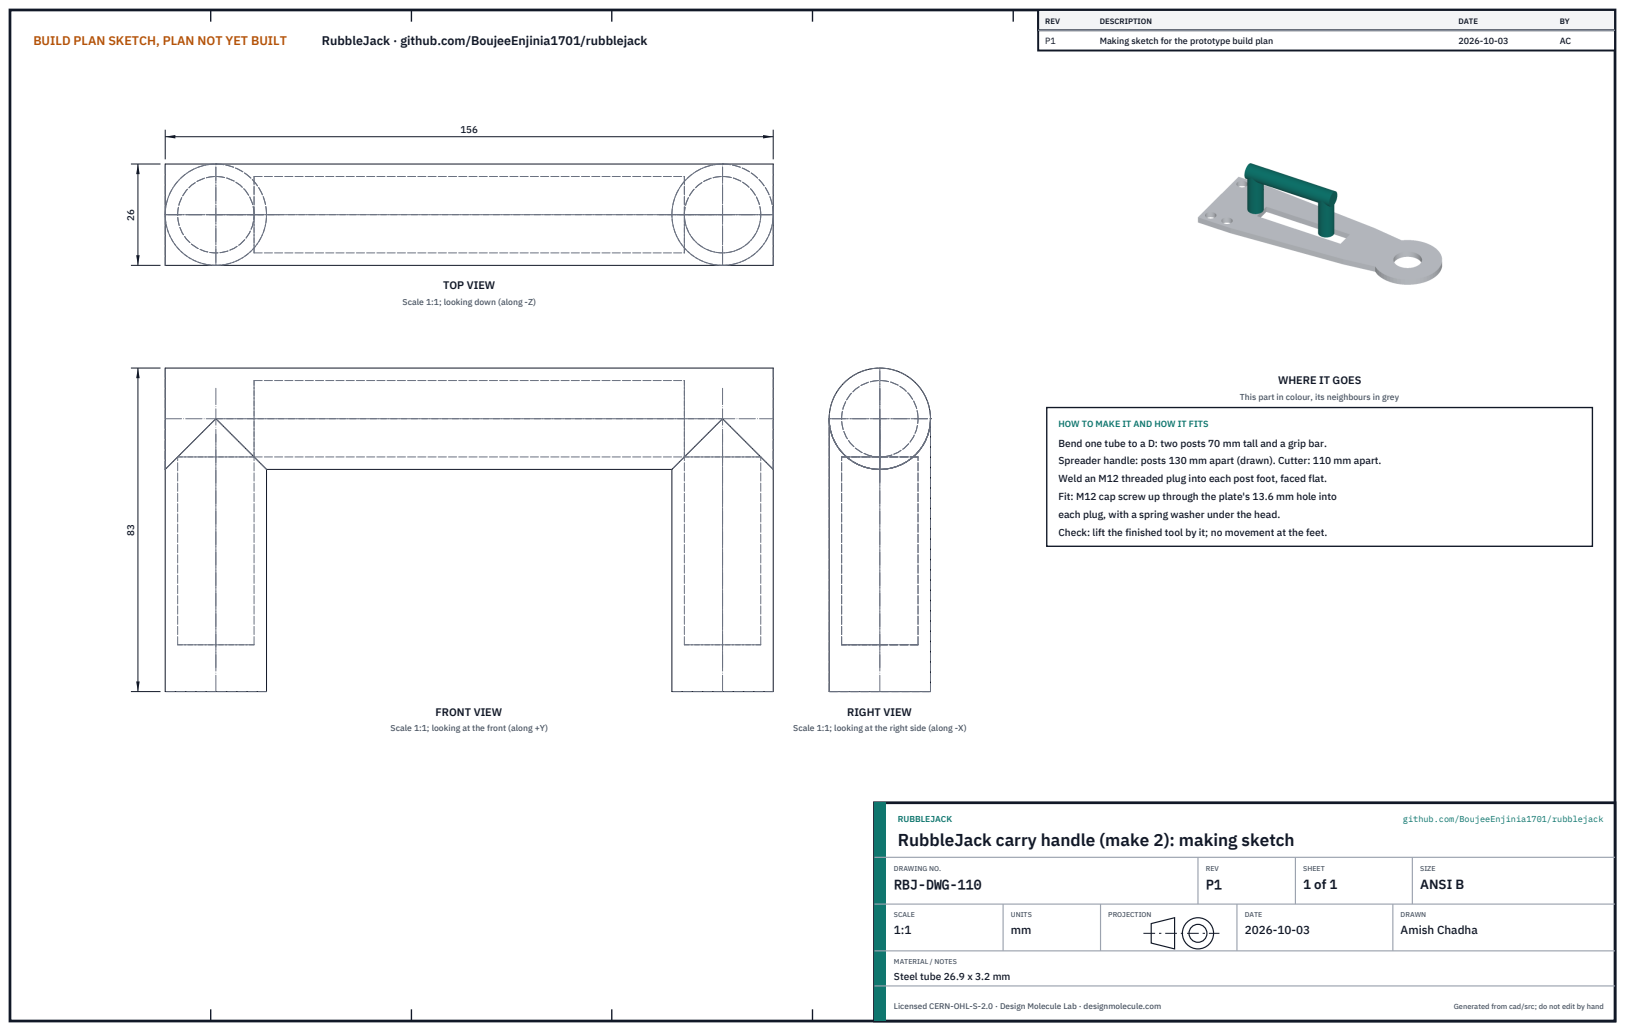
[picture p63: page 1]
BUILD PLAN SKETCH, PLAN NOT YET BUILT; RubbleJack · github.com/BoujeeEnjinia1701/rubblejack; FRONT VIEW; TOP VIEW; RIGHT VIEW; REV; DESCRIPTION; DATE; Making sketch for the prototype build plan; RUBBLEJACK; github.com/BoujeeEnjinia1701/rubblejack; DRAWING NO. RBJ-DWG-110; REV P1; SHEET 1 of 1; SIZE ANSI B; SCALE 1:1; UNITS mm; PROJECTION; DRAWN Amish Chadha; Licensed CERN-OHL-S-2.0 · Design Molecule Lab · designmolecule.com; Generated from cad/src; do not edit by hand

Scale 1:1; looking down (along -Z)

WHERE IT GOES

This part in colour, its neighbours in grey

HOW TO MAKE IT AND HOW IT FITS
Bend one tube to a D: two posts 70 mm tall and a grip bar.
Spreader handle: posts 130 mm apart (drawn). Cutter: 110 mm apart.
Weld an M12 threaded plug into each post foot, faced flat.
Fit: M12 cap screw up through the plate's 13.6 mm hole into
each plug, with a spring washer under the head.
Check: lift the finished tool by it; no movement at the feet.

Scale 1:1; looking at the front (along +Y)

Scale 1:1; looking at the right side (along -X)

RubbleJack carry handle (make 2): making sketch

MATERIAL / NOTES
Steel tube 26.9 x 3.2 mm

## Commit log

2026-10-03 RubbleJack at TRL 3: constructable design (kit 1.7.0)
    Problem, concept and requirements; sizing calculations; CAD model, STEP and STL; general arrangement drawing; bill of materials; build plan with making sketches, joint close-ups and step pictures; design decisions register (all decided under Amish's 2026-10-03 pre-approval); TRL 2 and TRL 3 review; photoreal renders and storefront card. Private until Amish opens it.
    [bom.csv, results.csv, rubblejack-cutter.step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]
2026-10-03 Carry Amish's 2026-10-03 requirement decisions into the design
    Amish chose option A on each requirement decision ("1A 2A 3A 4A 5A 6A 7A 8A 9A 10A 11A"). CampBreak: primed foot valve, pre-coupled suction hose and a drilled 30 s gather (R9 now 3.2 min at 100 m, me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

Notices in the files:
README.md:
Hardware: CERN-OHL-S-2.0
